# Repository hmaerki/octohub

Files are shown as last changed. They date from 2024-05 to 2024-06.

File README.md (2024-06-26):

# octohub

A simple usb 2.0 hub with focus on per port power switching.

Work in progress.

## Features - Hardware

* ~USD 4 when ordering 30 pieces. Fully assembled at JLCPCB.

* Kicad. Production files ready to upload to JLCPCB.

* Power control for each plug using (uhubctl)[https://github.com/mvp/uhubctl].

* **NO** manual power buttons. Many commercial hubs have buttons. If accidentely pressed, usb switching is disabled.

* Power LEDs which are visible from different angles. Many commercial switchs have LEDs, but not well visible.

* Plug numbering. Many commercial switches do not number the plugs and there is very little space left to add stickers.

## Features - Electronics

USB2 only. This makes `uhubctl` much faster.

Bus powered. Less cables is better.

USB descripter `self-powered`. This is against the USB spec. This is required as a RP2 requests 500mA. The USB 2.0 spec allows a bus-powered device to use max 100mA. The current measureed on the RP2 is only 25mA.

Over current protection. However, no over current feedback to USB.

If a device requires USB3, it is still possible to use a commercial hub.

## Current state of v0.2:

[Schematics](octohub_kicad_v0.2/production_v0.2/schematics.pdf)

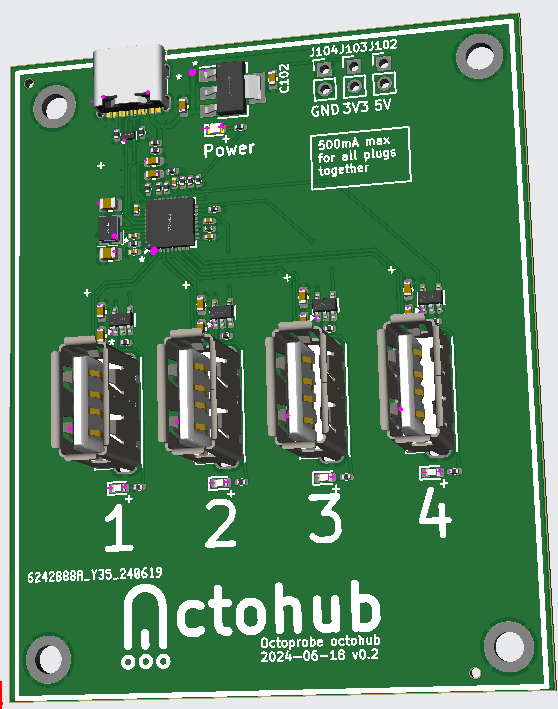
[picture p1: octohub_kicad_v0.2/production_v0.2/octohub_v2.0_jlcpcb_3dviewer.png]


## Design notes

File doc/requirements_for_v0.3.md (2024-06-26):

# Power consumtion

## RP2

| Mode | USB power descriptor | eff. power |
| - | - | - |
| Tentacle programming mode | 500 mA | 21 mA |
| SEEED run mode | 250 mA | ? |

Conclusion

One Tentacle with 1 RP2 programming and 1 RP2 run will draw 750A.

## Bus Power via selfpowered

### Bus Power

Limit 100mA, 500mA with tricks

### Self powered

Requires addition connection.

#### USB3 Powerered

* Standard cables
* USB Hub may be used as power supply

#### Custom Power cables

Variant a) Standard 6.5 mm

Power routing - USB 3

* Each tentacle has 2 USB 3 female connectors.
* The first tentacle need to be connected to a USB 3 supply.
* The followiing tentacles may be looped using USB 3 female-female cables.

Power routing - Octobus

* Some connections are reserved for 5 V power.

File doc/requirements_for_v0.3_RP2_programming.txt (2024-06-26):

Tentacle, programming mode

Bus 003 Device 060: ID 2e8a:0003 Raspberry Pi RP2 Boot
Device Descriptor:
  bLength                18
  bDescriptorType         1
  bcdUSB               1.10
  bDeviceClass            0 [unknown]
  bDeviceSubClass         0 [unknown]
  bDeviceProtocol         0 
  bMaxPacketSize0        64
  idVendor           0x2e8a Raspberry Pi
  idProduct          0x0003 RP2 Boot
  bcdDevice            1.00
  iManufacturer           1 Raspberry Pi
  iProduct                2 RP2 Boot
  iSerial                 3 E0C9125B0D9B
  bNumConfigurations      1
  Configuration Descriptor:
    bLength                 9
    bDescriptorType         2
    wTotalLength       0x0037
    bNumInterfaces          2
    bConfigurationValue     1
    iConfiguration          0 
    bmAttributes         0x80
      (Bus Powered)
    MaxPower              500mA
    Interface Descriptor:
      bLength                 9
      bDescriptorType         4
      bInterfaceNumber        0
      bAlternateSetting       0
      bNumEndpoints           2
      bInterfaceClass         8 Mass Storage
      bInterfaceSubClass      6 SCSI
      bInterfaceProtocol     80 Bulk-Only
      iInterface              0 
      Endpoint Descriptor:
        bLength                 7
        bDescriptorType         5
        bEndpointAddress     0x81  EP 1 IN
        bmAttributes            2
          Transfer Type            Bulk
          Synch Type               None
          Usage Type               Data
        wMaxPacketSize     0x0040  1x 64 bytes
        bInterval               0
      Endpoint Descriptor:
        bLength                 7
        bDescriptorType         5
        bEndpointAddress     0x02  EP 2 OUT
        bmAttributes            2
          Transfer Type            Bulk
          Synch Type               None
          Usage Type               Data
        wMaxPacketSize     0x0040  1x 64 bytes
        bInterval               0
    Interface Descriptor:
      bLength                 9
      bDescriptorType         4
      bInterfaceNumber        1
      bAlternateSetting       0
      bNumEndpoints           2
      bInterfaceClass       255 Vendor Specific Class
      bInterfaceSubClass      0 [unknown]
      bInterfaceProtocol      0 
      iInterface              0 
      Endpoint Descriptor:
        bLength                 7
        bDescriptorType         5
        bEndpointAddress     0x03  EP 3 OUT
        bmAttributes            2
          Transfer Type            Bulk
          Synch Type               None
          Usage Type               Data
        wMaxPacketSize     0x0040  1x 64 bytes
        bInterval               0
      Endpoint Descriptor:
        bLength                 7
        bDescriptorType         5
        bEndpointAddress     0x84  EP 4 IN
        bmAttributes            2
          Transfer Type            Bulk
          Synch Type               None
          Usage Type               Data
        wMaxPacketSize     0x0040  1x 64 bytes
        bInterval               0
Device Status:     0x0000
  (Bus Powered)

Bus 003 Device 065: ID 2e8a:0005 MicroPython Board in FS mode
Device Descriptor:
  bLength                18
  bDescriptorType         1
  bcdUSB               2.00
  bDeviceClass          239 Miscellaneous Device
  bDeviceSubClass         2 [unknown]
  bDeviceProtocol         1 Interface Association
  bMaxPacketSize0        64
  idVendor           0x2e8a MicroPython
  idProduct          0x0005 Board in FS mode
  bcdDevice            1.00
  iManufacturer           1 MicroPython
  iProduct                2 Board in FS mode
  iSerial                 3 4150325537323318
  bNumConfigurations      1
  Configuration Descriptor:
    bLength                 9
    bDescriptorType         2
    wTotalLength       0x004b
    bNumInterfaces          2
    bConfigurationValue     1
    iConfiguration          0 
    bmAttributes         0x80
      (Bus Powered)
    MaxPower              250mA
    Interface Association:
      bLength                 8
      bDescriptorType        11
      bFirstInterface         0
      bInterfaceCount         2
      bFunctionClass          2 Communications
      bFunctionSubClass       2 Abstract (modem)
      bFunctionProtocol       0 
      iFunction               0 
    Interface Descriptor:
      bLength                 9
      bDescriptorType         4
      bInterfaceNumber        0
      bAlternateSetting       0
      bNumEndpoints           1
      bInterfaceClass         2 Communications
      bInterfaceSubClass      2 Abstract (modem)
      bInterfaceProtocol      0 
      iInterface              4 Board CDC
      CDC Header:
        bcdCDC               1.20
      CDC Call Management:
        bmCapabilities       0x00
        bDataInterface          1
      CDC ACM:
        bmCapabilities       0x02
          line coding and serial state
      CDC Union:
        bMasterInterface        0
        bSlaveInterface         1 
      Endpoint Descriptor:
        bLength                 7
        bDescriptorType         5
        bEndpointAddress     0x81  EP 1 IN
        bmAttributes            3
          Transfer Type            Interrupt
          Synch Type               None
          Usage Type               Data
        wMaxPacketSize     0x0008  1x 8 bytes
        bInterval              16
    Interface Descriptor:
      bLength                 9
      bDescriptorType         4
      bInterfaceNumber        1
      bAlternateSetting       0
      bNumEndpoints           2
      bInterfaceClass        10 CDC Data
      bInterfaceSubClass      0 [unknown]
      bInterfaceProtocol      0 
      iInterface              0 
      Endpoint Descriptor:
        bLength                 7
        bDescriptorType         5
        bEndpointAddress     0x02  EP 2 OUT
        bmAttributes            2
          Transfer Type            Bulk
          Synch Type               None
          Usage Type               Data
        wMaxPacketSize     0x0040  1x 64 bytes
        bInterval               0
      Endpoint Descriptor:
        bLength                 7
        bDescriptorType         5
        bEndpointAddress     0x82  EP 2 IN
        bmAttributes            2
          Transfer Type            Bulk
          Synch Type               None
          Usage Type               Data
        wMaxPacketSize     0x0040  1x 64 bytes
        bInterval               0
Device Status:     0x0000
  (Bus Powered)

Bus 003 Device 066: ID f055:9800 MicroPython Pyboard Virtual Comm Port in FS Mode
Device Descriptor:
  bLength                18
  bDescriptorType         1
  bcdUSB               2.00
  bDeviceClass          239 Miscellaneous Device
  bDeviceSubClass         2 [unknown]
  bDeviceProtocol         1 Interface Association
  bMaxPacketSize0        64
  idVendor           0xf055 MicroPython
  idProduct          0x9800 Pyboard Virtual Comm Port in FS Mode
  bcdDevice            2.00
  iManufacturer           1 MicroPython
  iProduct                2 Pyboard Virtual Comm Port in FS Mode
  iSerial                 3 20853191464B
  bNumConfigurations      1
  Configuration Descriptor:
    bLength                 9
    bDescriptorType         2
    wTotalLength       0x0062
    bNumInterfaces          3
    bConfigurationValue     1
    iConfiguration          0 
    bmAttributes         0x80
      (Bus Powered)
    MaxPower              500mA
    Interface Descriptor:
      bLength                 9
      bDescriptorType         4
      bInterfaceNumber        0
      bAlternateSetting       0
      bNumEndpoints           2
      bInterfaceClass         8 Mass Storage
      bInterfaceSubClass      6 SCSI
      bInterfaceProtocol     80 Bulk-Only
      iInterface              0 
      Endpoint Descriptor:
        bLength                 7
        bDescriptorType         5
        bEndpointAddress     0x81  EP 1 IN
        bmAttributes            2
          Transfer Type            Bulk
          Synch Type               None
          Usage Type               Data
        wMaxPacketSize     0x0040  1x 64 bytes
        bInterval               0
      Endpoint Descriptor:
        bLength                 7
        bDescriptorType         5
        bEndpointAddress     0x01  EP 1 OUT
        bmAttributes            2
          Transfer Type            Bulk
          Synch Type               None
          Usage Type               Data
        wMaxPacketSize     0x0040  1x 64 bytes
        bInterval               0
    Interface Association:
      bLength                 8
      bDescriptorType        11
      bFirstInterface         1
      bInterfaceCount         2
      bFunctionClass          2 Communications
      bFunctionSubClass       2 Abstract (modem)
      bFunctionProtocol       1 AT-commands (v.25ter)
      iFunction               0 
    Interface Descriptor:
      bLength                 9
      bDescriptorType         4
      bInterfaceNumber        1
      bAlternateSetting       0
      bNumEndpoints           1
      bInterfaceClass         2 Communications
      bInterfaceSubClass      2 Abstract (modem)
      bInterfaceProtocol      1 AT-commands (v.25ter)
      iInterface              0 
      CDC Header:
        bcdCDC               1.10
      CDC Call Management:
        bmCapabilities       0x00
        bDataInterface          2
      CDC ACM:
        bmCapabilities       0x02
          line coding and serial state
      CDC Union:
        bMasterInterface        1
        bSlaveInterface         2 
      Endpoint Descriptor:
        bLength                 7
        bDescriptorType         5
        bEndpointAddress     0x82  EP 2 IN
        bmAttributes            3
          Transfer Type            Interrupt
          Synch Type               None
          Usage Type               Data
        wMaxPacketSize     0x0008  1x 8 bytes
        bInterval              32
    Interface Descriptor:
      bLength                 9
      bDescriptorType         4
      bInterfaceNumber        2
      bAlternateSetting       0
      bNumEndpoints           2
      bInterfaceClass        10 CDC Data
      bInterfaceSubClass      0 [unknown]
      bInterfaceProtocol      0 
      iInterface              0 
      Endpoint Descriptor:
        bLength                 7
        bDescriptorType         5
        bEndpointAddress     0x03  EP 3 OUT
        bmAttributes            2
          Transfer Type            Bulk
          Synch Type               None
          Usage Type               Data
        wMaxPacketSize     0x0040  1x 64 bytes
        bInterval               0
      Endpoint Descriptor:
        bLength                 7
        bDescriptorType         5
        bEndpointAddress     0x83  EP 3 IN
        bmAttributes            2
          Transfer Type            Bulk
          Synch Type               None
          Usage Type               Data
        wMaxPacketSize     0x0040  1x 64 bytes
        bInterval               0
Device Status:     0x0000
  (Bus Powered)

Bus 004 Device 001: ID 1d6b:0003 Linux Foundation 3.0 root hub
Device Descriptor:
  bLength                18
  bDescriptorType         1
  bcdUSB               3.10
  bDeviceClass            9 Hub
  bDeviceSubClass         0 [unknown]
  bDeviceProtocol         3 
  bMaxPacketSize0         9
  idVendor           0x1d6b Linux Foundation
  idProduct          0x0003 3.0 root hub
  bcdDevice            6.08
  iManufacturer           3 Linux 6.8.0-35-generic xhci-hcd
  iProduct                2 xHCI Host Controller
  iSerial                 1 0000:00:14.0
  bNumConfigurations      1
  Configuration Descriptor:
    bLength                 9
    bDescriptorType         2
    wTotalLength       0x001f
    bNumInterfaces          1
    bConfigurationValue     1
    iConfiguration          0 
    bmAttributes         0xe0
      Self Powered
      Remote Wakeup
    MaxPower                0mA
    Interface Descriptor:
      bLength                 9
      bDescriptorType         4
      bInterfaceNumber        0
      bAlternateSetting       0
      bNumEndpoints           1
      bInterfaceClass         9 Hub
      bInterfaceSubClass      0 [unknown]
      bInterfaceProtocol      0 Full speed (or root) hub
      iInterface              0 
      Endpoint Descriptor:
        bLength                 7
        bDescriptorType         5
        bEndpointAddress     0x81  EP 1 IN
        bmAttributes            3
          Transfer Type            Interrupt
          Synch Type               None
          Usage Type               Data
        wMaxPacketSize     0x0004  1x 4 bytes
        bInterval              12
        bMaxBurst               0
Binary Object Store Descriptor:
  bLength                 5
  bDescriptorType        15
  wTotalLength       0x005b
  bNumDeviceCaps          2
  SuperSpeed USB Device Capability:
    bLength                10
    bDescriptorType        16
    bDevCapabilityType      3
    bmAttributes         0x02
      Latency Tolerance Messages (LTM) Supported
    wSpeedsSupported   0x0008
      Device can operate at SuperSpeed (5Gbps)
    bFunctionalitySupport   1
      Lowest fully-functional device speed is Full Speed (12Mbps)
    bU1DevExitLat          10 micro seconds
    bU2DevExitLat         160 micro seconds
  SuperSpeedPlus USB Device Capability:
    bLength                76
    bDescriptorType        16
    bDevCapabilityType     10
    bmAttributes         0x000000ef
      Sublink Speed Attribute count 16
      Sublink Speed ID count 8
    wFunctionalitySupport   0x1106
      Min functional Speed Attribute ID: 6
      Min functional RX lanes: 1
      Min functional TX lanes: 1
    bmSublinkSpeedAttr[0]   0x00050034
      Speed Attribute ID: 4 5Gb/s Symmetric RX SuperSpeed
    bmSublinkSpeedAttr[1]   0x000500b4
      Speed Attribute ID: 4 5Gb/s Symmetric TX SuperSpeed
    bmSublinkSpeedAttr[2]   0x000a4035
      Speed Attribute ID: 5 10Gb/s Symmetric RX SuperSpeedPlus
    bmSublinkSpeedAttr[3]   0x000a40b5
      Speed Attribute ID: 5 10Gb/s Symmetric TX SuperSpeedPlus
    bmSublinkSpeedAttr[4]   0x00e00026
      Speed Attribute ID: 6 224Mb/s Symmetric RX SuperSpeed
    bmSublinkSpeedAttr[5]   0x00e000a6
      Speed Attribute ID: 6 224Mb/s Symmetric TX SuperSpeed
    bmSublinkSpeedAttr[6]   0x00c00027
      Speed Attribute ID: 7 192Mb/s Symmetric RX SuperSpeed
    bmSublinkSpeedAttr[7]   0x00c000a7
      Speed Attribute ID: 7 192Mb/s Symmetric TX SuperSpeed
    bmSublinkSpeedAttr[8]   0x00800028
      Speed Attribute ID: 8 128Mb/s Symmetric RX SuperSpeed
    bmSublinkSpeedAttr[9]   0x008000a8
      Speed Attribute ID: 8 128Mb/s Symmetric TX SuperSpeed
    bmSublinkSpeedAttr[10]   0x00b10029
      Speed Attribute ID: 9 177Mb/s Symmetric RX SuperSpeed
    bmSublinkSpeedAttr[11]   0x00b100a9
      Speed Attribute ID: 9 177Mb/s Symmetric TX SuperSpeed
    bmSublinkSpeedAttr[12]   0x0063002a
      Speed Attribute ID: 10 99Mb/s Symmetric RX SuperSpeed
    bmSublinkSpeedAttr[13]   0x006300aa
      Speed Attribute ID: 10 99Mb/s Symmetric TX SuperSpeed
    bmSublinkSpeedAttr[14]   0x00c6002b
      Speed Attribute ID: 11 198Mb/s Symmetric RX SuperSpeed
    bmSublinkSpeedAttr[15]   0x00c600ab
      Speed Attribute ID: 11 198Mb/s Symmetric TX SuperSpeed
Hub Descriptor:
  bLength              12
  bDescriptorType      42
  nNbrPorts             4
  wHubCharacteristic 0x000a
    No power switching (usb 1.0)
    Per-port overcurrent protection
  bPwrOn2PwrGood       50 * 2 milli seconds
  bHubContrCurrent      0 milli Ampere
  bHubDecLat          0.0 micro seconds
  wHubDelay             0 nano seconds
  DeviceRemovable    0x00
 Hub Port Status:
   Port 1: 0000.0263 5Gbps power suspend enable connect
     Ext Status: 0000.0044
       RX Speed Attribute ID: 4 Lanes: 1
       TX Speed Attribute ID: 4 Lanes: 1
   Port 2: 0000.02a0 5Gbps power Rx.Detect
   Port 3: 0000.02a0 5Gbps power Rx.Detect
   Port 4: 0000.02a0 5Gbps power Rx.Detect
Device Status:     0x0001
  Self Powered

Bus 004 Device 002: ID 0bda:0411 Realtek Semiconductor Corp. Hub
Device Descriptor:
  bLength                18
  bDescriptorType         1
  bcdUSB               3.20
  bDeviceClass            9 Hub
  bDeviceSubClass         0 [unknown]
  bDeviceProtocol         3 
  bMaxPacketSize0         9
  idVendor           0x0bda Realtek Semiconductor Corp.
  idProduct          0x0411 Hub
  bcdDevice            0.04
  iManufacturer           1 Generic
  iProduct                2 USB3.2 Hub
  iSerial                 0 
  bNumConfigurations      1
  Configuration Descriptor:
    bLength                 9
    bDescriptorType         2
    wTotalLength       0x001f
    bNumInterfaces          1
    bConfigurationValue     1
    iConfiguration          0 
    bmAttributes         0xe0
      Self Powered
      Remote Wakeup
    MaxPower                0mA
    Interface Descriptor:
      bLength                 9
      bDescriptorType         4
      bInterfaceNumber        0
      bAlternateSetting       0
      bNumEndpoints           1
      bInterfaceClass         9 Hub
      bInterfaceSubClass      0 [unknown]
      bInterfaceProtocol      0 Full speed (or root) hub
      iInterface              0 
      Endpoint Descriptor:
        bLength                 7
        bDescriptorType         5
        bEndpointAddress     0x81  EP 1 IN
        bmAttributes           19
          Transfer Type            Interrupt
          Synch Type               None
          Usage Type               Feedback
        wMaxPacketSize     0x0002  1x 2 bytes
        bInterval               8
        bMaxBurst               0
Binary Object Store Descriptor:
  bLength                 5
  bDescriptorType        15
  wTotalLength       0x002a
  bNumDeviceCaps          3
  USB 2.0 Extension Device Capability:
    bLength                 7
    bDescriptorType        16
    bDevCapabilityType      2
    bmAttributes   0x0000f41e
      BESL Link Power Management (LPM) Supported
    BESL value     1024 us 
    Deep BESL value    61440 us 
  SuperSpeed USB Device Capability:
    bLength                10
    bDescriptorType        16
    bDevCapabilityType      3
    bmAttributes         0x00
    wSpeedsSupported   0x000e
      Device can operate at Full Speed (12Mbps)
      Device can operate at High Speed (480Mbps)
      Device can operate at SuperSpeed (5Gbps)
    bFunctionalitySupport   1
      Lowest fully-functional device speed is Full Speed (12Mbps)
    bU1DevExitLat          10 micro seconds
    bU2DevExitLat        1023 micro seconds
  Container ID Device Capability:
    bLength                20
    bDescriptorType        16
    bDevCapabilityType      4
    bReserved               0
    ContainerID             {20b9cde5-7039-e011-a935-0002a5d5c51b}
Hub Descriptor:
  bLength              12
  bDescriptorType      42
  nNbrPorts             4
  wHubCharacteristic 0x0009
    Per-port power switching
    Per-port overcurrent protection
  bPwrOn2PwrGood        0 * 2 milli seconds
  bHubContrCurrent      8 milli Ampere
  bHubDecLat          0.2 micro seconds
  wHubDelay          3202 nano seconds
  DeviceRemovable    0x00
 Hub Port Status:
   Port 1: 0000.02a0 5Gbps power Rx.Detect
   Port 2: 0000.02a0 5Gbps power Rx.Detect
   Port 3: 0000.0263 5Gbps power suspend enable connect
   Port 4: 0000.0263 5Gbps power suspend enable connect
Device Status:     0x000d
  Self Powered
  U1 Enabled
  U2 Enabled

Bus 004 Device 003: ID 0bda:0411 Realtek Semiconductor Corp. Hub
Device Descriptor:
  bLength                18
  bDescriptorType         1
  bcdUSB               3.20
  bDeviceClass            9 Hub
  bDeviceSubClass         0 [unknown]
  bDeviceProtocol         3 
  bMaxPacketSize0         9
  idVendor           0x0bda Realtek Semiconductor Corp.
  idProduct          0x0411 Hub
  bcdDevice            0.04
  iManufacturer           1 Generic
  iProduct                2 USB3.2 Hub
  iSerial                 0 
  bNumConfigurations      1
  Configuration Descriptor:
    bLength                 9
    bDescriptorType         2
    wTotalLength       0x001f
    bNumInterfaces          1
    bConfigurationValue     1
    iConfiguration          0 
    bmAttributes         0xe0
      Self Powered
      Remote Wakeup
    MaxPower                0mA
    Interface Descriptor:
      bLength                 9
      bDescriptorType         4
      bInterfaceNumber        0
      bAlternateSetting       0
      bNumEndpoints           1
      bInterfaceClass         9 Hub
      bInterfaceSubClass      0 [unknown]
      bInterfaceProtocol      0 Full speed (or root) hub
      iInterface              0 
      Endpoint Descriptor:
        bLength                 7
        bDescriptorType         5
        bEndpointAddress     0x81  EP 1 IN
        bmAttributes           19
          Transfer Type            Interrupt
          Synch Type               None
          Usage Type               Feedback
        wMaxPacketSize     0x0002  1x 2 bytes
        bInterval               8
        bMaxBurst               0
Binary Object Store Descriptor:
  bLength                 5
  bDescriptorType        15
  wTotalLength       0x002a
  bNumDeviceCaps          3
  USB 2.0 Extension Device Capability:
    bLength                 7
    bDescriptorType        16
    bDevCapabilityType      2
    bmAttributes   0x0000f41e
      BESL Link Power Management (LPM) Supported
    BESL value     1024 us 
    Deep BESL value    61440 us 
  SuperSpeed USB Device Capability:
    bLength                10
    bDescriptorType        16
    bDevCapabilityType      3
    bmAttributes         0x00
    wSpeedsSupported   0x000e
      Device can operate at Full Speed (12Mbps)
      Device can operate at High Speed (480Mbps)
      Device can operate at SuperSpeed (5Gbps)
    bFunctionalitySupport   1
      Lowest fully-functional device speed is Full Speed (12Mbps)
    bU1DevExitLat          10 micro seconds
    bU2DevExitLat        1023 micro seconds
  Container ID Device Capability:
    bLength                20
    bDescriptorType        16
    bDevCapabilityType      4
    bReserved               0
    ContainerID             {20b9cde5-7039-e011-a935-0002a5d5c51b}
Hub Descriptor:
  bLength              12
  bDescriptorType      42
  nNbrPorts             4
  wHubCharacteristic 0x0009
    Per-port power switching
    Per-port overcurrent protection
  bPwrOn2PwrGood        0 * 2 milli seconds
  bHubContrCurrent      8 milli Ampere
  bHubDecLat          0.2 micro seconds
  wHubDelay          3202 nano seconds
  DeviceRemovable    0x00
 Hub Port Status:
   Port 1: 0000.02a0 5Gbps power Rx.Detect
   Port 2: 0000.02a0 5Gbps power Rx.Detect
   Port 3: 0000.02a0 5Gbps power Rx.Detect
   Port 4: 0000.02a0 5Gbps power Rx.Detect
Device Status:     0x000d
  Self Powered
  U1 Enabled
  U2 Enabled

Bus 004 Device 004: ID 0bda:0411 Realtek Semiconductor Corp. Hub
Device Descriptor:
  bLength                18
  bDescriptorType         1
  bcdUSB               3.20
  bDeviceClass            9 Hub
  bDeviceSubClass         0 [unknown]
  bDeviceProtocol         3 
  bMaxPacketSize0         9
  idVendor           0x0bda Realtek Semiconductor Corp.
  idProduct          0x0411 Hub
  bcdDevice            0.04
  iManufacturer           1 Generic
  iProduct                2 USB3.2 Hub
  iSerial                 0 
  bNumConfigurations      1
  Configuration Descriptor:
    bLength                 9
    bDescriptorType         2
    wTotalLength       0x001f
    bNumInterfaces          1
    bConfigurationValue     1
    iConfiguration          0 
    bmAttributes         0xe0
      Self Powered
      Remote Wakeup
    MaxPower                0mA
    Interface Descriptor:
      bLength                 9
      bDescriptorType         4
      bInterfaceNumber        0
      bAlternateSetting       0
      bNumEndpoints           1
      bInterfaceClass         9 Hub
      bInterfaceSubClass      0 [unknown]
      bInterfaceProtocol      0 Full speed (or root) hub
      iInterface              0 
      Endpoint Descriptor:
        bLength                 7
        bDescriptorType         5
        bEndpointAddress     0x81  EP 1 IN
        bmAttributes           19
          Transfer Type            Interrupt
          Synch Type               None
          Usage Type               Feedback
        wMaxPacketSize     0x0002  1x 2 bytes
        bInterval               8
        bMaxBurst               0
Binary Object Store Descriptor:
  bLength                 5
  bDescriptorType        15
  wTotalLength       0x002a
  bNumDeviceCaps          3
  USB 2.0 Extension Device Capability:
    bLength                 7
    bDescriptorType        16
    bDevCapabilityType      2
    bmAttributes   0x0000f41e
      BESL Link Power Management (LPM) Supported
    BESL value     1024 us 
    Deep BESL value    61440 us 
  SuperSpeed USB Device Capability:
    bLength                10
    bDescriptorType        16
    bDevCapabilityType      3
    bmAttributes         0x00
    wSpeedsSupported   0x000e
      Device can operate at Full Speed (12Mbps)
      Device can operate at High Speed (480Mbps)
      Device can operate at SuperSpeed (5Gbps)
    bFunctionalitySupport   1
      Lowest fully-functional device speed is Full Speed (12Mbps)
    bU1DevExitLat          10 micro seconds
    bU2DevExitLat        1023 micro seconds
  Container ID Device Capability:
    bLength                20
    bDescriptorType        16
    bDevCapabilityType      4
    bReserved               0
    ContainerID             {20b9cde5-7039-e011-a935-0002a5d5c51b}
Hub Descriptor:
  bLength              12
  bDescriptorType      42
  nNbrPorts             4
  wHubCharacteristic 0x0009
    Per-port power switching
    Per-port overcurrent protection
  bPwrOn2PwrGood        0 * 2 milli seconds
  bHubContrCurrent      8 milli Ampere
  bHubDecLat          0.2 micro seconds
  wHubDelay          3202 nano seconds
  DeviceRemovable    0x00
 Hub Port Status:
   Port 1: 0000.02a0 5Gbps power Rx.Detect
   Port 2: 0000.02a0 5Gbps power Rx.Detect
   Port 3: 0000.02a0 5Gbps power Rx.Detect
   Port 4: 0000.02a0 5Gbps power Rx.Detect
Device Status:     0x000d
  Self Powered
  U1 Enabled
  U2 Enabled

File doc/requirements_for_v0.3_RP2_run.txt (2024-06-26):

RP2 SEEED

[   97.388628] usb 3-1: new full-speed USB device number 5 using xhci_hcd
[   97.517740] usb 3-1: New USB device found, idVendor=2e8a, idProduct=0005, bcdDevice= 1.00
[   97.517780] usb 3-1: New USB device strings: Mfr=1, Product=2, SerialNumber=3
[   97.517784] usb 3-1: Product: Board in FS mode
[   97.517787] usb 3-1: Manufacturer: MicroPython
[   97.517790] usb 3-1: SerialNumber: 4150325537323318
[   97.551115] cdc_acm 3-1:1.0: ttyACM0: USB ACM device
[   97.551186] usbcore: registered new interface driver cdc_acm
[   97.551192] cdc_acm: USB Abstract Control Model driver for USB modems and ISDN adapters

root@maerki-ideapad-320:/tmp# lsusb -tv
/:  Bus 001.Port 001: Dev 001, Class=root_hub, Driver=xhci_hcd/1p, 480M
    ID 1d6b:0002 Linux Foundation 2.0 root hub
/:  Bus 002.Port 001: Dev 001, Class=root_hub, Driver=xhci_hcd/4p, 10000M
    ID 1d6b:0003 Linux Foundation 3.0 root hub
/:  Bus 003.Port 001: Dev 001, Class=root_hub, Driver=xhci_hcd/12p, 480M
    ID 1d6b:0002 Linux Foundation 2.0 root hub
    |__ Port 001: Dev 005, If 0, Class=Communications, Driver=cdc_acm, 12M    <===============
        ID 2e8a:0005  
    |__ Port 001: Dev 005, If 1, Class=CDC Data, Driver=cdc_acm, 12M
        ID 2e8a:0005  
    |__ Port 003: Dev 002, If 0, Class=Vendor Specific Class, Driver=[none], 12M
        ID 06cb:00f9 Synaptics, Inc. 
    |__ Port 004: Dev 003, If 0, Class=Video, Driver=uvcvideo, 480M
        ID 13d3:5405 IMC Networks 
    |__ Port 004: Dev 003, If 1, Class=Video, Driver=uvcvideo, 480M
        ID 13d3:5405 IMC Networks 
    |__ Port 004: Dev 003, If 2, Class=Video, Driver=uvcvideo, 480M
        ID 13d3:5405 IMC Networks 
    |__ Port 004: Dev 003, If 3, Class=Video, Driver=uvcvideo, 480M
        ID 13d3:5405 IMC Networks 
    |__ Port 004: Dev 003, If 4, Class=Application Specific Interface, Driver=[none], 480M
        ID 13d3:5405 IMC Networks 
/:  Bus 004.Port 001: Dev 001, Class=root_hub, Driver=xhci_hcd/4p, 10000M
    ID 1d6b:0003 Linux Foundation 3.0 root hub

Bus 003 Device 005: ID 2e8a:0005 MicroPython Board in FS mode
Device Descriptor:
  bLength                18
  bDescriptorType         1
  bcdUSB               2.00
  bDeviceClass          239 Miscellaneous Device
  bDeviceSubClass         2 [unknown]
  bDeviceProtocol         1 Interface Association
  bMaxPacketSize0        64
  idVendor           0x2e8a MicroPython
  idProduct          0x0005 Board in FS mode
  bcdDevice            1.00
  iManufacturer           1 MicroPython
  iProduct                2 Board in FS mode
  iSerial                 3 4150325537323318
  bNumConfigurations      1
  Configuration Descriptor:
    bLength                 9
    bDescriptorType         2
    wTotalLength       0x004b
    bNumInterfaces          2
    bConfigurationValue     1
    iConfiguration          0 
    bmAttributes         0x80
      (Bus Powered)
    MaxPower              250mA
    Interface Association:
      bLength                 8
      bDescriptorType        11
      bFirstInterface         0
      bInterfaceCount         2
      bFunctionClass          2 Communications
      bFunctionSubClass       2 Abstract (modem)
      bFunctionProtocol       0 
      iFunction               0 
    Interface Descriptor:
      bLength                 9
      bDescriptorType         4
      bInterfaceNumber        0
      bAlternateSetting       0
      bNumEndpoints           1
      bInterfaceClass         2 Communications
      bInterfaceSubClass      2 Abstract (modem)
      bInterfaceProtocol      0 
      iInterface              4 Board CDC
      CDC Header:
        bcdCDC               1.20
      CDC Call Management:
        bmCapabilities       0x00
        bDataInterface          1
      CDC ACM:
        bmCapabilities       0x02
          line coding and serial state
      CDC Union:
        bMasterInterface        0
        bSlaveInterface         1 
      Endpoint Descriptor:
        bLength                 7
        bDescriptorType         5
        bEndpointAddress     0x81  EP 1 IN
        bmAttributes            3
          Transfer Type            Interrupt
          Synch Type               None
          Usage Type               Data
        wMaxPacketSize     0x0008  1x 8 bytes
        bInterval              16
    Interface Descriptor:
      bLength                 9
      bDescriptorType         4
      bInterfaceNumber        1
      bAlternateSetting       0
      bNumEndpoints           2
      bInterfaceClass        10 CDC Data
      bInterfaceSubClass      0 [unknown]
      bInterfaceProtocol      0 
      iInterface              0 
      Endpoint Descriptor:
        bLength                 7
        bDescriptorType         5
        bEndpointAddress     0x02  EP 2 OUT
        bmAttributes            2
          Transfer Type            Bulk
          Synch Type               None
          Usage Type               Data
        wMaxPacketSize     0x0040  1x 64 bytes
        bInterval               0
      Endpoint Descriptor:
        bLength                 7
        bDescriptorType         5
        bEndpointAddress     0x82  EP 2 IN
        bmAttributes            2
          Transfer Type            Bulk
          Synch Type               None
          Usage Type               Data
        wMaxPacketSize     0x0040  1x 64 bytes
        bInterval               0
Device Status:     0x0000
  (Bus Powered)

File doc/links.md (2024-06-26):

## Sparkfun

https://github.com/sparkfunX/Qwiic_USB_Hub-USB2514B
https://www.sparkfun.com/products/18014
Known Issues: The power control MOSFETs on this version (x02) are not functional. While each port is on by default, they cannot be turned off in software.

[Schematics](https://github.com/sparkfunX/Qwiic_USB_Hub-USB2514B/blob/main/Hardware/Qwiic-USB_Hub.pdf)

## Carrier board for the Raspberry Pi Compute Module

https://hackaday.io/project/165108-carrier-board-for-the-raspberry-pi-compute-module

BOM: https://cdn.hackaday.io/files/1651087063980672/BOM.xlsx

## Microchip

* https://www.microchip.com/en-us/product/usb2514b
* https://ww1.microchip.com/downloads/aemDocuments/documents/OTH/ProductDocuments/DataSheets/00001692C.pdf

* (Layout Guilde)[https://ww1.microchip.com/downloads/aemDocuments/documents/OTH/ApplicationNotes/ApplicationNotes/en562810.pdf]

### Eval board EVB-USB2514B-FS FULL SPEED (12Mbits/s)
* (EVB-USB2514B-FS)[https://www.microchip.com/en-us/development-tool/evb-usb2514b-fs]
* (Schematics)[https://ww1.microchip.com/downloads/aemDocuments/documents/OTH/ProductDocuments/BoardDesignFiles/EVB-USB2514B-FS_A1EvaluationBoardSchematicPDF.pdf]
* (BOM)[https://ww1.microchip.com/downloads/aemDocuments/documents/OTH/ProductDocuments/BoardDesignFiles/EVB-USB2514B-FS_A1EvaluationBoardBillofMaterials.xls]

### Eval board EVB-USB2514BC HIGH SPEED (480Mbits/s)
* (EVB-USB2514BC)[https://www.microchip.com/en-us/development-tool/EVB-USB2514BC] 
* (Schematics)[https://ww1.microchip.com/downloads/aemDocuments/documents/OTH/ProductDocuments/BoardDesignFiles/EVB-USB2514BC_A3-sch.pdf]
* (BOM)[https://ww1.microchip.com/downloads/aemDocuments/documents/OTH/ProductDocuments/BoardDesignFiles/EVB-USB2514BC_A3-Bom.xls]

### Seeed - reTerminal

* (Intro)[https://wiki.seeedstudio.com/reTerminal_Intro]
* (Schematics)[https://files.seeedstudio.com/wiki/ReTerminal/reTerminal-v1.3_SCH.pdf]

### PcbWay

https://www.pcbway.com/project/shareproject/USB2514_HUB.html

## USB

https://www.cuidevices.com/blog/an-introduction-to-power-only-usb-type-c-connectors

https://en.wikipedia.org/wiki/USB-C

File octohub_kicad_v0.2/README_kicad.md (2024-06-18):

# Plugins used

* https://github.com/bennymeg/JLC-Plugin-for-KiCad

  JLC PCB Plug-in for KiCad

  Fill Symbol Field `JLC Part`

* https://github.com/MitjaNemec/ReplicateLayout

## Protype Baord

### Precondition

...

## Hierarchical sheet

* https://forum.kicad.info/t/variables-in-hierarchical-sheet-labels/41978

In pcb, place all relais footprints (silkscreen) correctly.

Select first pcb, `Tools -> External Plugins -> Replicate Layout`

## Replicate Layout

* Reference Layout `pcb_octohub_cip.kicad_sch`: `chip_upstream`
  * Reference footprint: USB Chip
  * UR201 `+` spawns the top left corner

* Reference Layout `pcb_octohub_plug.kicad_sch`: `hub4-1/plug_A`
  * Reference footprint: Plug
  * UR1201 is the plug label
  * UR1202 `+` spawns the top left corner

* Reference Layout `pcb_octohub_hub4.kicad_sch`: `hub4-1`
  * Reference footprint: UR1001 `+`
  * UR1001 `+` spawns the top left corner

## Production

### In schematics

Menu `Inspect -> Electrical Rule Chacker`, button `Run ERC`, No violatons

### Increment version number

Update in all sheets

### In pcb - final check and final commit

Menu `Tools -> Update PCB from Schematic`, only one error `Error: Multiple footprings found for 'PB101'`

Menu `Tools -> Cleanup Tracks & Vias`, select all,  `Build Changes`, No violatons

Menu `Inspect -> Design Rules Chacker`, check `Refill all zones`, button `Run DRC . No errors, no warnings.

Delete all files in directory `production`.

Icon `Fabricaton Toolkit`, Options empty, check `Apply automatic translatons`, UNcheck `Exluce DNP components`.

Rename production folder and add version number

### Print schematics

Schematics, Menu `File -> Print`, check 'Print drawing sheet - Color`, `Print`, `All Pages`, `Pirnt to File`.

Move `~/Documents/output.pdf` to `hardware/octoprobe_kicad_v1/production_v2.0/schematics.pdf`

### Upload to JLCPCB

See: octohub_kicad_v0.2/production_v0.2/README_production_v0.2.md

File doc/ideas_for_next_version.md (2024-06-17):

# Ideas

## 4 port hub versus 16 port hub

| 4 port | 16 port | Comment |
| :-: | :-: | - |
| | no usb configuration | uhubctl |
| simple| | Kicad project / jlcpcb order |
| more power | | upstream hub may support power |
| | simple, one pcb | Mechanics |
| flexible | | octoprobe arrangement |
| | plugs numbered from 1..16 | octoprobe arrangement |
| multipe power switches | | Power |

## Multiple power switches

* separate MT9700
* PRTPWR connects to MT9700
* MT9700 VIN: Experiment Plugs
* MT9700 VOUT: Experiment Plugs

According to datasheet
* VIN must be provided: 3V3 or 5V
* Max current: 2A

==> Goal: Switch

## Evaluate Relais

* Octoprobe
  * GAQY221S
  * https://wmsc.lcsc.com/wmsc/upload/file/pdf/v2/lcsc/2308151358_SUPSiC-GAQY221S_C7435105.pdf
  * USD 055

JLC search: `solid state relay MOS supsic`

| JLC |  USD | U Load R | Type | Datasheet |
| :-: | :-: | :-: | - | - |
| C393898 | 1.9 | 60V 1A 250m | TOSHIBA TLP3122(TP,F) | https://wmsc.lcsc.com/wmsc/upload/file/pdf/v2/lcsc/1912111437_TOSHIBA-TLP3122-TP-F_C393898.pdf |
| C19271987 | 0.6 | 60V 1.8A 70m | SUPSiC GAQY212GHA | https://wmsc.lcsc.com/wmsc/upload/file/pdf/v2/lcsc/2403241735_SUPSiC-GAQY212GHA_C19271987.pdf |
| C192C743510471987 | 0.74 | 40V 2.5A 60m | SUPSiC GAQY211G2S | https://wmsc.lcsc.com/wmsc/upload/file/pdf/v2/lcsc/2308151358_SUPSiC-GAQY211G2S_C7435104.pdf |

## Other open source hub. USB2, tested with uhubctl.

https://oshwlab.com/iamseer/ch335-hub

CH335F, jlc C5137013, USD 1.2

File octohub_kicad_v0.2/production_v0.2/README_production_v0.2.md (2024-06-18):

JLCPCB: Error while uploading : The below parts won't be assembled due to data missing.
H102,H101,H104,H103 designators don't exist in the CPL file.

JLCPCB: Postprocess
 * Rotate U101, U1101

Price

| Qty | Total USD | Unit USD |
| :-: | :-: | :-: |
| 5 | 48 | 9.6 |
| 10 | 63 | 6.3 |
| 20 | 100 | 10 |
| 30 | 130 | 4.3 |

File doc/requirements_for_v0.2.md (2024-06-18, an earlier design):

# Requirements for v0.2

## Design

* Selfpowered via USBC connector. See (schematics)[https://ww1.microchip.com/downloads/aemDocuments/documents/OTH/ProductDocuments/BoardDesignFiles/EVB-USB2514B-FS_A1EvaluationBoardSchematicPDF.pdf]
* 1 Hub per PCB
* PCB may be connected to Multihub

## Measuring

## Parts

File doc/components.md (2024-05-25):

## XTAL

### https://ww1.microchip.com/downloads/aemDocuments/documents/OTH/ProductDocuments/BoardDesignFiles/EVB-USB2514BC_A3-Bom.xls

`Y1	Crystal, 24.000MHz, 50ppm, 18pF, HC-49SMT	Citizen America	HCM49-24.000MABJ-UT`

==> JLC not available

### https://ww1.microchip.com/downloads/aemDocuments/documents/OTH/ProductDocuments/BoardDesignFiles/EVB-USB2514BC_A3-Bom.xls

`Y1	Crystal, 24.000MHz, 50ppm, 18pF, HC-49SMT	Citizen America	HCM49-24.000MABJ-UT`

==> JLC not available

### https://ww1.microchip.com/downloads/aemDocuments/documents/OTH/ProductDocuments/DataSheets/00001692C.pdf

```
7.1 Oscillator/Crystal
Crystal: Parallel resonant, fundamental mode, 24 MHz 350 ppm
```

https://jlcpcb.com/partdetail/Yxc-X322524MOB4SI/C70590

`24MHz Surface mount crystal oscillator 12pF ±10ppm ±20ppm SMD3225-4P Crystals ROHS`

## USB Connector

* C456015: Only 2 supporting pads. No kicad footprint
  * 20k Stock, USD 0.03

* https://jlcpcb.com/partdetail/Molex-1050570001/C586225
  * 18 Stock, USD 0.6

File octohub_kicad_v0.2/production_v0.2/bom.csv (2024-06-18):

Designator | Footprint | Quantity | Value | LCSC Part #
C101, C102, C1201, C1202, C1301, C1302, C1401, C1402, C1501, C1502 | 0603 | 10 | 10u
C103, C1102 | 0603 | 2 | 100n
C1101, C1103, C1104, C1105 | 0402 | 4 | 100n
C1106, C1107 | 0805 | 2 | 18p | C1797
C1108, C1109 | 0402 | 2 | 0.1u
D101 | Texas_USON-6_1x1.45mm_P0.5mm_SMD | 1 | PRTR5V0U2X | C2937001
D102 | 0603 | 1 | LED GREEN | C2297
D1201, D1301, D1401, D1501 | 0603 | 4 | LED WHITE | C2290
H101, H102, H103, H104 | MountingHole_3.2mm_M3_DIN965_Pad | 4 | octoprobe_MountingHole
J101 | USB_C_Receptacle_Palconn_UTC16-G | 1 | USB_C_Receptacle_USB2.0 | C165948
J1201, J1301, J1401, J1501 | USB_A_SHOUHAN_Vertical | 4 | USB_A | C456015
R101, R102 | 0402 | 2 | 5.1K
R103, R104, R1101, R1102, R1103, R1105 | 0402 | 6 | 100k
R105 | 0402 | 1 | 470R
R1104 | 0402 | 1 | 12k
R1106, R1107, R1108, R1109, R1110, R1201, R1301, R1401, R1501 | 0402 | 9 | 10k
R1202, R1302, R1402, R1502 | 0402 | 4 | 1k
U101 | SOT-223-3_TabPin2 | 1 | AMS1117-3.3 | C6186
U1101 | Texas_RHH0036C_VQFN-36-1EP_6x6mm_P0.5mm_EP4.4x4.4mm_ThermalVias | 1 | USB2514B_Bi | C16251
U1201, U1301, U1401, U1501 | SOT-23-5 | 4 | MT9700 | C89855
Y1101 | Crystal_SMD_3225-4Pin_3.2x2.5mm | 1 | 24MHz | C70590

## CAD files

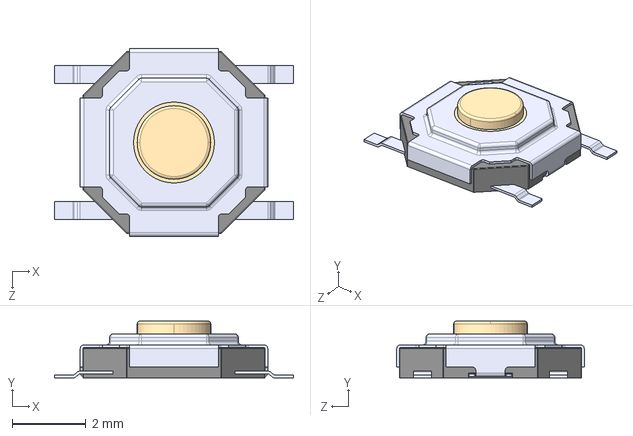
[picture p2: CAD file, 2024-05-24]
octohub_kicad_v0.2/00_project_parts/bizcard/footprints/TS-1187A-B-A-B.step
6.50 x 1.55 x 5.10 mm

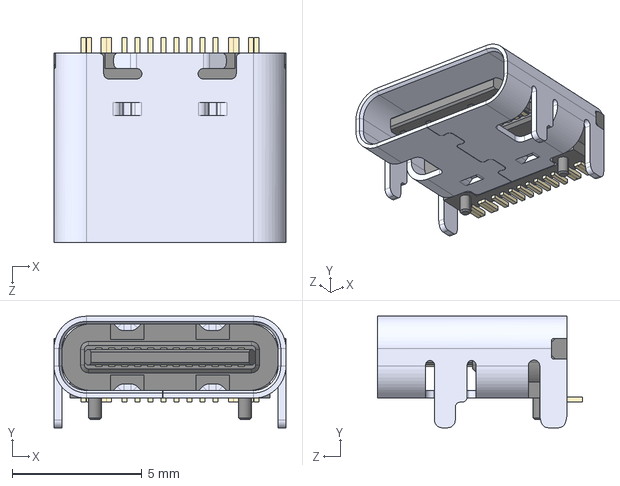
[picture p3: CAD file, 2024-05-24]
octohub_kicad_v0.2/00_project_parts/bizcard/footprints/TYPE-C-31-M-12--3DModel-STEP-56544.STEP
8.94 x 4.30 x 7.90 mm

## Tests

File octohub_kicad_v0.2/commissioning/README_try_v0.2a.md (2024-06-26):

# Commisioning

Serial 1: Remove R1106 (CFG_SEL[1])

Now the hub is self-powered!

## CFG_SEL[1], pin 25

Currently: `0 self powererd`
New: `1 bus powered`

## Observations

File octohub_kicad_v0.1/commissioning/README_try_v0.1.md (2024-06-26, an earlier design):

# Commisioning

Serial 1. Remove R212 (failed to add R208)

`sudo dmesg --follow`

```
[  962.101187] usb 3-1: new high-speed USB device number 28 using xhci_hcd
[  962.228270] usb 3-1: New USB device found, idVendor=0424, idProduct=2514, bcdDevice= b.b3
[  962.228276] usb 3-1: New USB device strings: Mfr=0, Product=0, SerialNumber=0
[  962.229811] hub 3-1:1.0: USB hub found
[  962.229854] hub 3-1:1.0: 4 ports detected
```

`sudo uhubctl`

```
Current status for hub 3-5.3 [0424:2514, USB 2.00, 4 ports, ppps]
  Port 1: 0103 power enable connect [2e8a:0003 Raspberry Pi RP2 Boot E0C9125B0D9B]
  Port 2: 0103 power enable connect [2e8a:0005 MicroPython Board in FS mode 4150325537323318]
  Port 3: 0100 power
  Port 4: 0100 power
```

```bash
uhubctl -l 3-5.3 --action=on
Current status for hub 3-5.3 [0424:2514, USB 2.00, 4 ports, ppps]
  Port 1: 0000 off
  Port 2: 0000 off
  Port 3: 0000 off
  Port 4: 0000 off
Sent power on request
New status for hub 3-5.3 [0424:2514, USB 2.00, 4 ports, ppps]
  Port 1: 0100 power
  Port 2: 0100 power
  Port 3: 0100 power
  Port 4: 0100 power
```

`lsusb -v`

```
Bus 003 Device 025: ID 0424:2514 Microchip Technology, Inc. (formerly SMSC) USB 2.0 Hub
Device Descriptor:
  bLength                18
  bDescriptorType         1
  bcdUSB               2.00
  bDeviceClass            9 Hub
  bDeviceSubClass         0 [unknown]
  bDeviceProtocol         2 TT per port
  bMaxPacketSize0        64
  idVendor           0x0424 Microchip Technology, Inc. (formerly SMSC)
  idProduct          0x2514 USB 2.0 Hub
  bcdDevice            b.b3
  iManufacturer           0 
  iProduct                0 
  iSerial                 0 
  bNumConfigurations      1
  Configuration Descriptor:
    bLength                 9
    bDescriptorType         2
    wTotalLength       0x0029
    bNumInterfaces          1
    bConfigurationValue     1
    iConfiguration          0 
    bmAttributes         0xe0
      Self Powered         <=========================
      Remote Wakeup
    MaxPower                2mA
    Interface Descriptor:
      bLength                 9
      bDescriptorType         4
      bInterfaceNumber        0
      bAlternateSetting       0
      bNumEndpoints           1
      bInterfaceClass         9 Hub
      bInterfaceSubClass      0 [unknown]
      bInterfaceProtocol      1 Single TT
      iInterface              0 
      Endpoint Descriptor:
        bLength                 7
        bDescriptorType         5
        bEndpointAddress     0x81  EP 1 IN
        bmAttributes            3
          Transfer Type            Interrupt
          Synch Type               None
          Usage Type               Data
        wMaxPacketSize     0x0001  1x 1 bytes
        bInterval              12
    Interface Descriptor:
      bLength                 9
      bDescriptorType         4
      bInterfaceNumber        0
      bAlternateSetting       1
      bNumEndpoints           1
      bInterfaceClass         9 Hub
      bInterfaceSubClass      0 [unknown]
      bInterfaceProtocol      2 TT per port
      iInterface              0 
      Endpoint Descriptor:
        bLength                 7
        bDescriptorType         5
        bEndpointAddress     0x81  EP 1 IN
        bmAttributes            3
          Transfer Type            Interrupt
          Synch Type               None
          Usage Type               Data
        wMaxPacketSize     0x0001  1x 1 bytes
        bInterval              12
Hub Descriptor:
  bLength               9
  bDescriptorType      41
  nNbrPorts             4
  wHubCharacteristic 0x000d
    Per-port power switching
    Compound device
    Per-port overcurrent protection
    TT think time 8 FS bits
  bPwrOn2PwrGood       50 * 2 milli seconds
  bHubContrCurrent      1 milli Ampere
  DeviceRemovable    0x02
  PortPwrCtrlMask    0xff
 Hub Port Status:
   Port 1: 0000.0100 power
   Port 2: 0000.0100 power
   Port 3: 0000.0100 power
   Port 4: 0000.0100 power
Device Qualifier (for other device speed):
  bLength                10
  bDescriptorType         6
  bcdUSB               2.00
  bDeviceClass            9 Hub
  bDeviceSubClass         0 [unknown]
  bDeviceProtocol         0 Full speed (or root) hub
  bMaxPacketSize0        64
  bNumConfigurations      1
Device Status:     0x0001
  Self Powered         <=========================
```

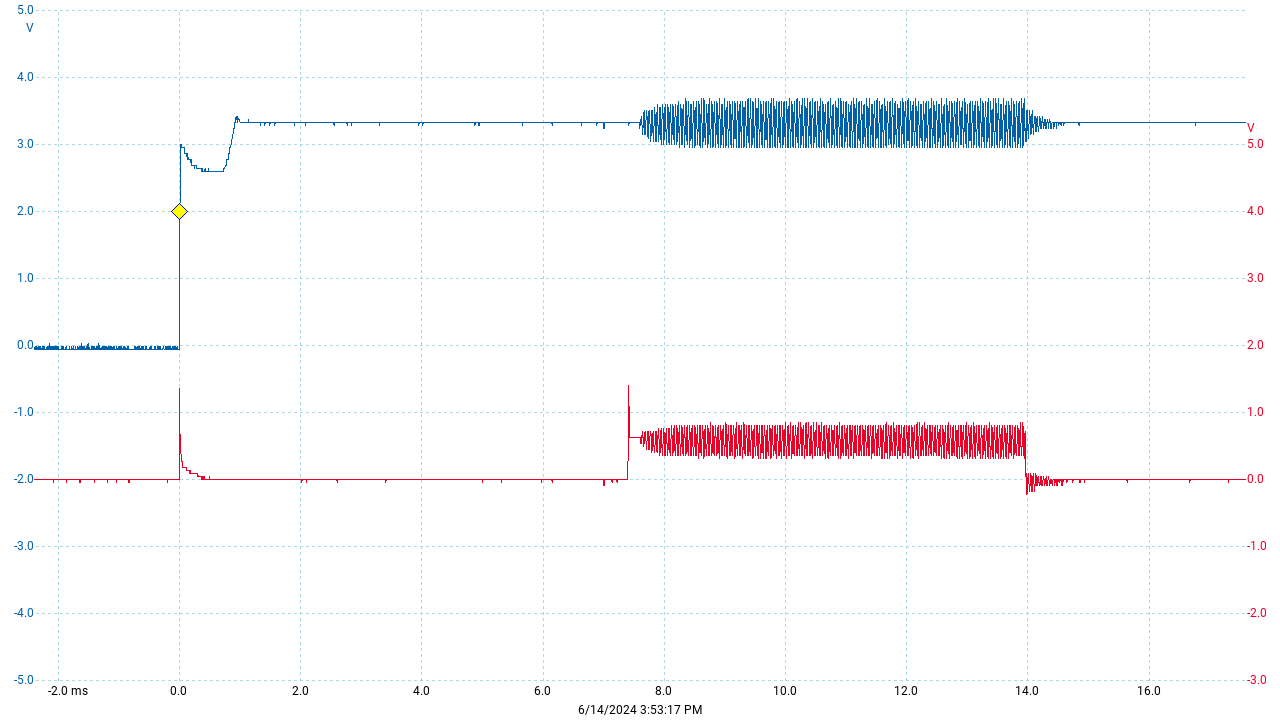
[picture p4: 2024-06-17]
octohub_kicad_v0.2/commissioning/README_try_v0.1b/R216_XTALOUT_c.png

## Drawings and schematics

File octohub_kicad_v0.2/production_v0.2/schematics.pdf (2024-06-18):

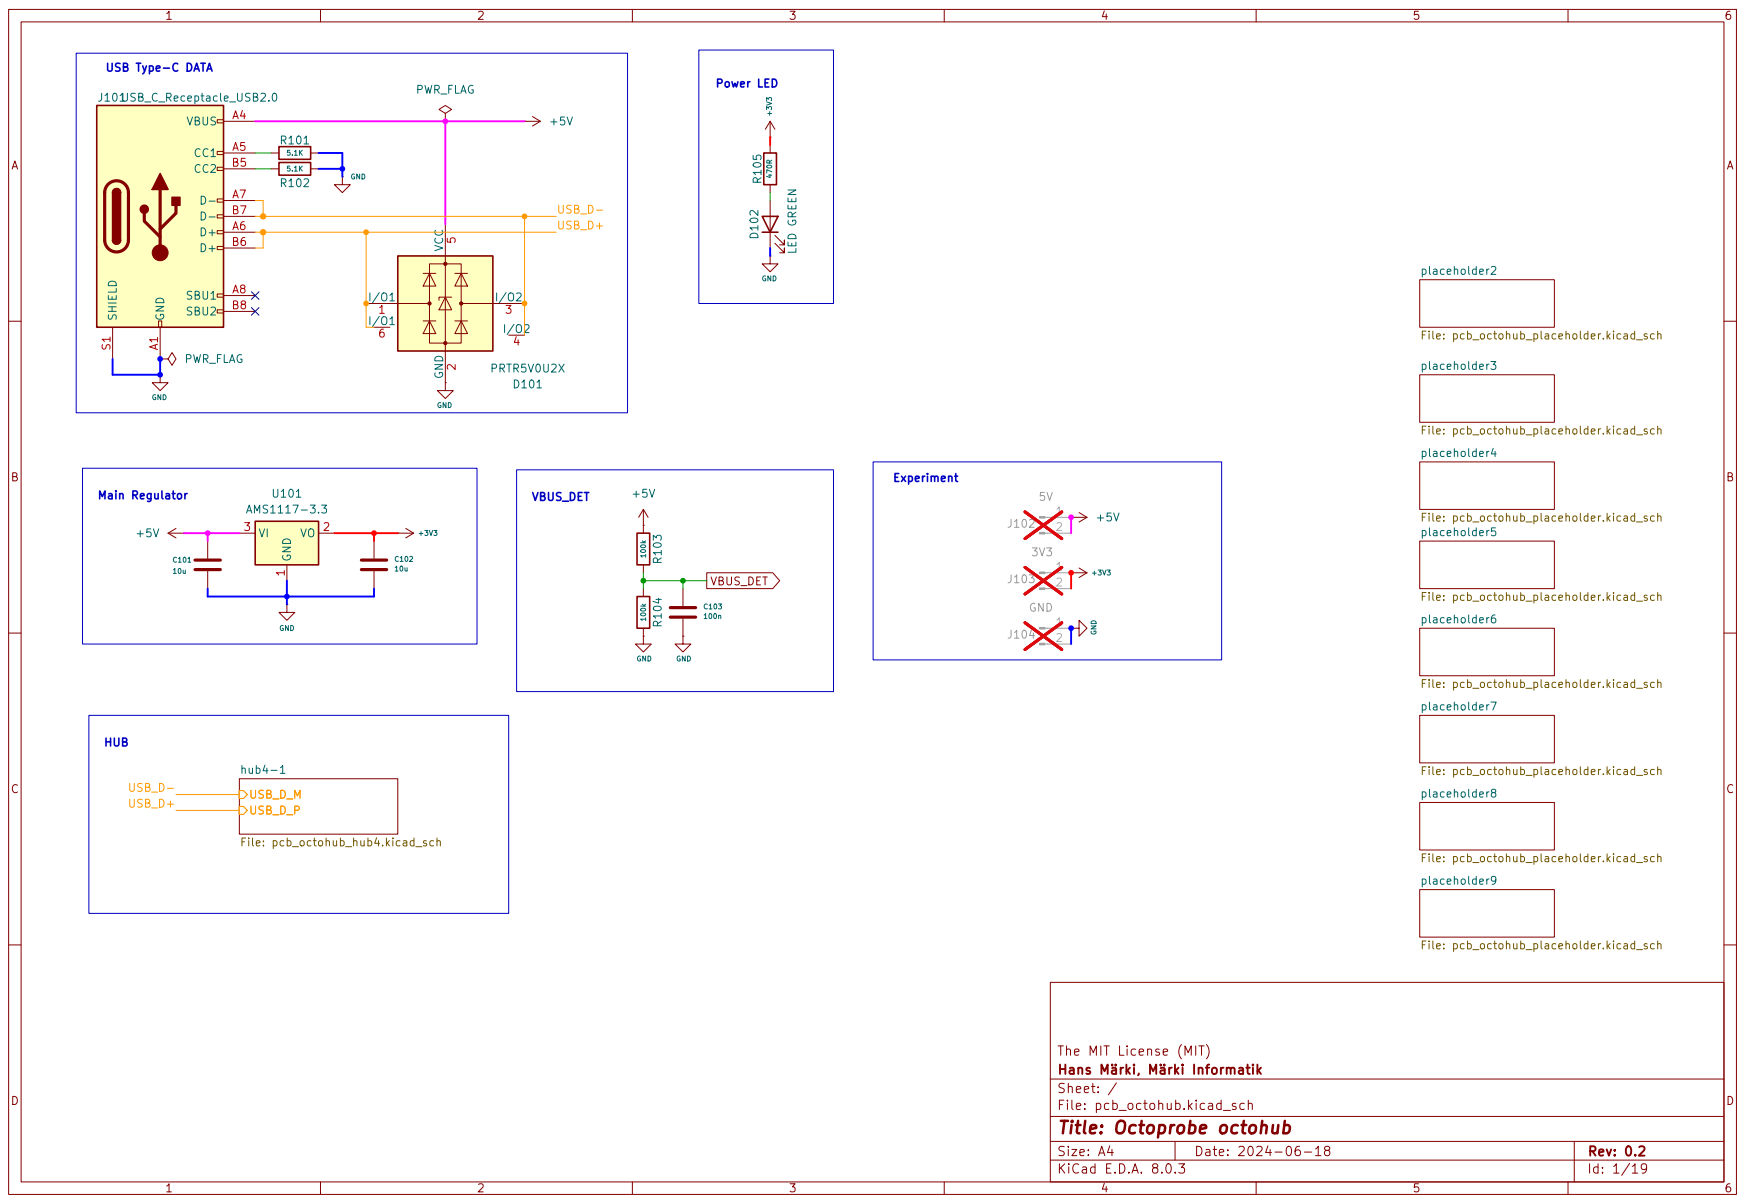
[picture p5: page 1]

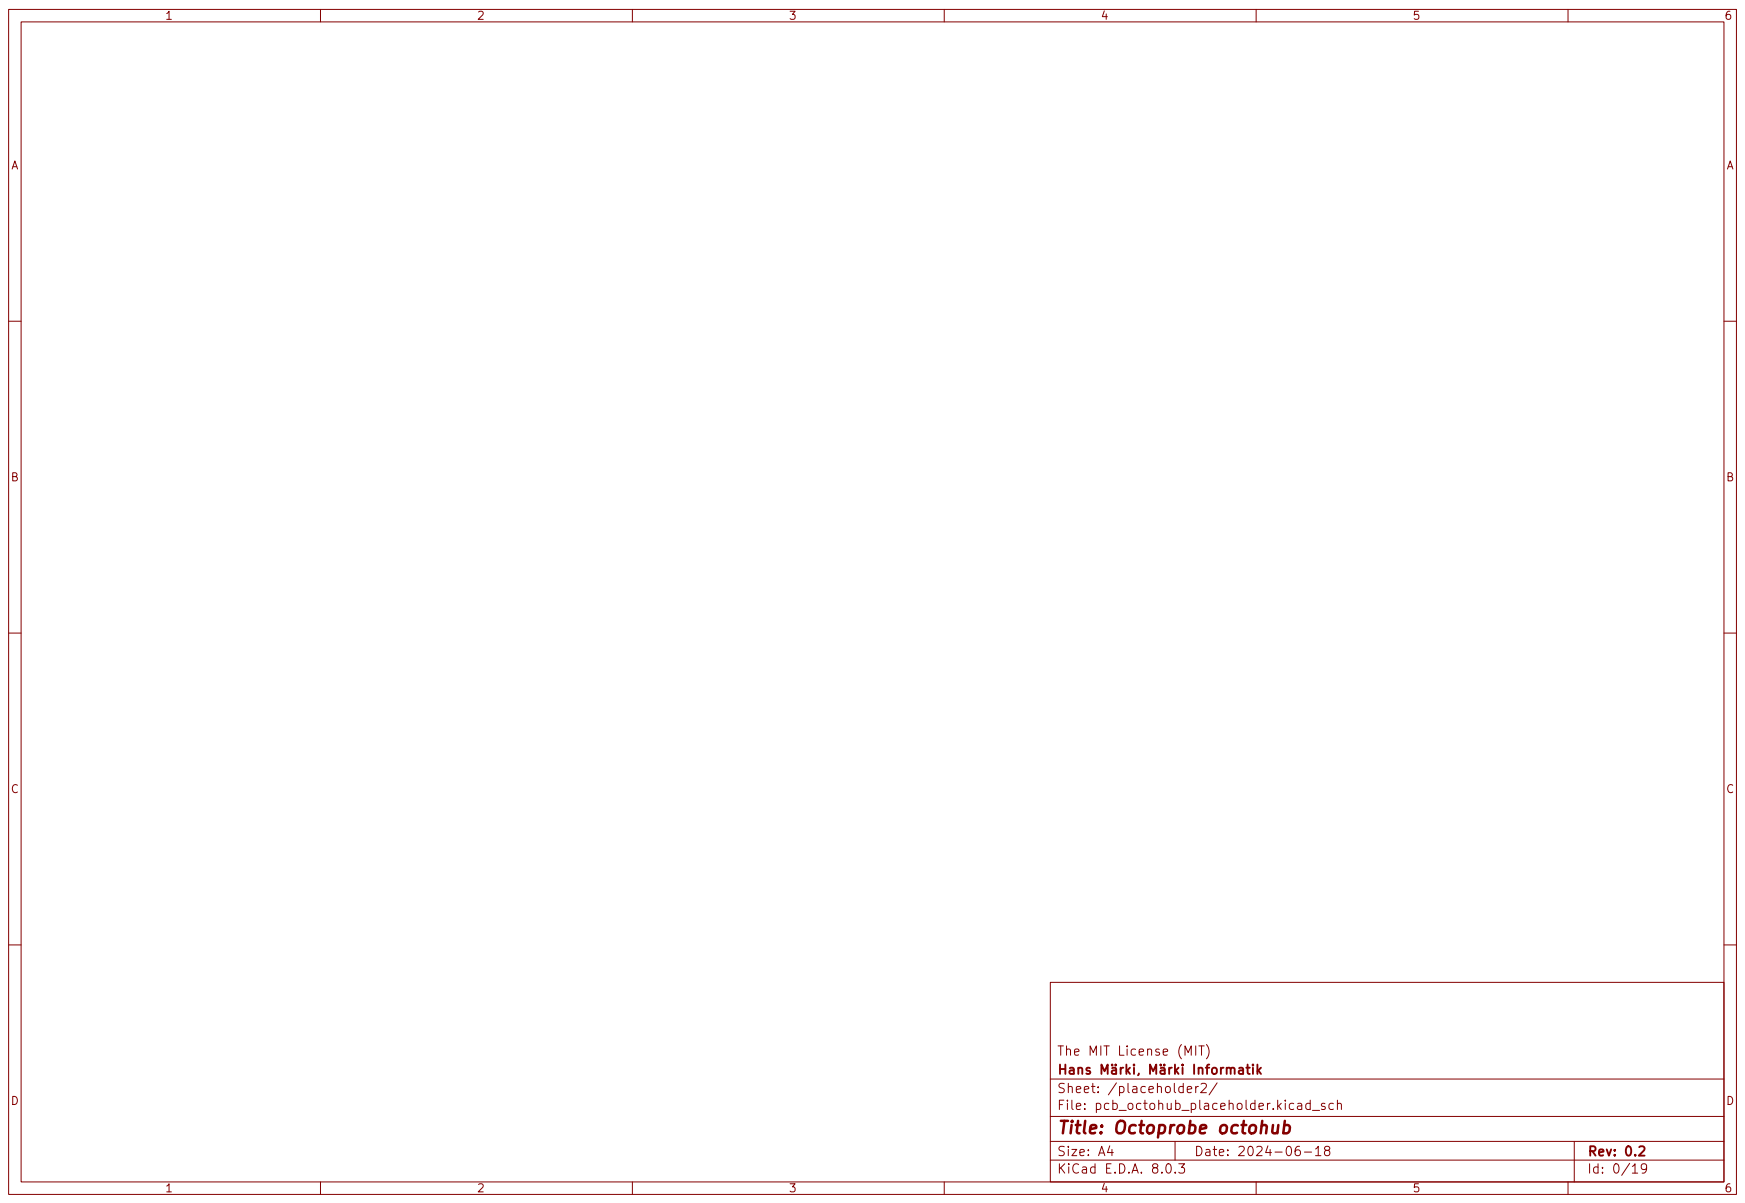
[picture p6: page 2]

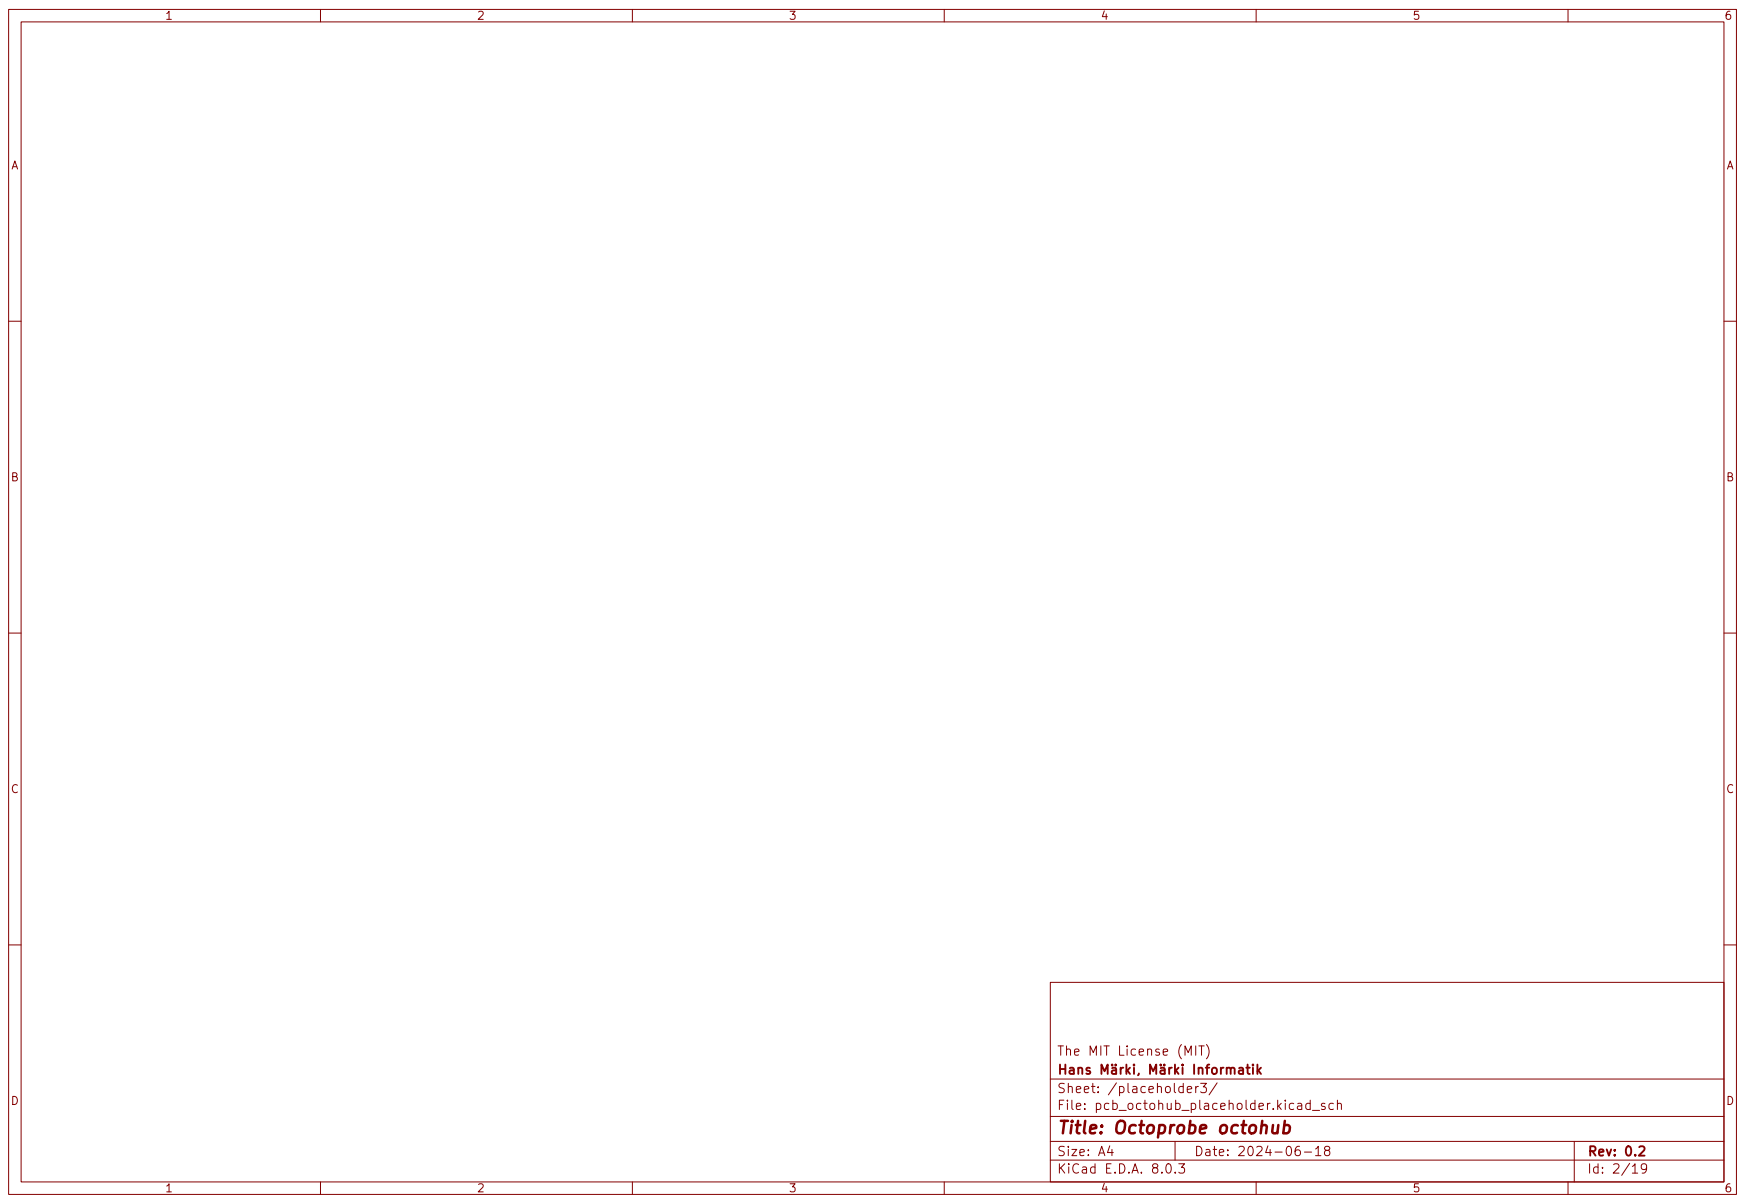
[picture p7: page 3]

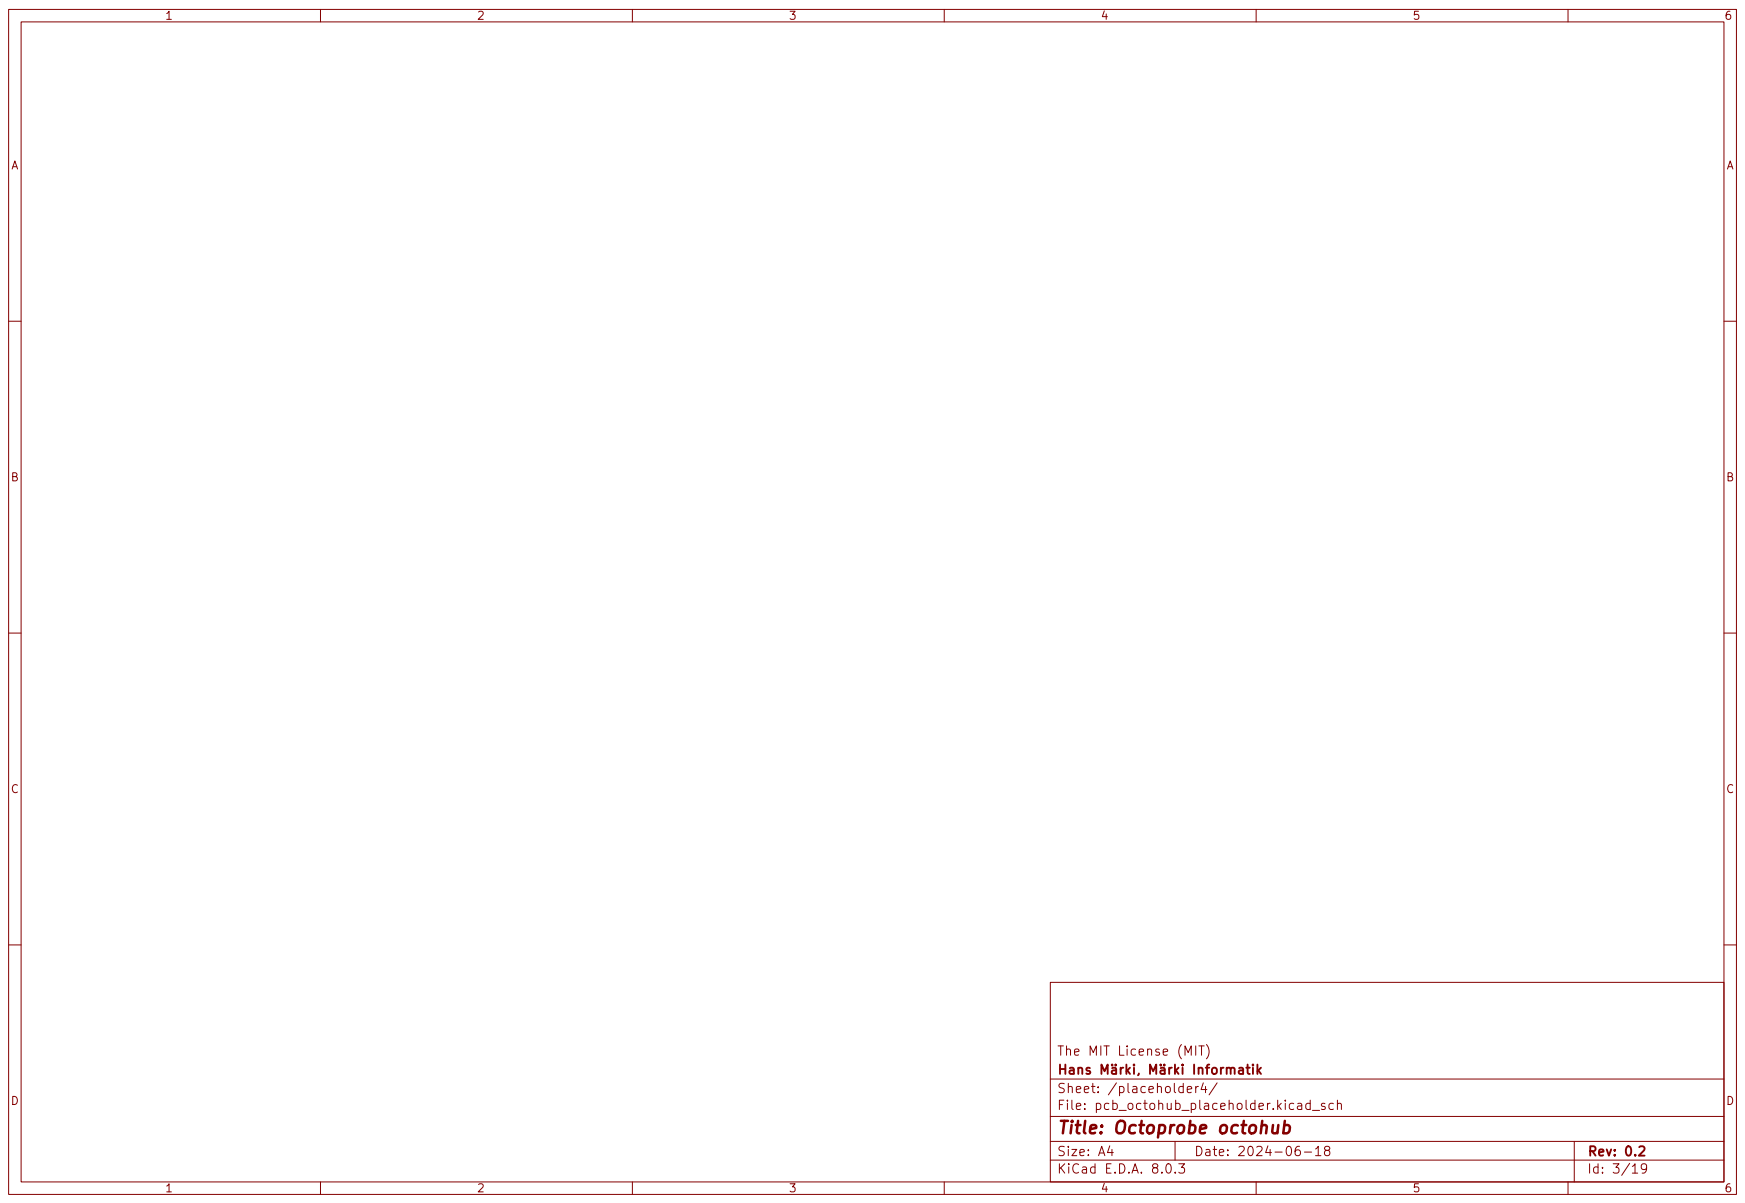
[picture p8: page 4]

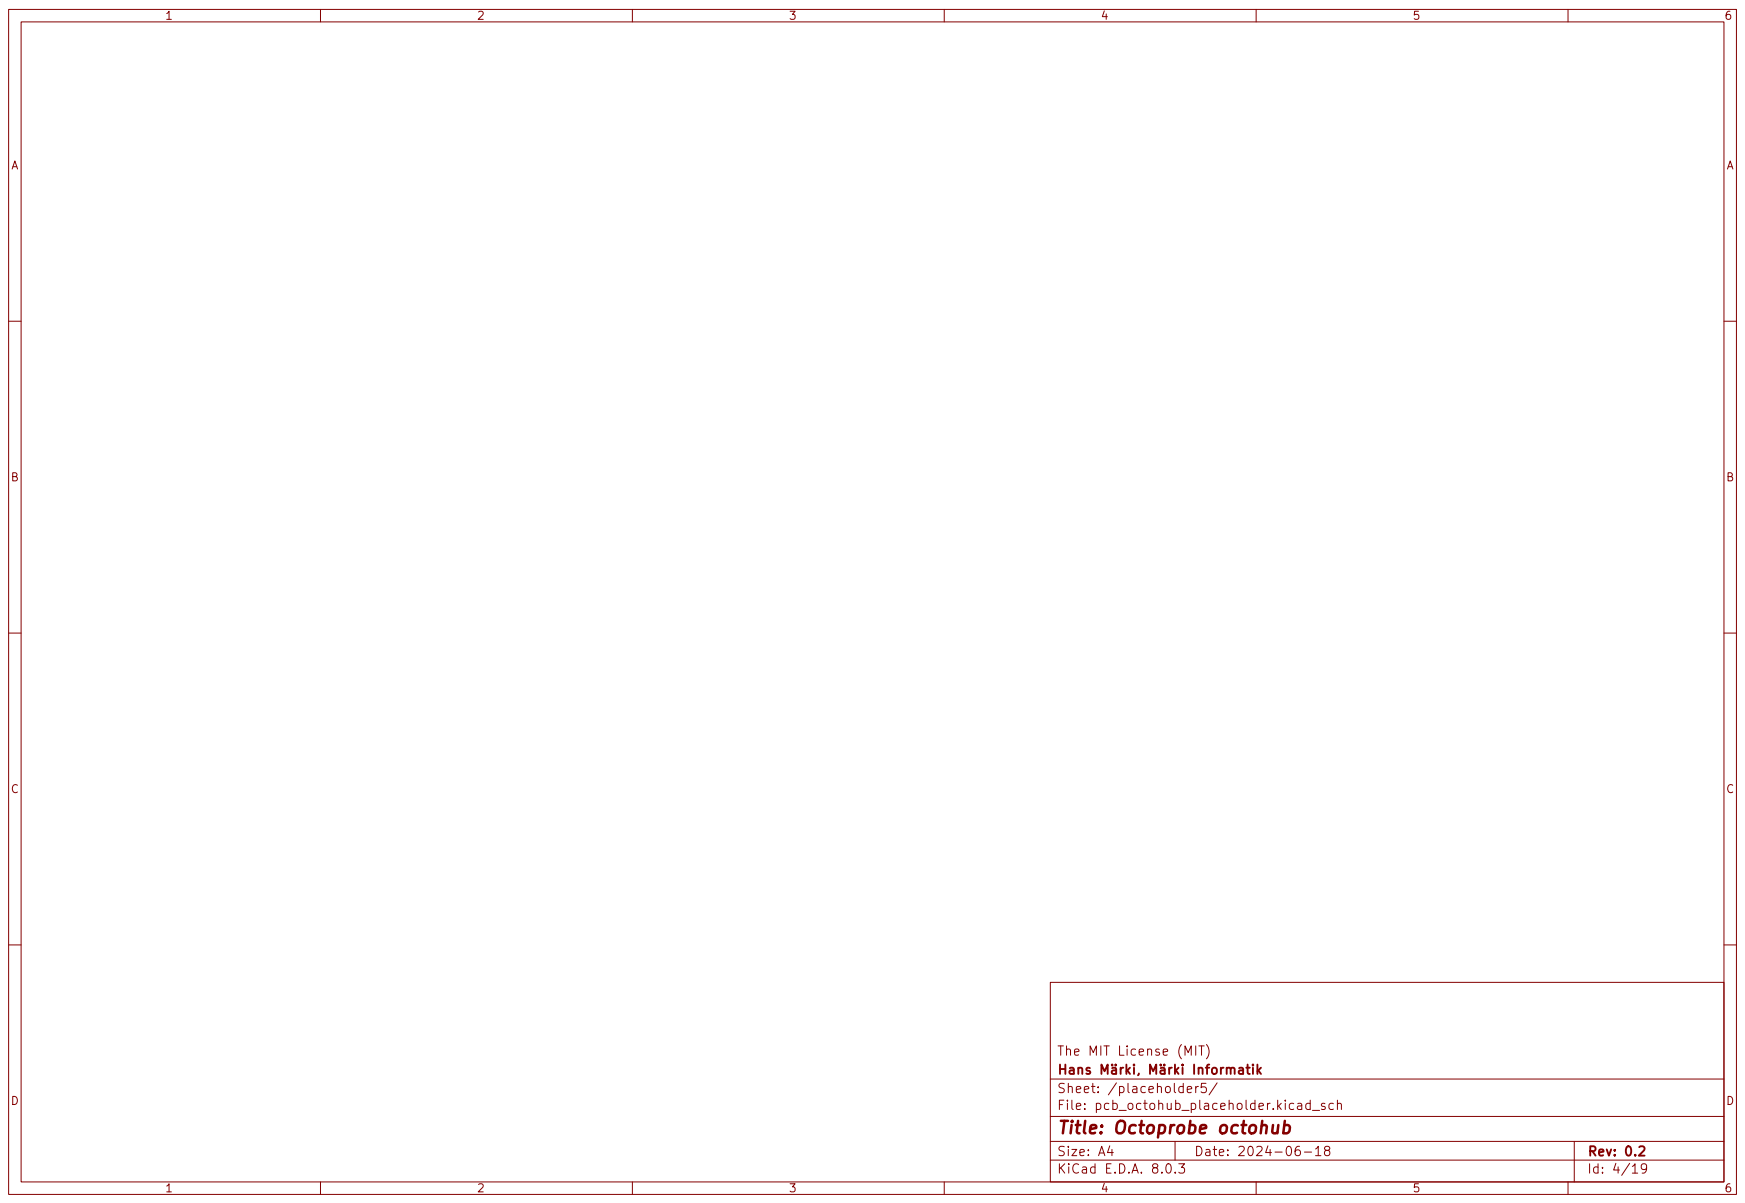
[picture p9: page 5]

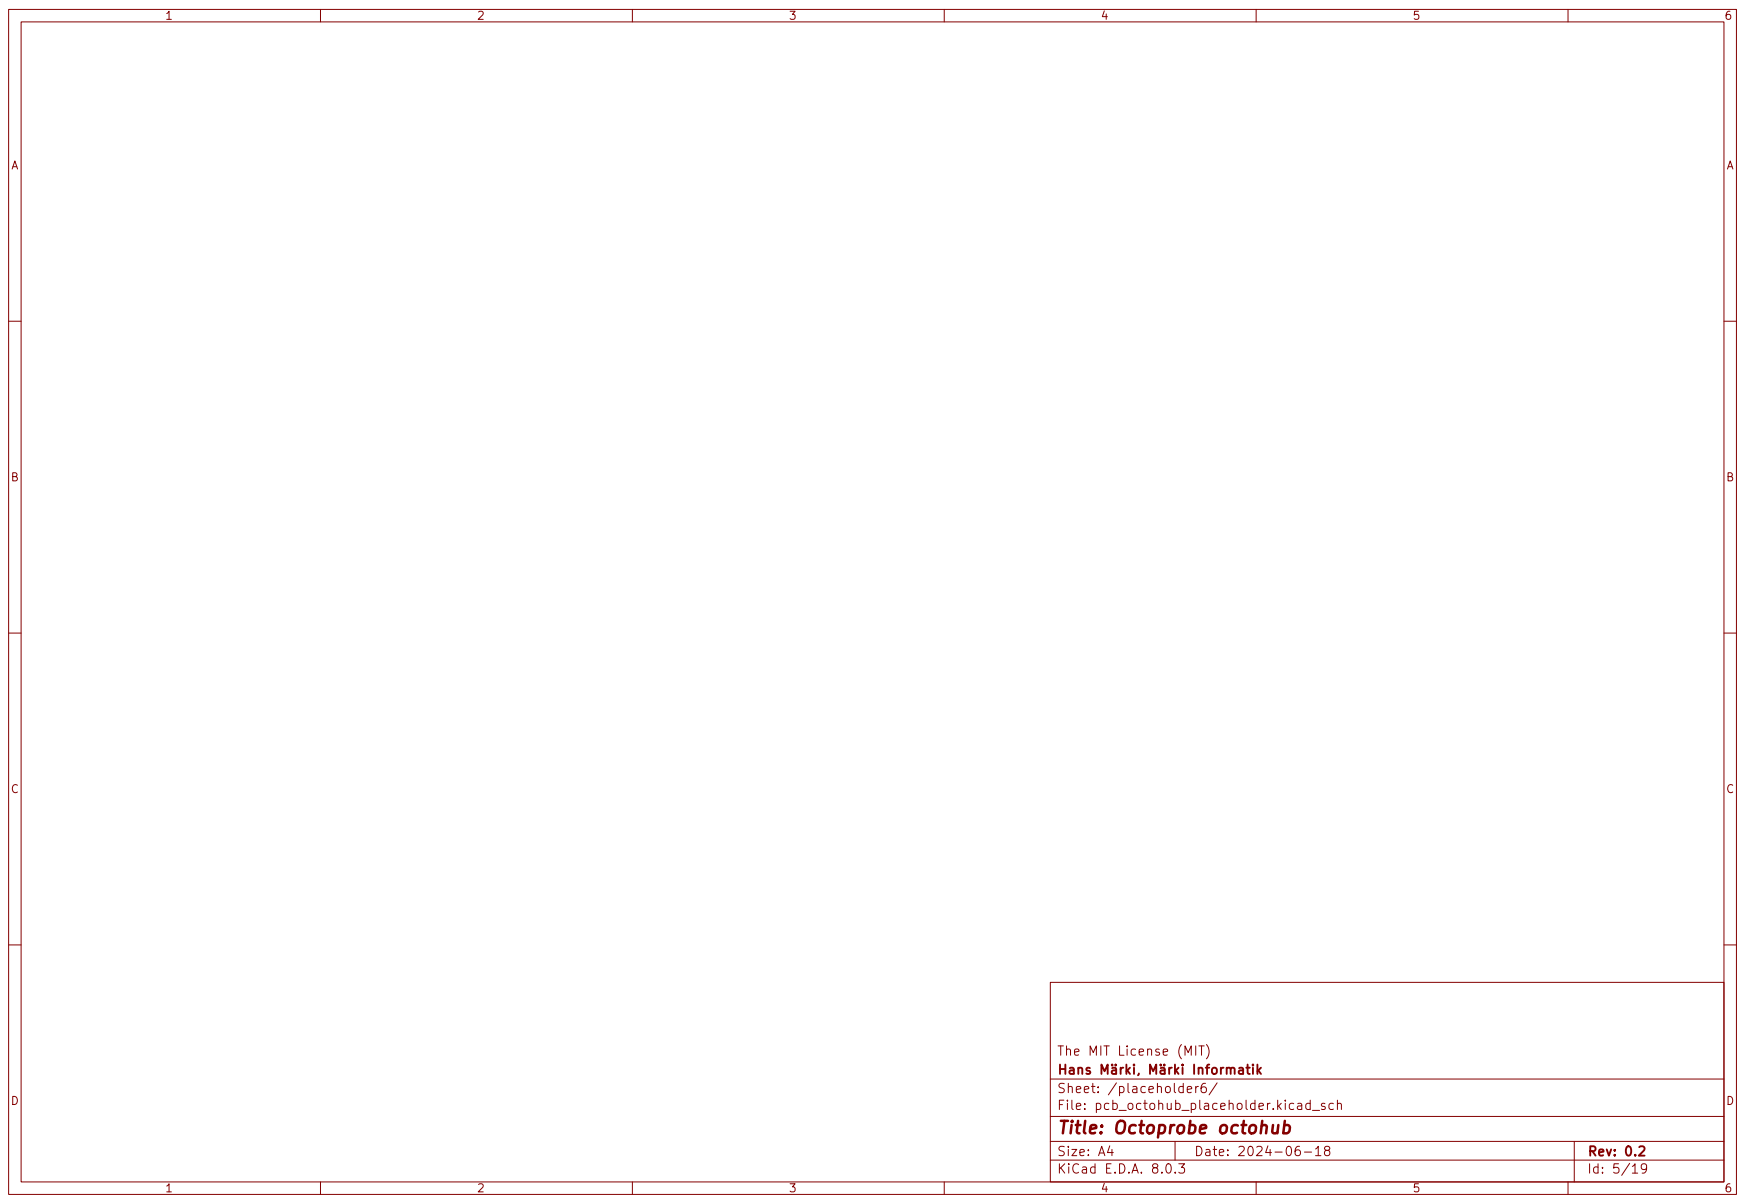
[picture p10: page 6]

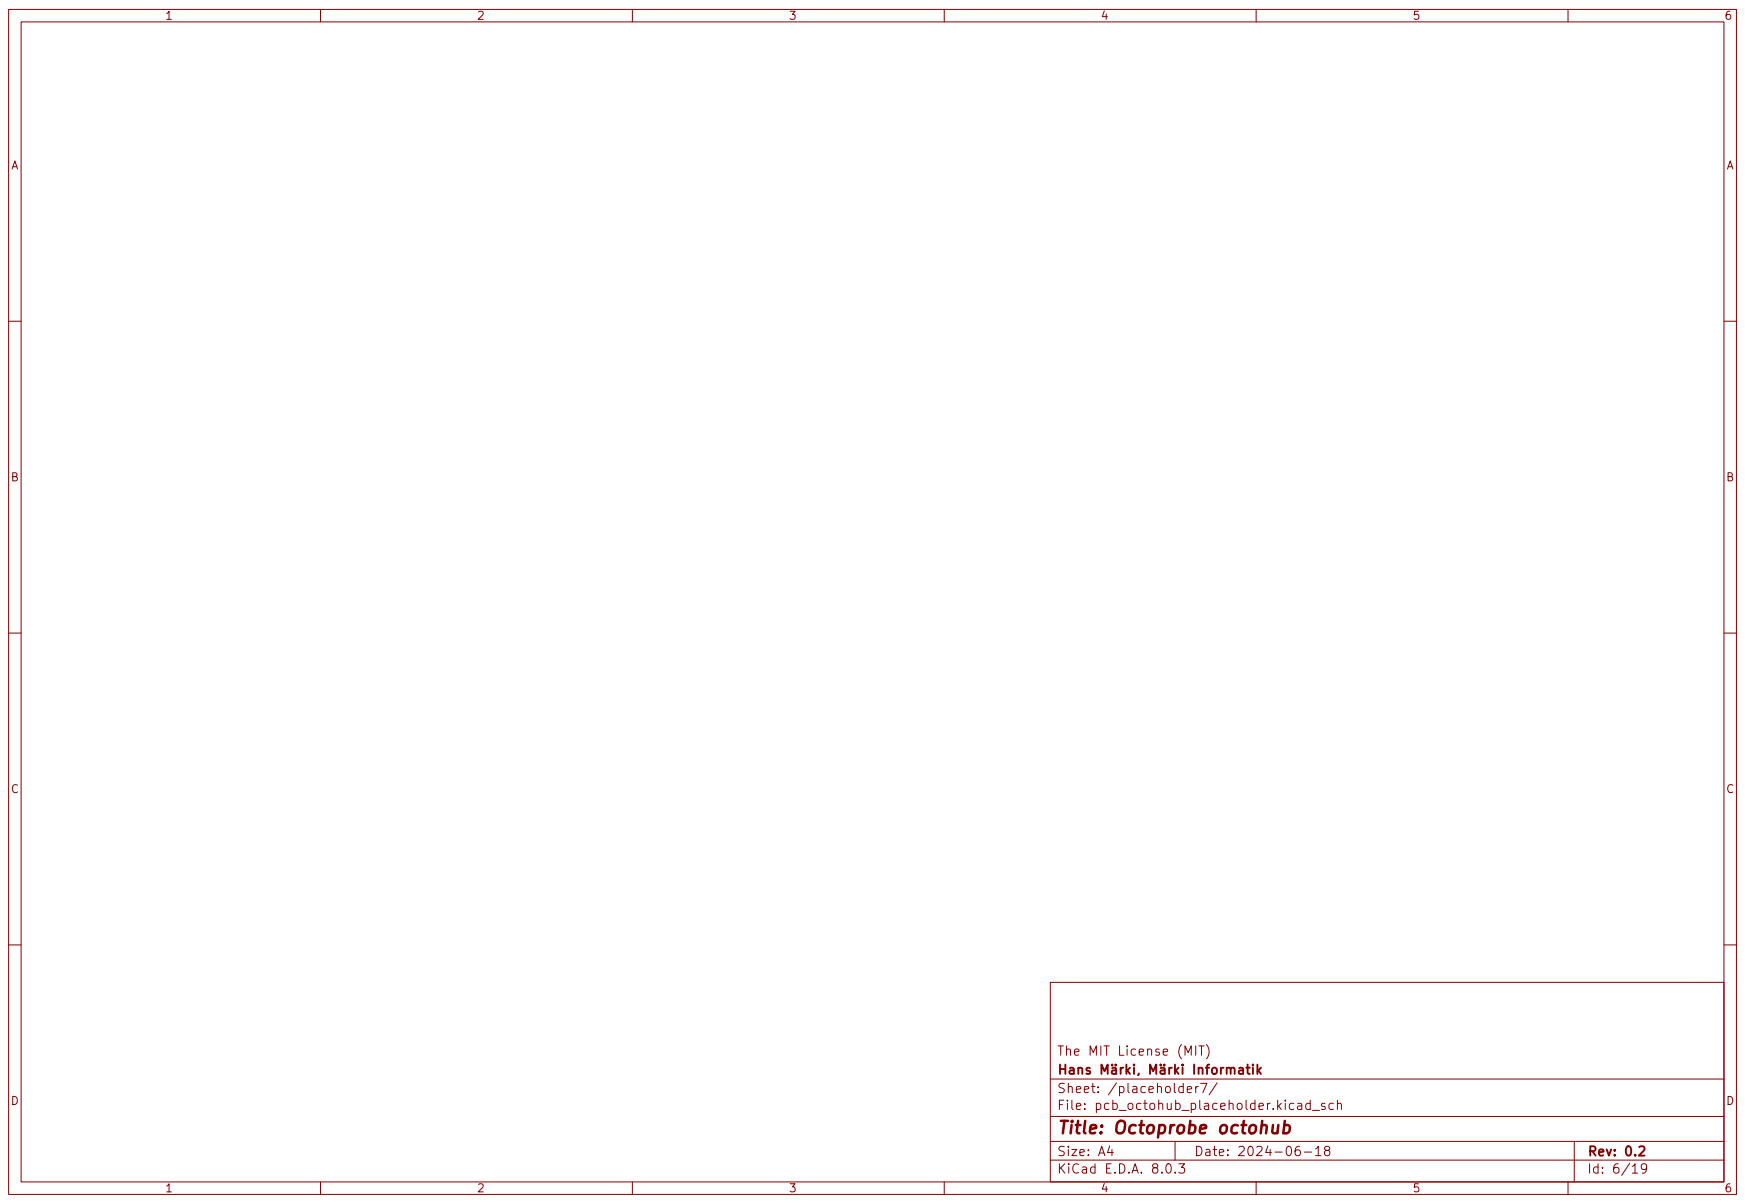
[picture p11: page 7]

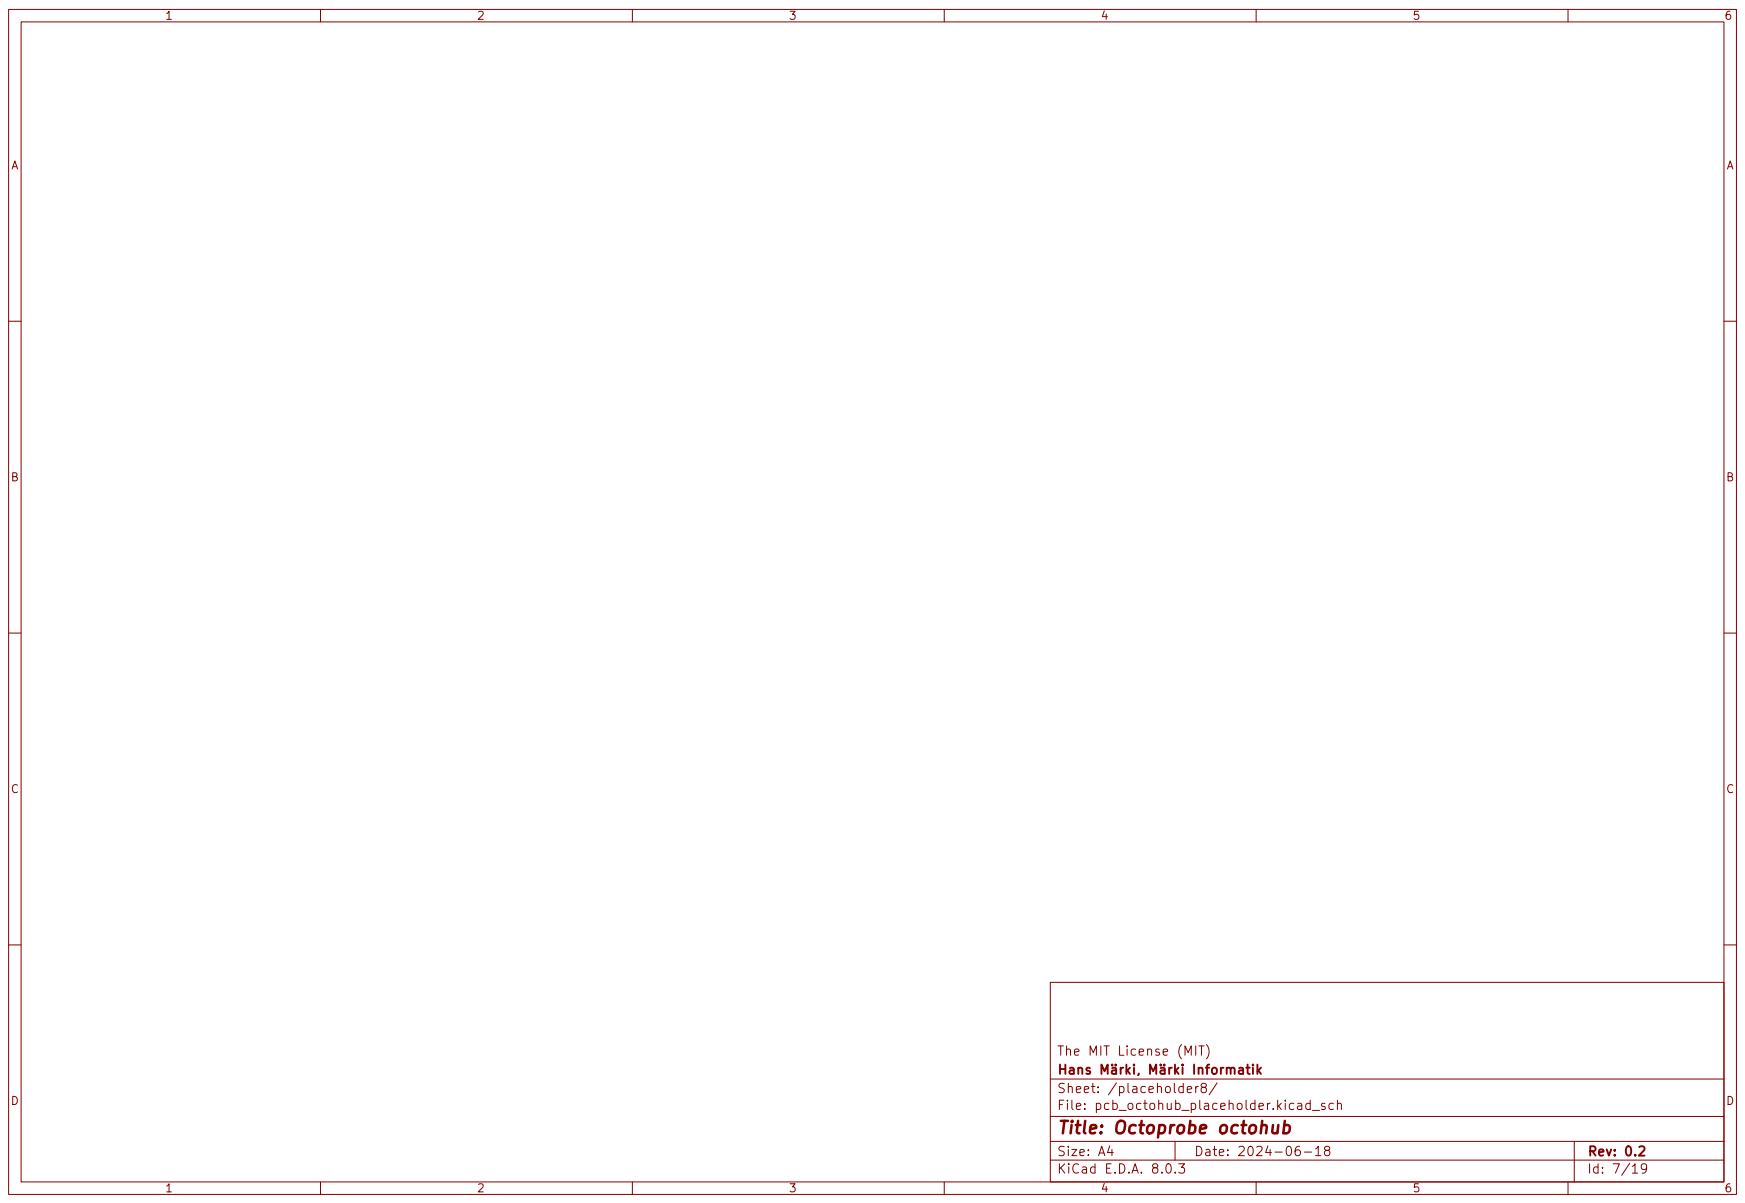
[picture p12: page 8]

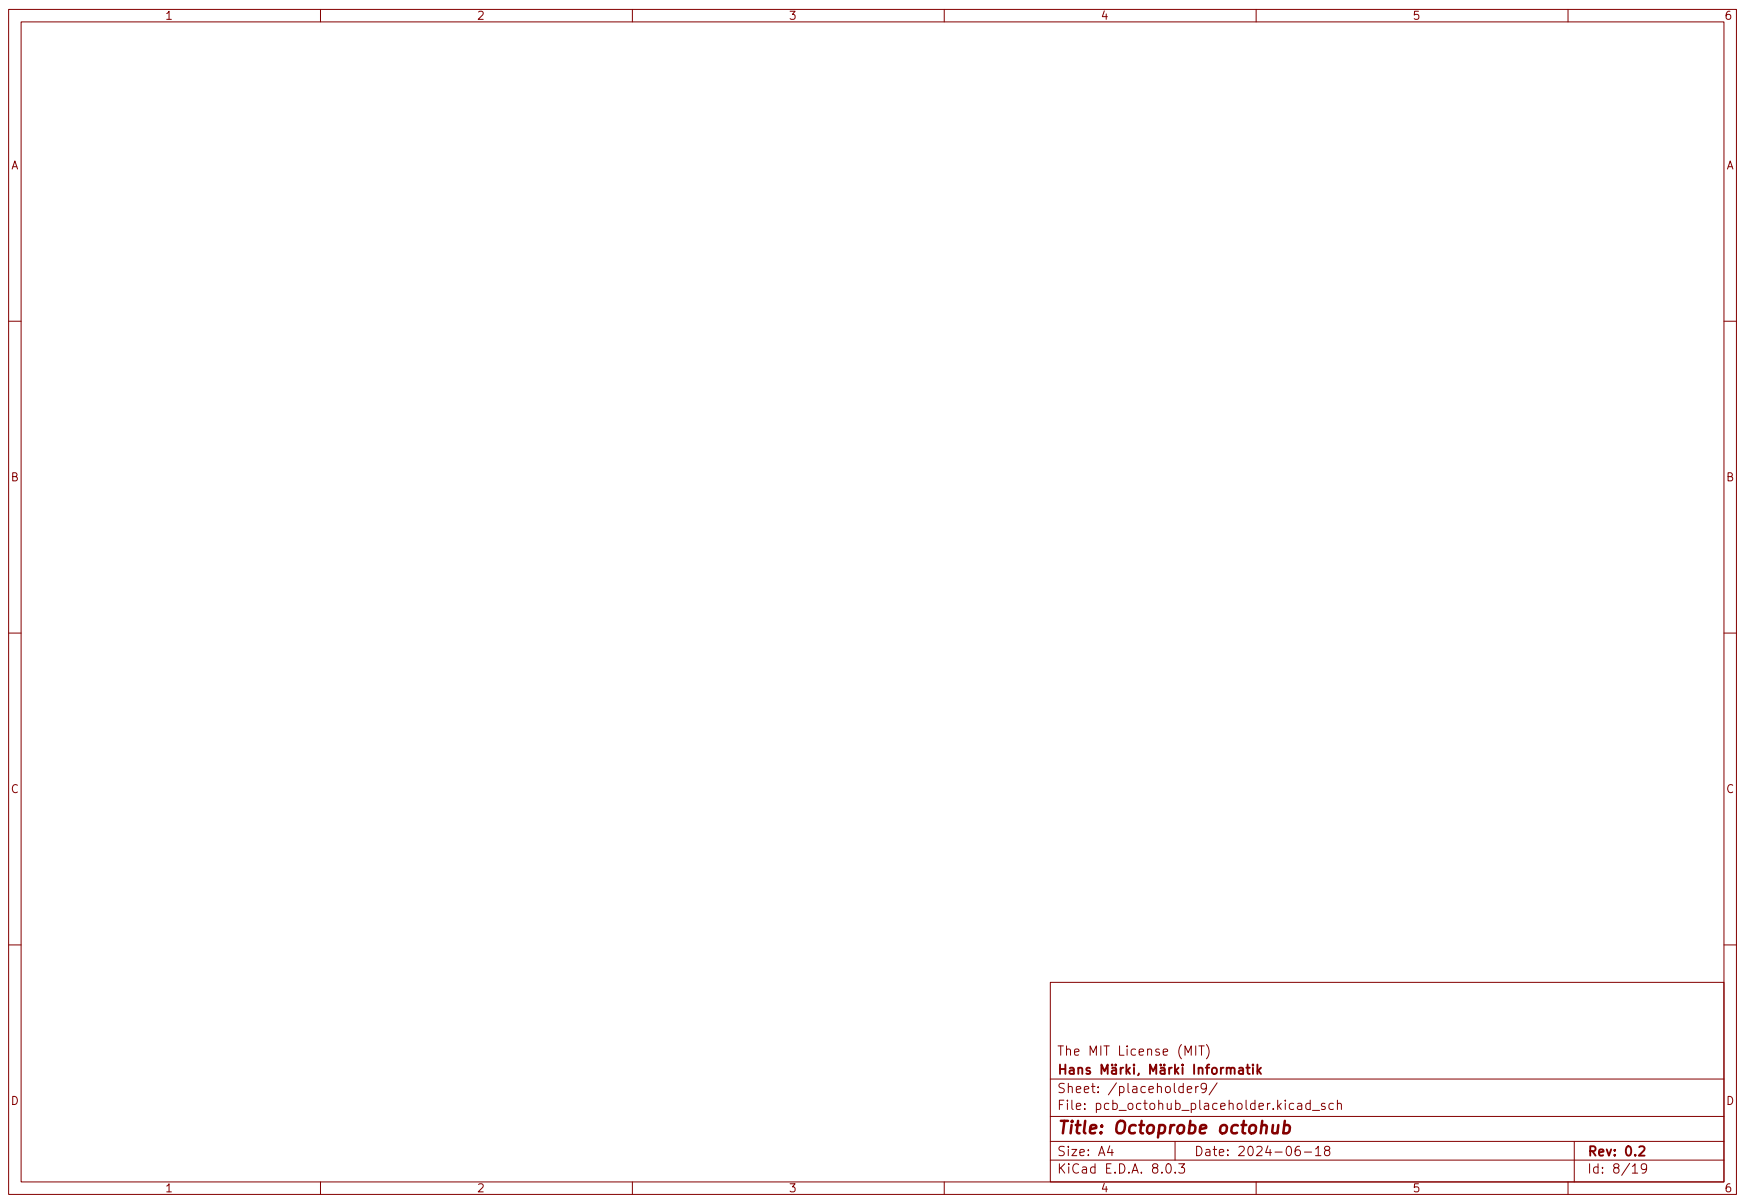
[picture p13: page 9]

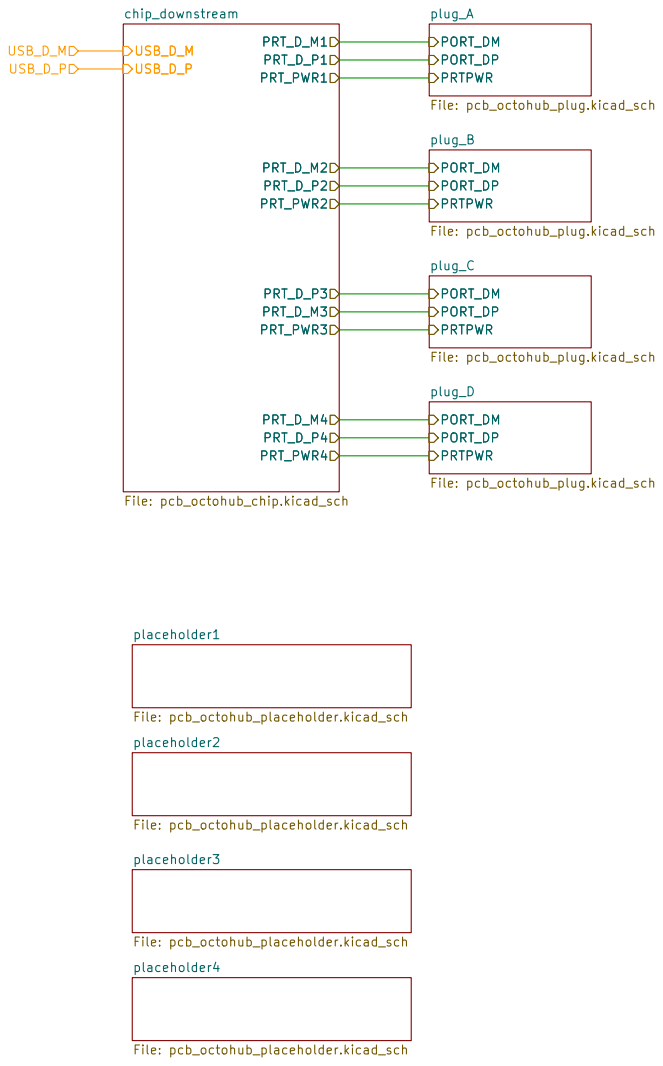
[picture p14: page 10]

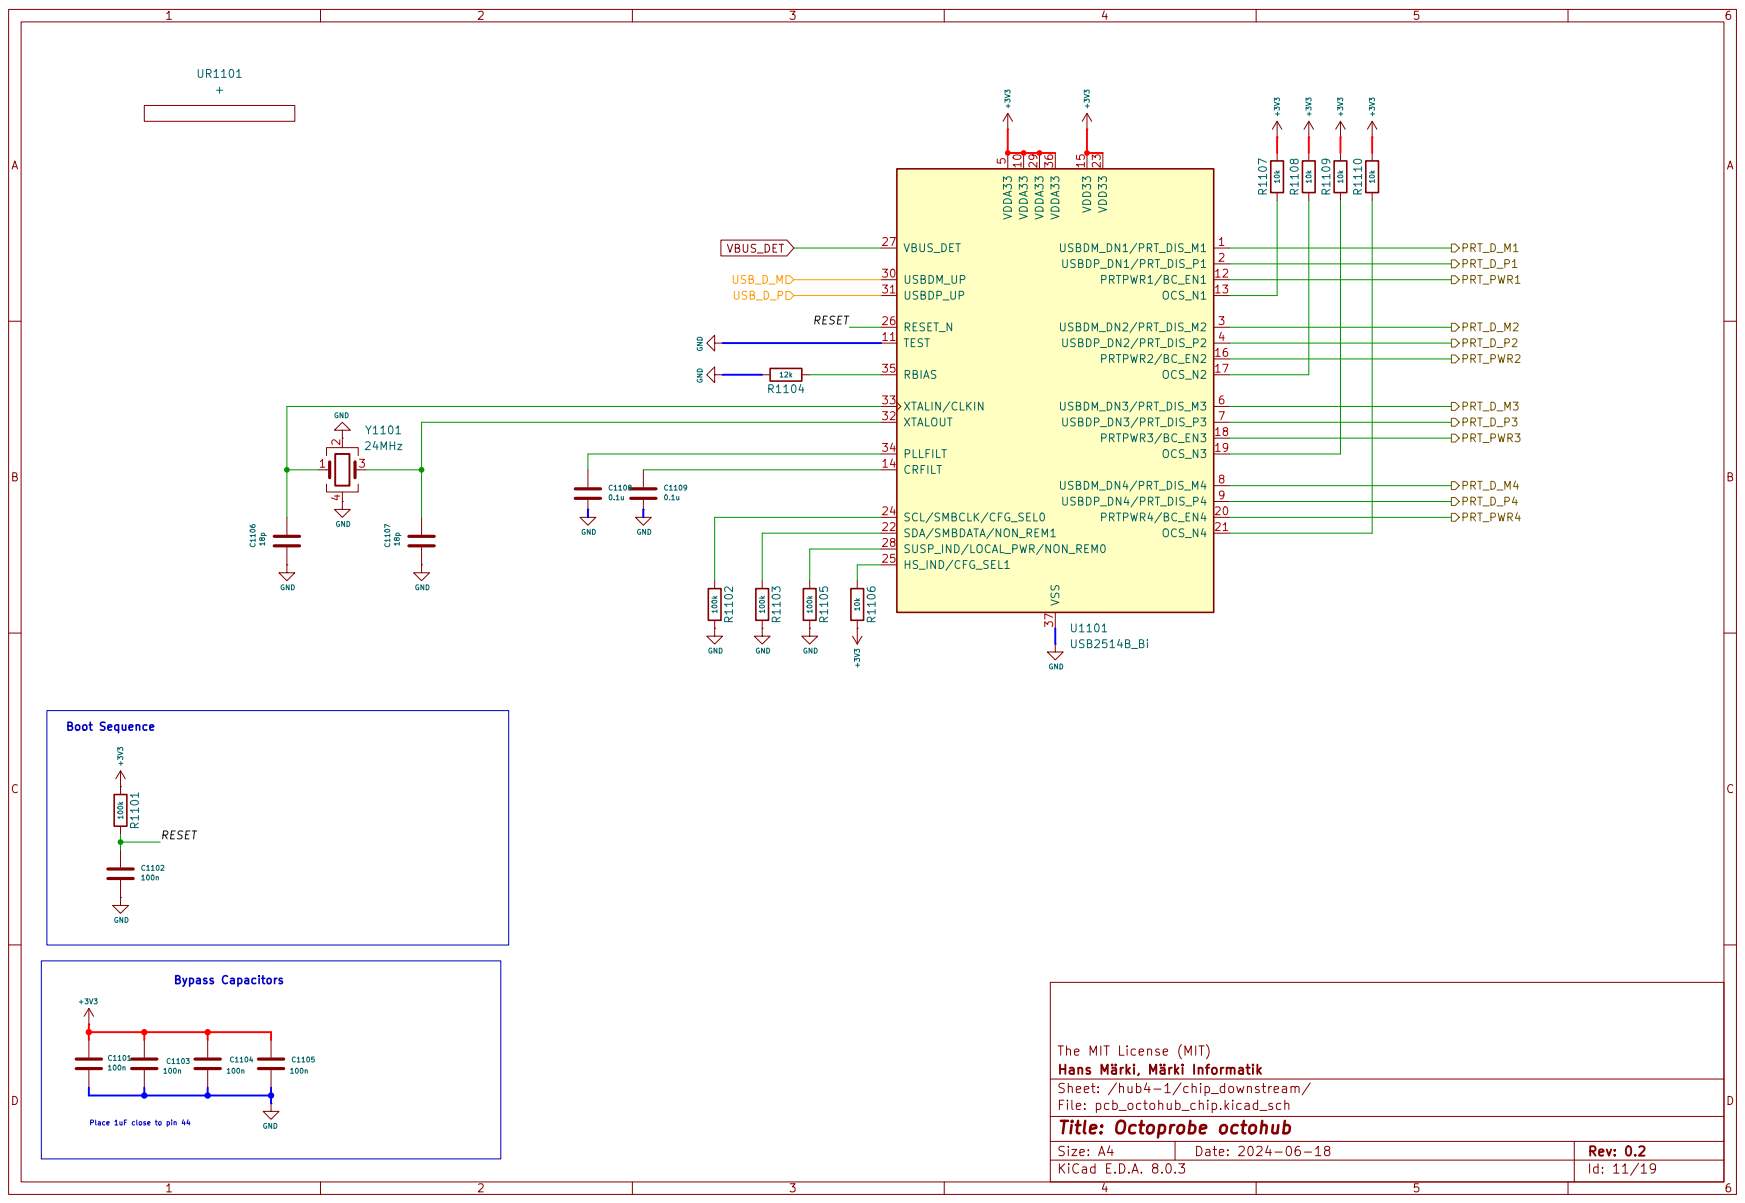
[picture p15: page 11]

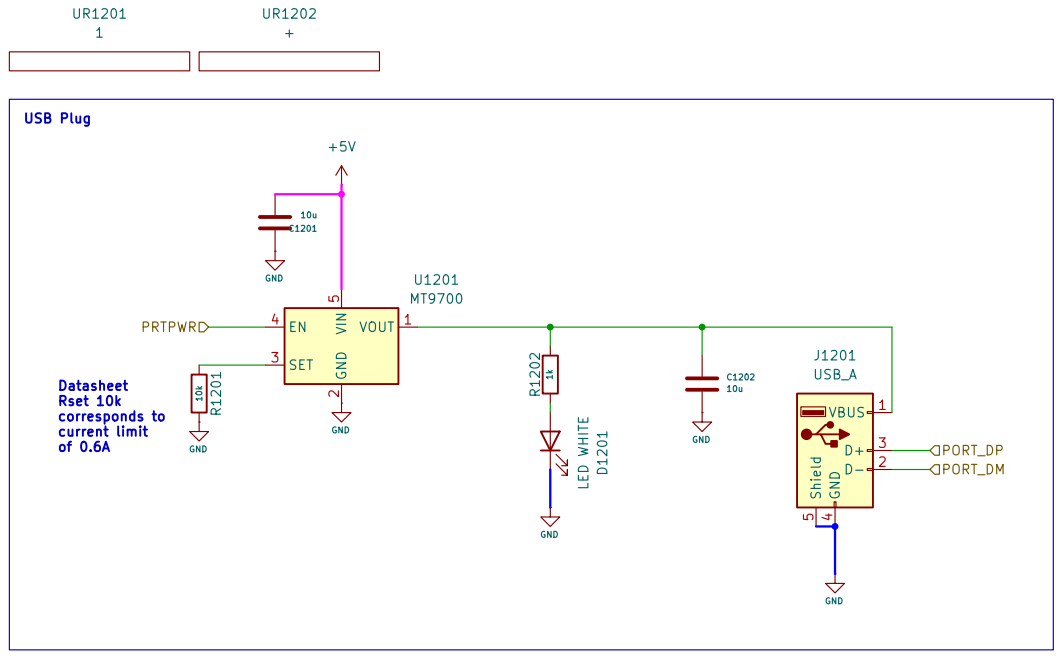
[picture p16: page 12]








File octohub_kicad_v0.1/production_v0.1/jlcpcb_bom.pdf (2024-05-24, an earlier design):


Automatically saved, last upd

10V 10uF X5R ±10% 0603 Multilayer Ceramic …
SON-6(1x1.5) Electrostatic and Surge Protectio…

5A 1 16P Female Type-C SMD USB Connector…
1.5A USB 2.0 1 Straight 4P Female -25℃~+85…

62.5mW Thick Film Resistors 50V ±100ppm/℃ …
72dB@(120Hz) 1A Fixed 3.3V Positive electrod…
集线器 VQFN-36-EP(6x6) USB Converters RO…

Please carefully check th

EasyEDA - PCB Design Tool (https://easyeda.com/)

Quality Management (https://jlcpcb.com/aboutUs/qualityControl)

Security (https://jlcpcb.com/aboutUs/security)

Certifications (https://jlcpcb.com/help/article/26-Certifications)

How To Order (https://jlcpcb.com/help/catalog/11-How-To-Order)

How To Track (https://jlcpcb.com/help/article/51-How-to-Track-My-Order)

Contact Us (https://jlcpcb.com/help/contact)

Support Team (https://jlcpcb.com/ourTeam)

JLCMC - Mechatronic Parts (https://jlcmc.com/?href=jlc-footer&source=jlc)

OSHWLAB - Open Source Hardware (https://oshwlab.com/?source=jlcpcb-footer)

© 2024 JLCPCB.COM All Rights Reserved. Privacy Policy (https://jlcpcb.com/help/article/31-Privacy-Policy) Terms (https://jlcpcb.com/help/article/30-Terms-&-Conditions) &














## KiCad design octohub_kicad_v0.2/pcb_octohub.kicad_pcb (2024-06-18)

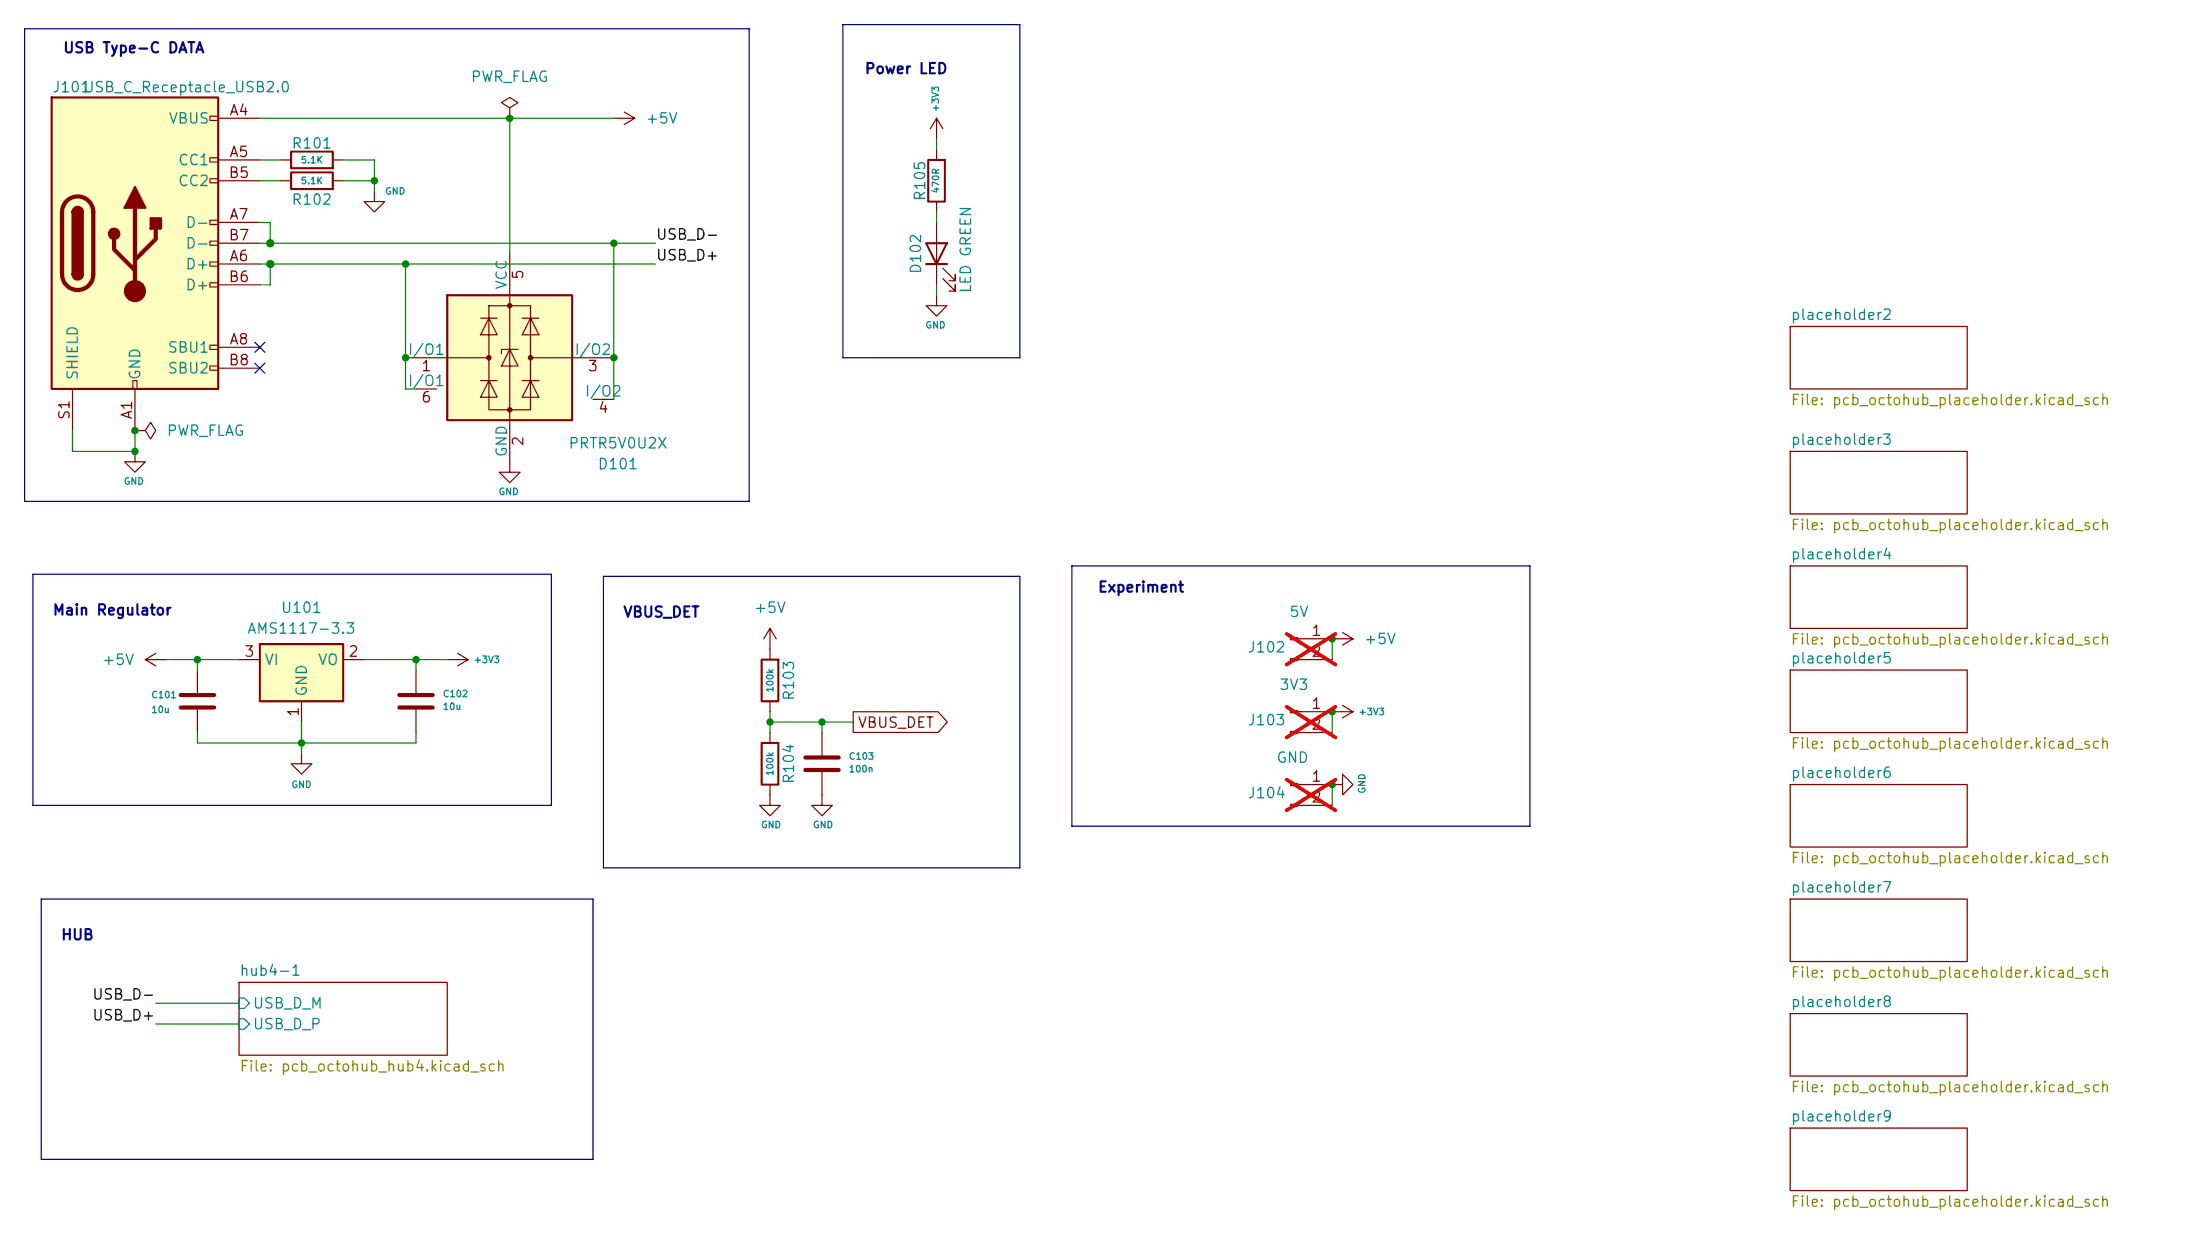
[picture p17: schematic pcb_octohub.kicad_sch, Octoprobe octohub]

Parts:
C101, C102: 10u; C_0603_1608Metric
C103: 100n; C_0603_1608Metric
D101: PRTR5V0U2X; Texas_USON-6_1x1.45mm_P0.5mm_SMD; JLC C2937001
D102: LED GREEN; LED_0603_1608Metric; JLC C2297
J101: USB_C_Receptacle_USB2.0; USB_C_Receptacle_Palconn_UTC16-G; JLC C165948
J102: 5V; PinHeader_1x02_P2.54mm_Vertical; not fitted
J103: 3V3; PinHeader_1x02_P2.54mm_Vertical; not fitted
J104: GND; PinHeader_1x02_P2.54mm_Vertical; not fitted
R101, R102: 5.1K; R_0402_1005Metric
R103, R104: 100k; R_0402_1005Metric
R105: 470R; R_0402_1005Metric
U101: AMS1117-3.3; SOT-223-3_TabPin2; JLC C6186

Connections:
+3V3: C102.1, J103.1, J103.2, R105.2, U101.2 (VO); also elsewhere on the board
+5V: C101.1, D101.5 (VCC), J101.A4 (VBUS), J101.A9 (VBUS), J101.B4 (VBUS), J101.B9 (VBUS), J102.1, J102.2, R103.2, U101.3 (VI); also elsewhere on the board
/USB_D+: D101.1 (I/O1), D101.6 (I/O1), J101.A6 (D+), J101.B6 (D+); also elsewhere on the board
/USB_D-: D101.3 (I/O2), D101.4 (I/O2), J101.A7 (D-), J101.B7 (D-); also elsewhere on the board
GND: C101.2, C102.2, C103.2, D101.2 (GND), D102.1 (K), J101.A1 (GND), J101.A12 (GND), J101.B1 (GND), J101.B12 (GND), J101.S1 (SHIELD), J104.1, J104.2, R101.2, R102.2, R104.1, U101.1 (GND); also elsewhere on the board
unnamed: D102.2 (A), R105.1
unnamed: J101.A5 (CC1), R101.1
unnamed: J101.B5 (CC2), R102.1
VBUS_DET: C103.1, R103.1, R104.2; also elsewhere on the board

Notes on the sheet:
USB Type-C DATA
VBUS_DET
Power LED
Main Regulator
HUB
Experiment

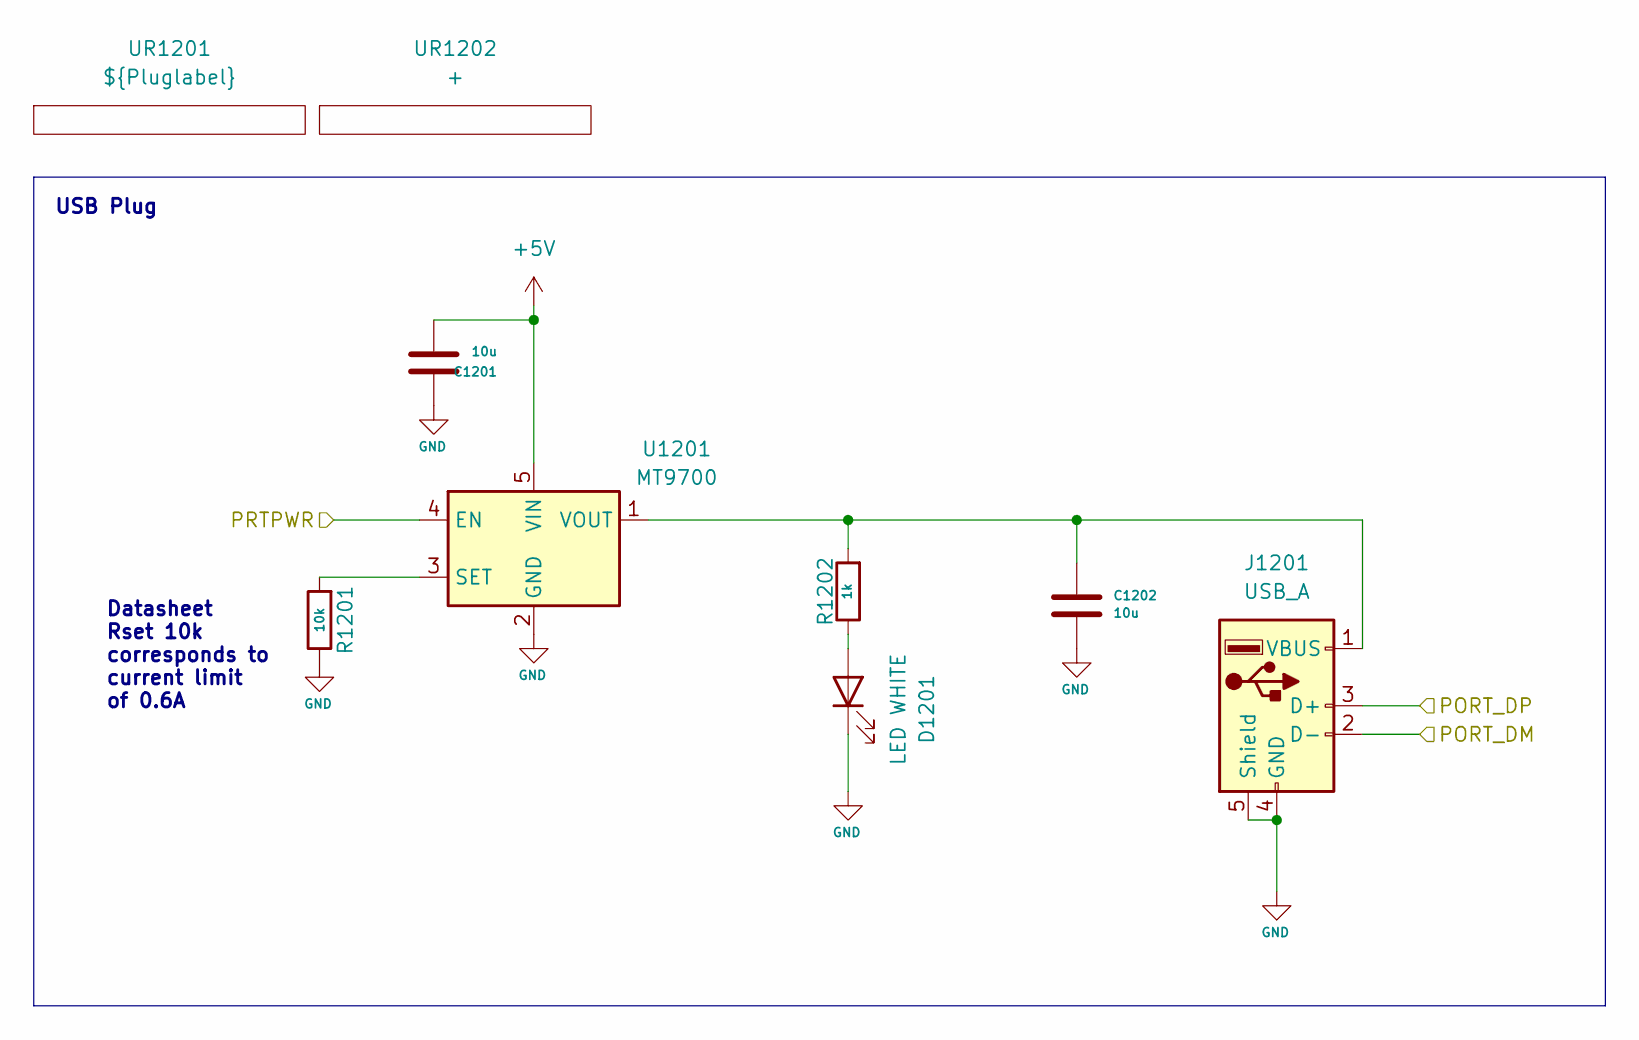
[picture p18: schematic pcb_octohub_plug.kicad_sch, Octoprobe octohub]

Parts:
C1201, C1202: 10u; C_0603_1608Metric
D1201: LED WHITE; LED_0603_1608Metric; JLC C2290
J1201: USB_A; USB_A_SHOUHAN_Vertical; JLC C456015
R1201: 10k; R_0402_1005Metric
R1202: 1k; R_0402_1005Metric
U1201: MT9700; SOT-23-5; JLC C89855
UR1201: ${Pluglabel}; octohub_plug_label
UR1202: +; octohub_plug_top_left

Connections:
+5V: C1201.2, U1201.5 (VIN); also elsewhere on the board
/hub4-1/chip_downstream/PRT_D_M1: J1201.2 (D-); also elsewhere on the board
/hub4-1/chip_downstream/PRT_D_P1: J1201.3 (D+); also elsewhere on the board
/hub4-1/chip_downstream/PRT_PWR1: U1201.4 (EN); also elsewhere on the board
GND: C1201.1, C1202.2, D1201.1 (K), J1201.4 (GND), J1201.5 (Shield), R1201.1, U1201.2 (GND); also elsewhere on the board
unnamed: D1201.2 (A), R1202.1
unnamed: C1202.1, J1201.1 (VBUS), R1202.2, U1201.1 (VOUT)
unnamed: R1201.2, U1201.3 (SET)

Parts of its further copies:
C1301, C1302, C1401, C1402, C1501, C1502: 10u; C_0603_1608Metric
D1301, D1401, D1501: LED WHITE; LED_0603_1608Metric; JLC C2290
J1301, J1401, J1501: USB_A; USB_A_SHOUHAN_Vertical; JLC C456015
R1301, R1401, R1501: 10k; R_0402_1005Metric
R1302, R1402, R1502: 1k; R_0402_1005Metric
U1301, U1401, U1501: MT9700; SOT-23-5; JLC C89855
UR1302, UR1402, UR1502: +; octohub_plug_top_left

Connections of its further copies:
+5V: C1301.2, C1401.2, C1501.2, U1301.5 (VIN), U1401.5 (VIN), U1501.5 (VIN); also elsewhere on the board
/hub4-1/chip_downstream/PRT_D_M2: J1301.2 (D-); also elsewhere on the board
/hub4-1/chip_downstream/PRT_D_M3: J1401.3 (D+); also elsewhere on the board
/hub4-1/chip_downstream/PRT_D_M4: J1501.2 (D-); also elsewhere on the board
/hub4-1/chip_downstream/PRT_D_P2: J1301.3 (D+); also elsewhere on the board
/hub4-1/chip_downstream/PRT_D_P3: J1401.2 (D-); also elsewhere on the board
/hub4-1/chip_downstream/PRT_D_P4: J1501.3 (D+); also elsewhere on the board
/hub4-1/chip_downstream/PRT_PWR2: U1301.4 (EN); also elsewhere on the board
/hub4-1/chip_downstream/PRT_PWR3: U1401.4 (EN); also elsewhere on the board
/hub4-1/chip_downstream/PRT_PWR4: U1501.4 (EN); also elsewhere on the board
GND: C1301.1, C1302.2, C1401.1, C1402.2, C1501.1, C1502.2, D1301.1 (K), D1401.1 (K), D1501.1 (K), J1301.4 (GND), J1301.5 (Shield), J1401.4 (GND), J1401.5 (Shield), J1501.4 (GND), J1501.5 (Shield), R1301.1, R1401.1, R1501.1, U1301.2 (GND), U1401.2 (GND), U1501.2 (GND); also elsewhere on the board
unnamed: D1301.2 (A), R1302.1
unnamed: D1401.2 (A), R1402.1
unnamed: D1501.2 (A), R1502.1
unnamed: C1302.1, J1301.1 (VBUS), R1302.2, U1301.1 (VOUT)
unnamed: C1402.1, J1401.1 (VBUS), R1402.2, U1401.1 (VOUT)
unnamed: C1502.1, J1501.1 (VBUS), R1502.2, U1501.1 (VOUT)
unnamed: R1301.2, U1301.3 (SET)
unnamed: R1401.2, U1401.3 (SET)
unnamed: R1501.2, U1501.3 (SET)

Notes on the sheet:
USB Plug
Datasheet Rset 10k corresponds to current limit of 0.6A

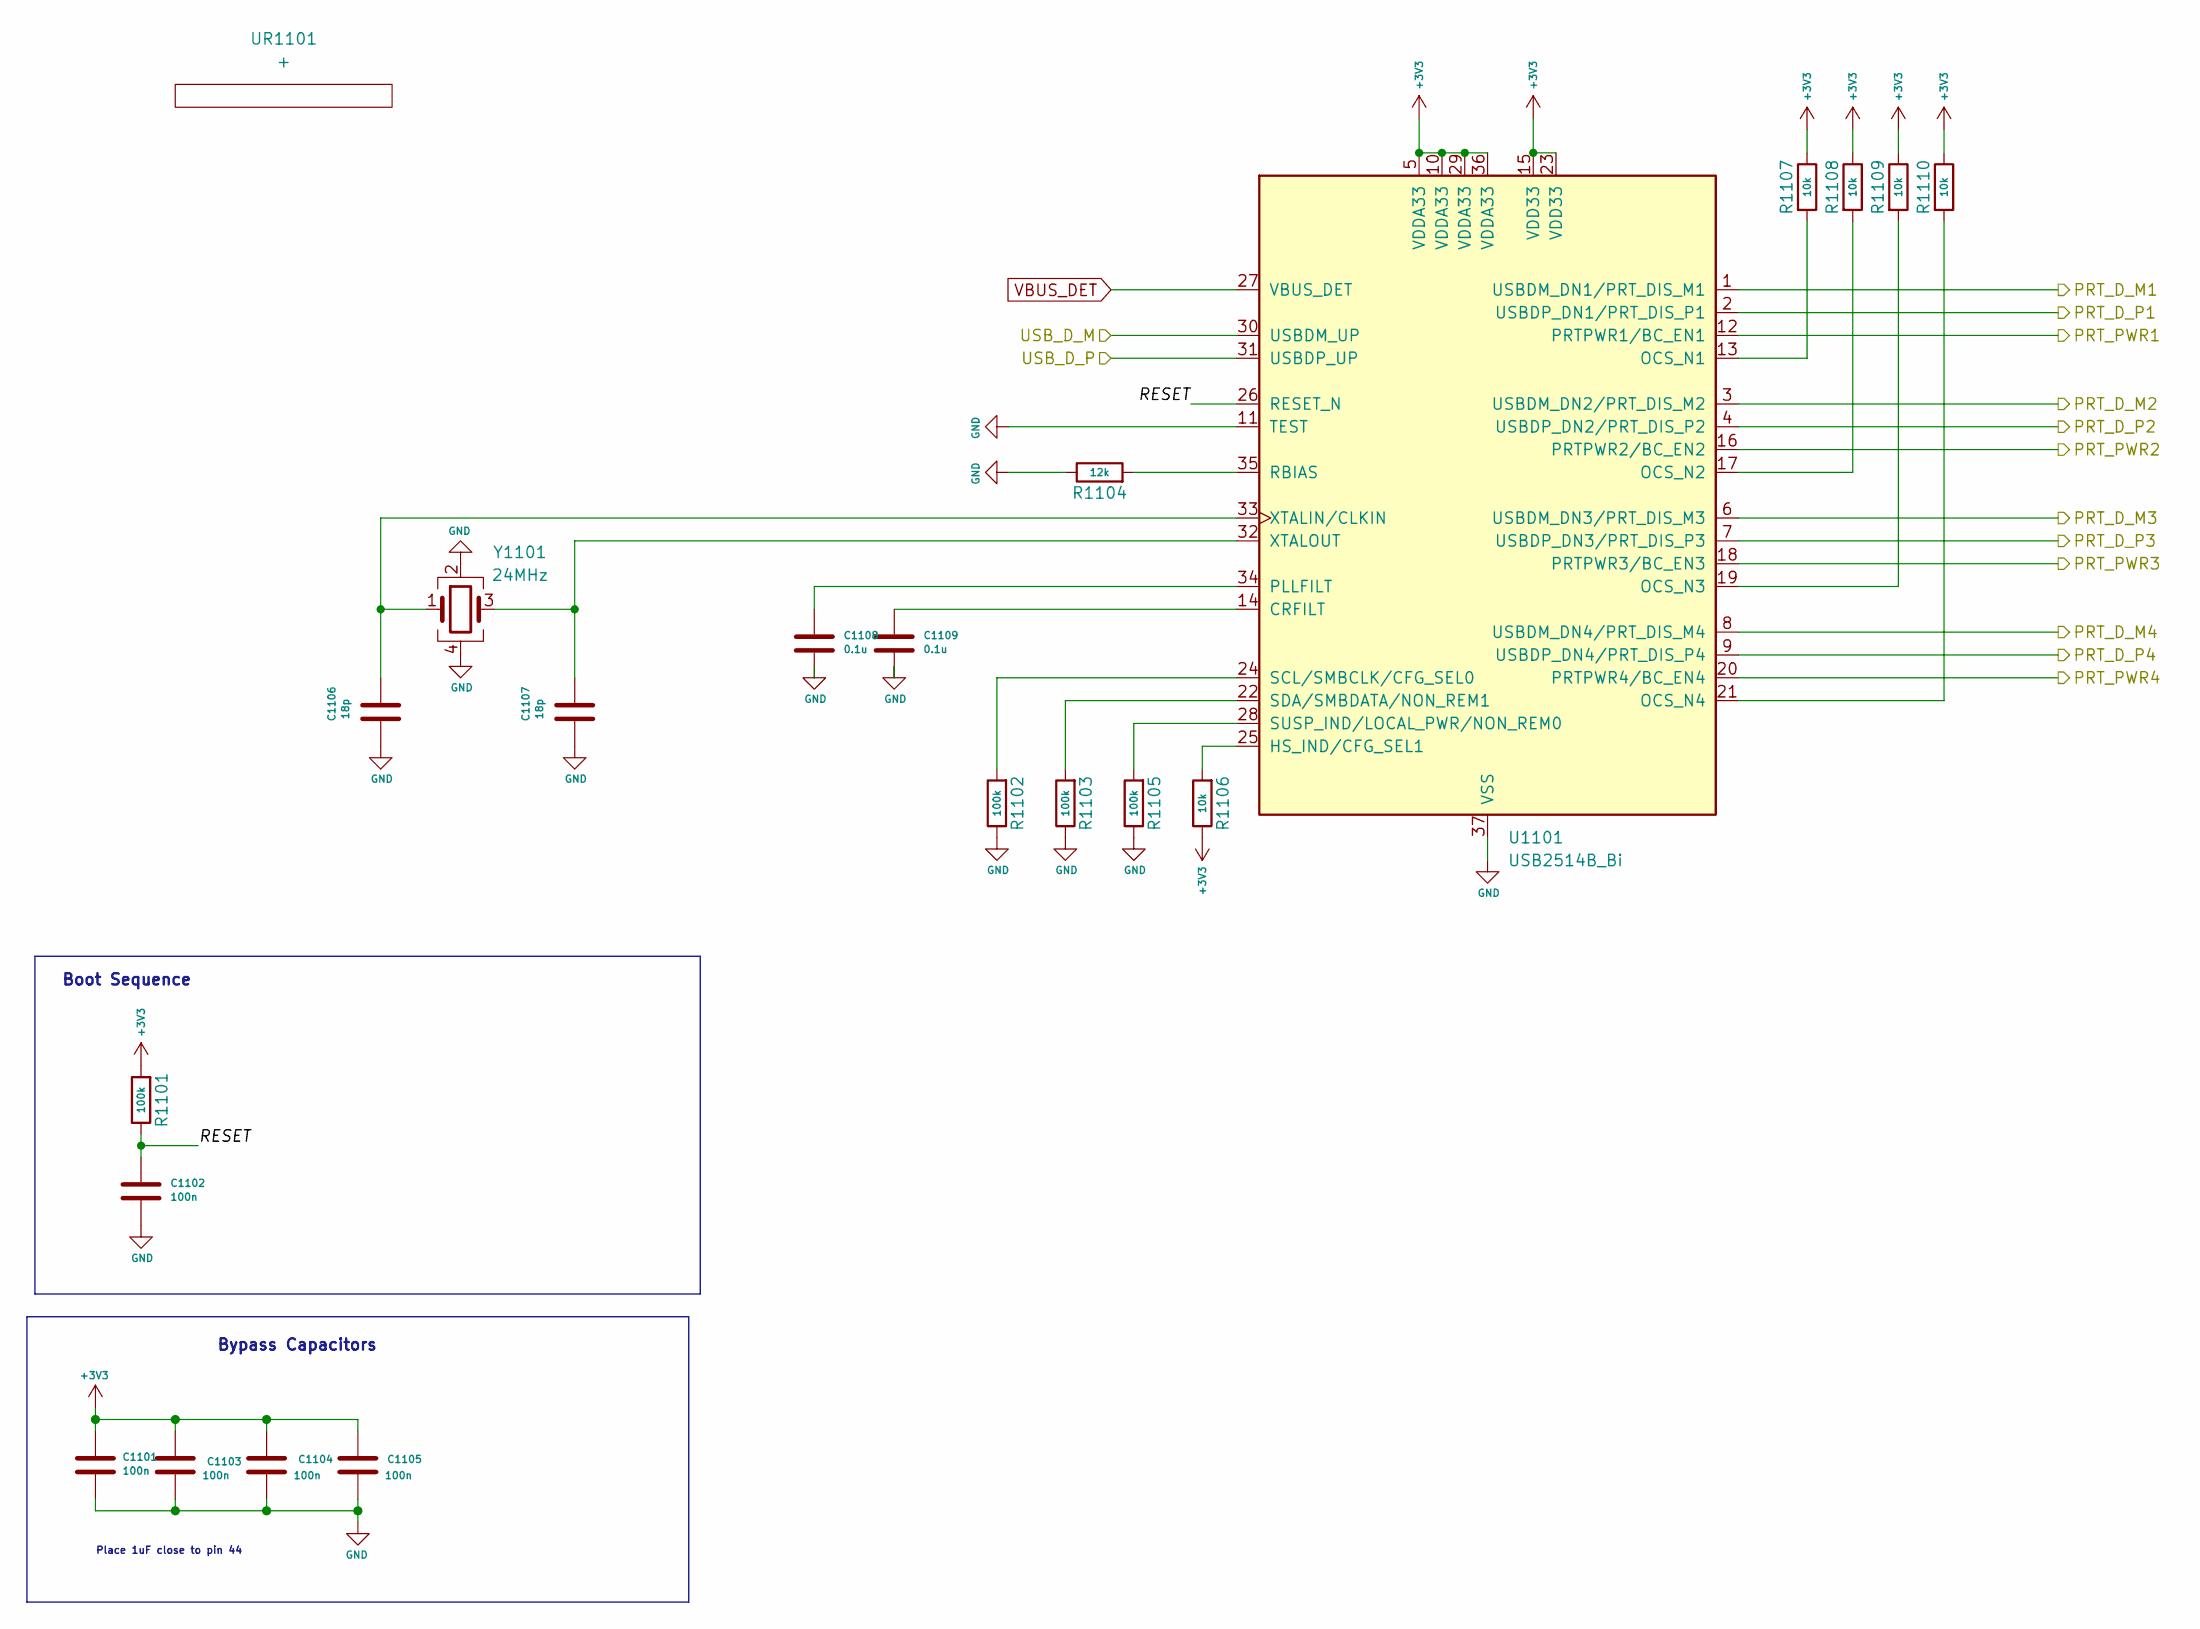
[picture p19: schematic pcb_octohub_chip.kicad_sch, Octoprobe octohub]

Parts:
C1101, C1103, C1104, C1105: 100n; C_0402_1005Metric
C1102: 100n; C_0603_1608Metric
C1106, C1107: 18p; C_0805_2012Metric; JLC C1797
C1108, C1109: 0.1u; C_0402_1005Metric
R1101, R1102, R1103, R1105: 100k; R_0402_1005Metric
R1104: 12k; R_0402_1005Metric
R1106, R1107, R1108, R1109, R1110: 10k; R_0402_1005Metric
U1101: USB2514B_Bi; Texas_RHH0036C_VQFN-36-1EP_6x6mm_P0.5mm_EP4.4x4.4mm_Thermal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; JLC C16251
UR1101: +; octohub_plug_top_left
Y1101: 24MHz; Crystal_SMD_3225-4Pin_3.2x2.5mm; JLC C70590

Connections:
+3V3: C1101.1, C1103.1, C1104.1, C1105.1, R1101.2, R1106.1, R1107.1, R1108.1, R1109.1, R1110.1, U1101.5 (VDDA33), U1101.10 (VDDA33), U1101.15 (VDD33), U1101.23 (VDD33), U1101.29 (VDDA33), U1101.36 (VDDA33); also elsewhere on the board
/USB_D+: U1101.31 (USBDP_UP); also elsewhere on the board
/USB_D-: U1101.30 (USBDM_UP); also elsewhere on the board
/hub4-1/chip_downstream/PRT_D_M1: U1101.1 (USBDM_DN1/PRT_DIS_M1); also elsewhere on the board
/hub4-1/chip_downstream/PRT_D_M2: U1101.3 (USBDM_DN2/PRT_DIS_M2); also elsewhere on the board
/hub4-1/chip_downstream/PRT_D_M3: U1101.6 (USBDM_DN3/PRT_DIS_M3); also elsewhere on the board
/hub4-1/chip_downstream/PRT_D_M4: U1101.8 (USBDM_DN4/PRT_DIS_M4); also elsewhere on the board
/hub4-1/chip_downstream/PRT_D_P1: U1101.2 (USBDP_DN1/PRT_DIS_P1); also elsewhere on the board
/hub4-1/chip_downstream/PRT_D_P2: U1101.4 (USBDP_DN2/PRT_DIS_P2); also elsewhere on the board
/hub4-1/chip_downstream/PRT_D_P3: U1101.7 (USBDP_DN3/PRT_DIS_P3); also elsewhere on the board
/hub4-1/chip_downstream/PRT_D_P4: U1101.9 (USBDP_DN4/PRT_DIS_P4); also elsewhere on the board
/hub4-1/chip_downstream/PRT_PWR1: U1101.12 (PRTPWR1/BC_EN1); also elsewhere on the board
/hub4-1/chip_downstream/PRT_PWR2: U1101.16 (PRTPWR2/BC_EN2); also elsewhere on the board
/hub4-1/chip_downstream/PRT_PWR3: U1101.18 (PRTPWR3/BC_EN3); also elsewhere on the board
/hub4-1/chip_downstream/PRT_PWR4: U1101.20 (PRTPWR4/BC_EN4); also elsewhere on the board
/hub4-1/chip_downstream/RESET: C1102.1, R1101.1, U1101.26 (RESET_N)
GND: C1101.2, C1102.2, C1103.2, C1104.2, C1105.2, C1106.2, C1107.2, C1108.2, C1109.2, R1102.1, R1103.1, R1104.1, R1105.1, U1101.11 (TEST), U1101.37 (VSS), Y1101.2, Y1101.4; also elsewhere on the board
unnamed: C1109.1, U1101.14 (CRFILT)
unnamed: R1106.2, U1101.25 (HS_IND/CFG_SEL1)
unnamed: R1107.2, U1101.13 (OCS_N1)
unnamed: R1108.2, U1101.17 (OCS_N2)
unnamed: R1109.2, U1101.19 (OCS_N3)
unnamed: R1110.2, U1101.21 (OCS_N4)
unnamed: C1108.1, U1101.34 (PLLFILT)
unnamed: R1104.2, U1101.35 (RBIAS)
unnamed: R1102.2, U1101.24 (SCL/SMBCLK/CFG_SEL0)
unnamed: R1103.2, U1101.22 (SDA/SMBDATA/NON_REM1)
unnamed: R1105.2, U1101.28 (SUSP_IND/LOCAL_PWR/NON_REM0)
unnamed: C1106.1, U1101.33 (XTALIN/CLKIN), Y1101.1
unnamed: C1107.1, U1101.32 (XTALOUT), Y1101.3
VBUS_DET: U1101.27 (VBUS_DET); also elsewhere on the board

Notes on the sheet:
Place 1uF close to pin 44
Bypass Capacitors
Boot Sequence

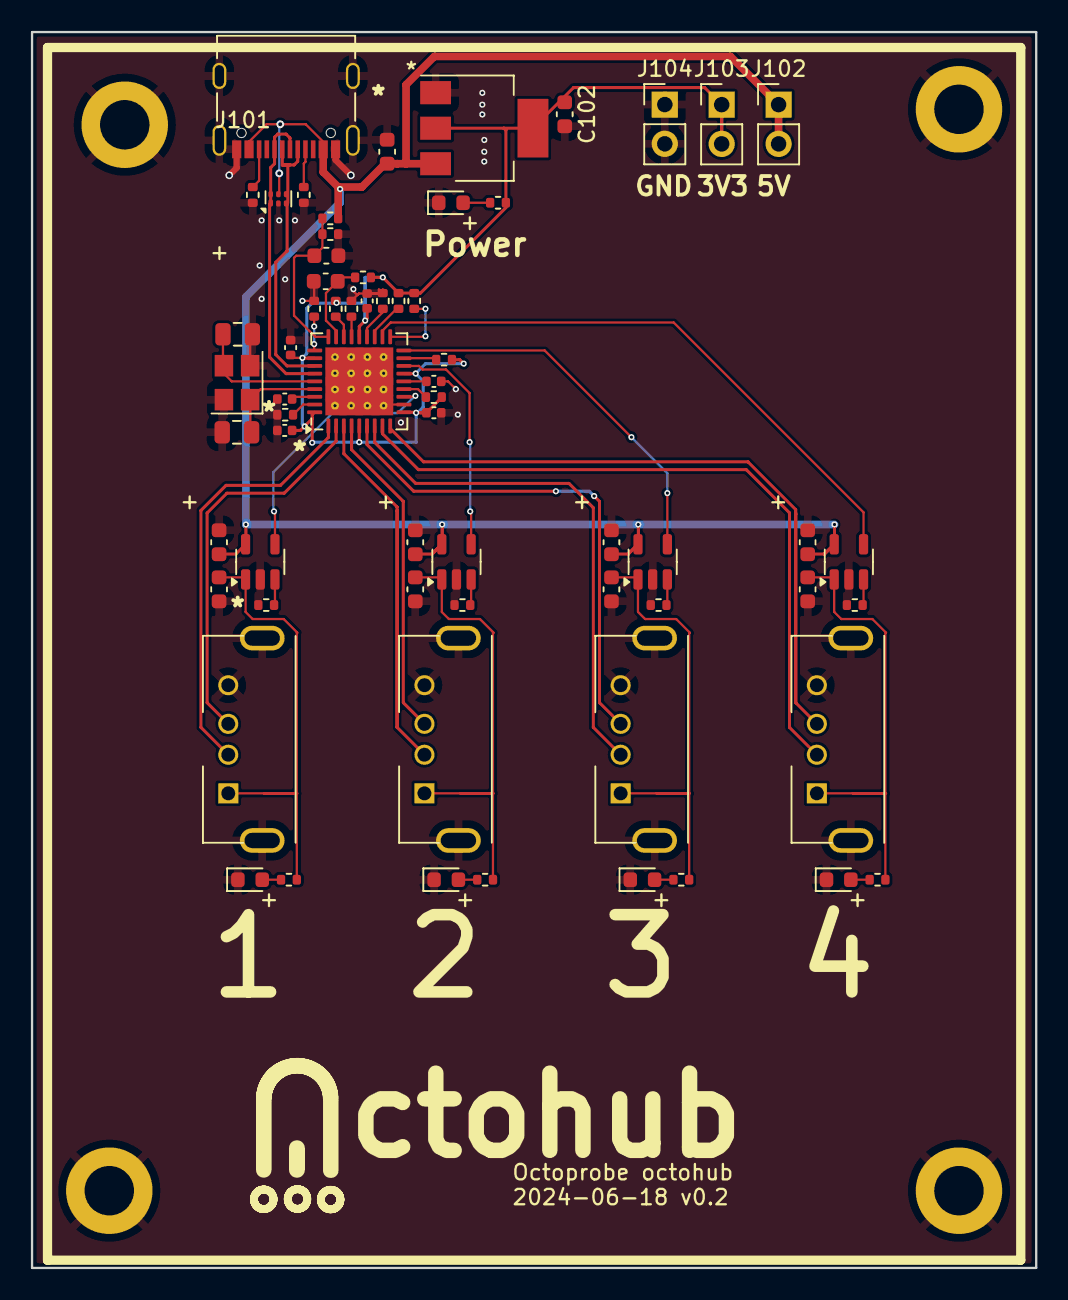
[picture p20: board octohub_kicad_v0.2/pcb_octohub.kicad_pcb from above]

Board: 2 copper layers, 65.0 x 80.0 mm, 77 parts (0 on the bottom side), 47 nets.

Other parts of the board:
H101, H102, H103, H104: octoprobe_MountingHole; MountingHole_3.2mm_M3_DIN965_Pad
UR1301: 2; octohub_plug_label
UR1401: 3; octohub_plug_label
UR1501: 4; octohub_plug_label

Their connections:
GND: H101.1, H102.1, H103.1, H104.1; also elsewhere on the board

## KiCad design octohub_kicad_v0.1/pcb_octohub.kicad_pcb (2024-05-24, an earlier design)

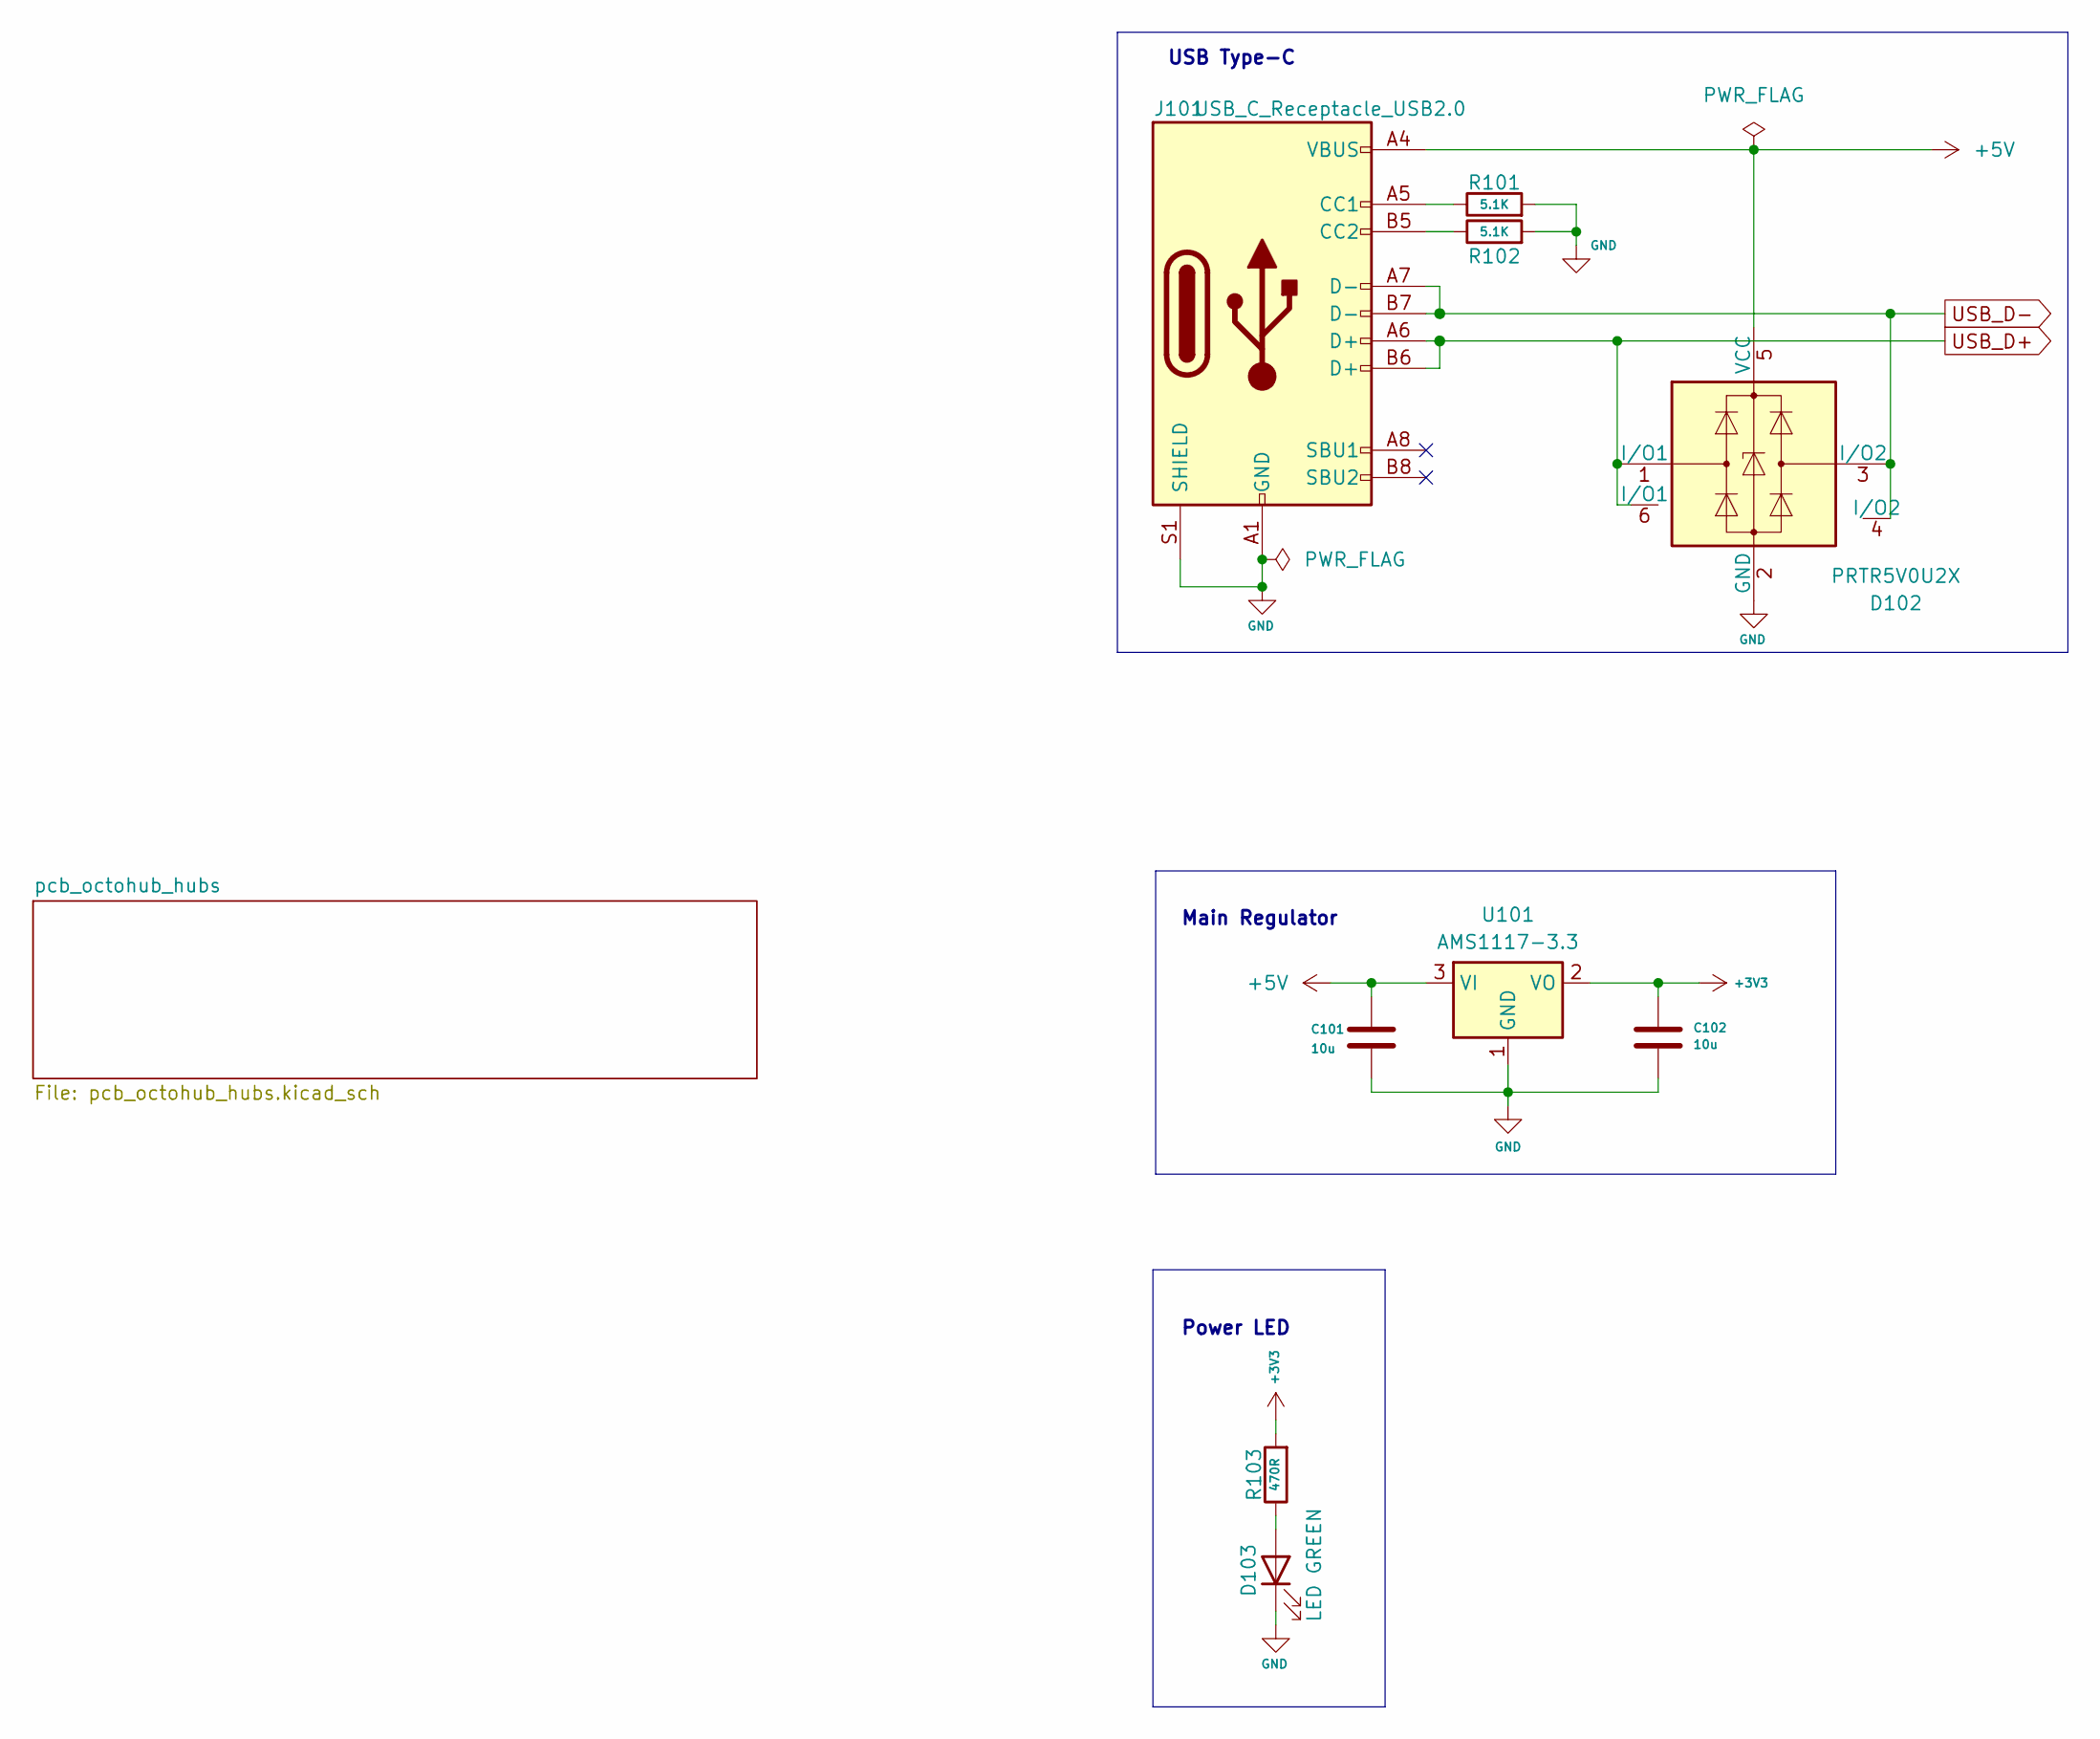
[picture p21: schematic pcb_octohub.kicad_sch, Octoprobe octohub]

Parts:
C101, C102: 10u; C_0603_1608Metric
D102: PRTR5V0U2X; Texas_USON-6_1x1.45mm_P0.5mm_SMD; JLC C2937001
D103: LED GREEN; LED_0603_1608Metric; JLC C2297
J101: USB_C_Receptacle_USB2.0; USB_C_Receptacle_Palconn_UTC16-G; JLC C165948
R101, R102: 5.1K; R_0402_1005Metric_Pad0.72x0.64mm_HandSolder
R103: 470R; R_0402_1005Metric_Pad0.72x0.64mm_HandSolder
U101: AMS1117-3.3; SOT-223-3_TabPin2; JLC C6186

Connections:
+3V3: C102.1, R103.2, U101.2 (VO); also elsewhere on the board
+5V: C101.1, D102.5 (VCC), J101.A4 (VBUS), J101.A9 (VBUS), J101.B4 (VBUS), J101.B9 (VBUS), U101.3 (VI); also elsewhere on the board
GND: C101.2, C102.2, D102.2 (GND), D103.1 (K), J101.A1 (GND), J101.A12 (GND), J101.B1 (GND), J101.B12 (GND), J101.S1 (SHIELD), R101.2, R102.2, U101.1 (GND); also elsewhere on the board
unnamed: D103.2 (A), R103.1
unnamed: J101.A5 (CC1), R101.1
unnamed: J101.B5 (CC2), R102.1
USB_D+: D102.1 (I/O1), D102.6 (I/O1), J101.A6 (D+), J101.B6 (D+); also elsewhere on the board
USB_D-: D102.3 (I/O2), D102.4 (I/O2), J101.A7 (D-), J101.B7 (D-); also elsewhere on the board

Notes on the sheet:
USB Type-C
Power LED
Main Regulator

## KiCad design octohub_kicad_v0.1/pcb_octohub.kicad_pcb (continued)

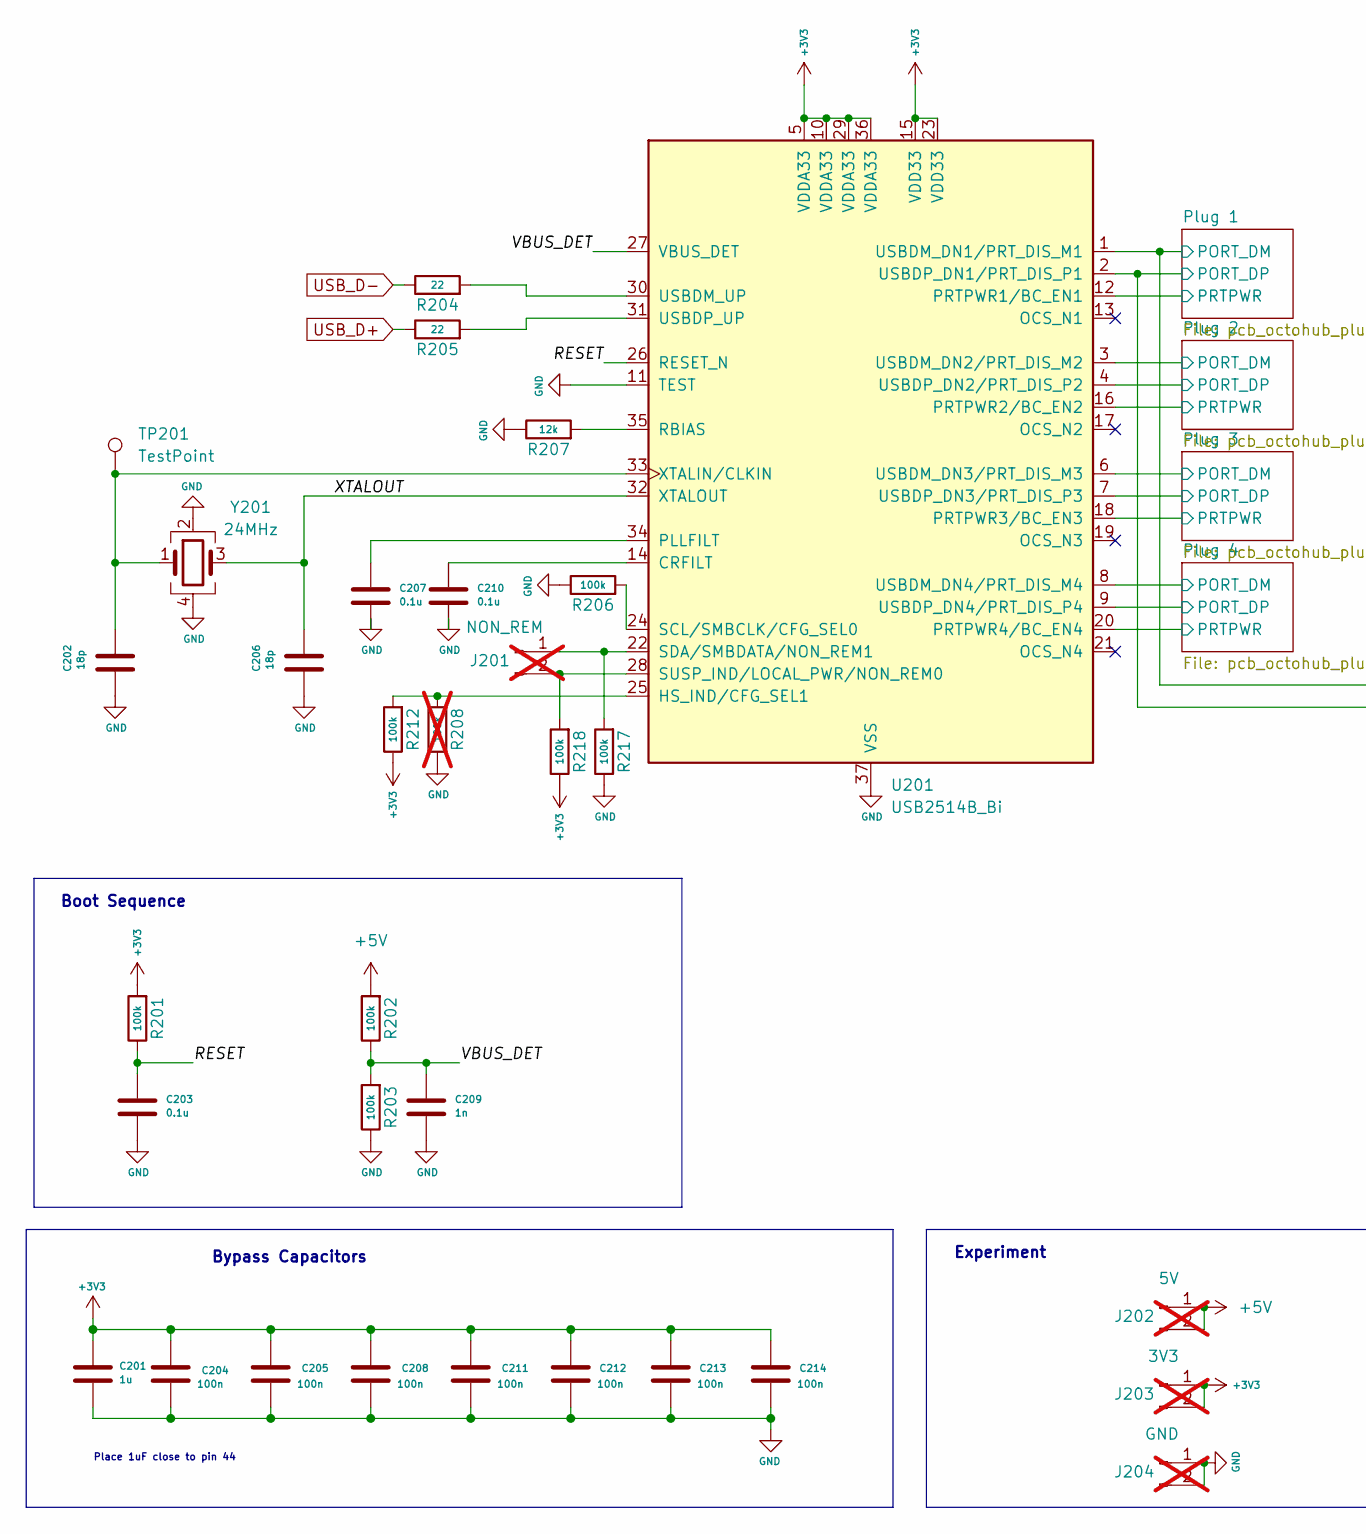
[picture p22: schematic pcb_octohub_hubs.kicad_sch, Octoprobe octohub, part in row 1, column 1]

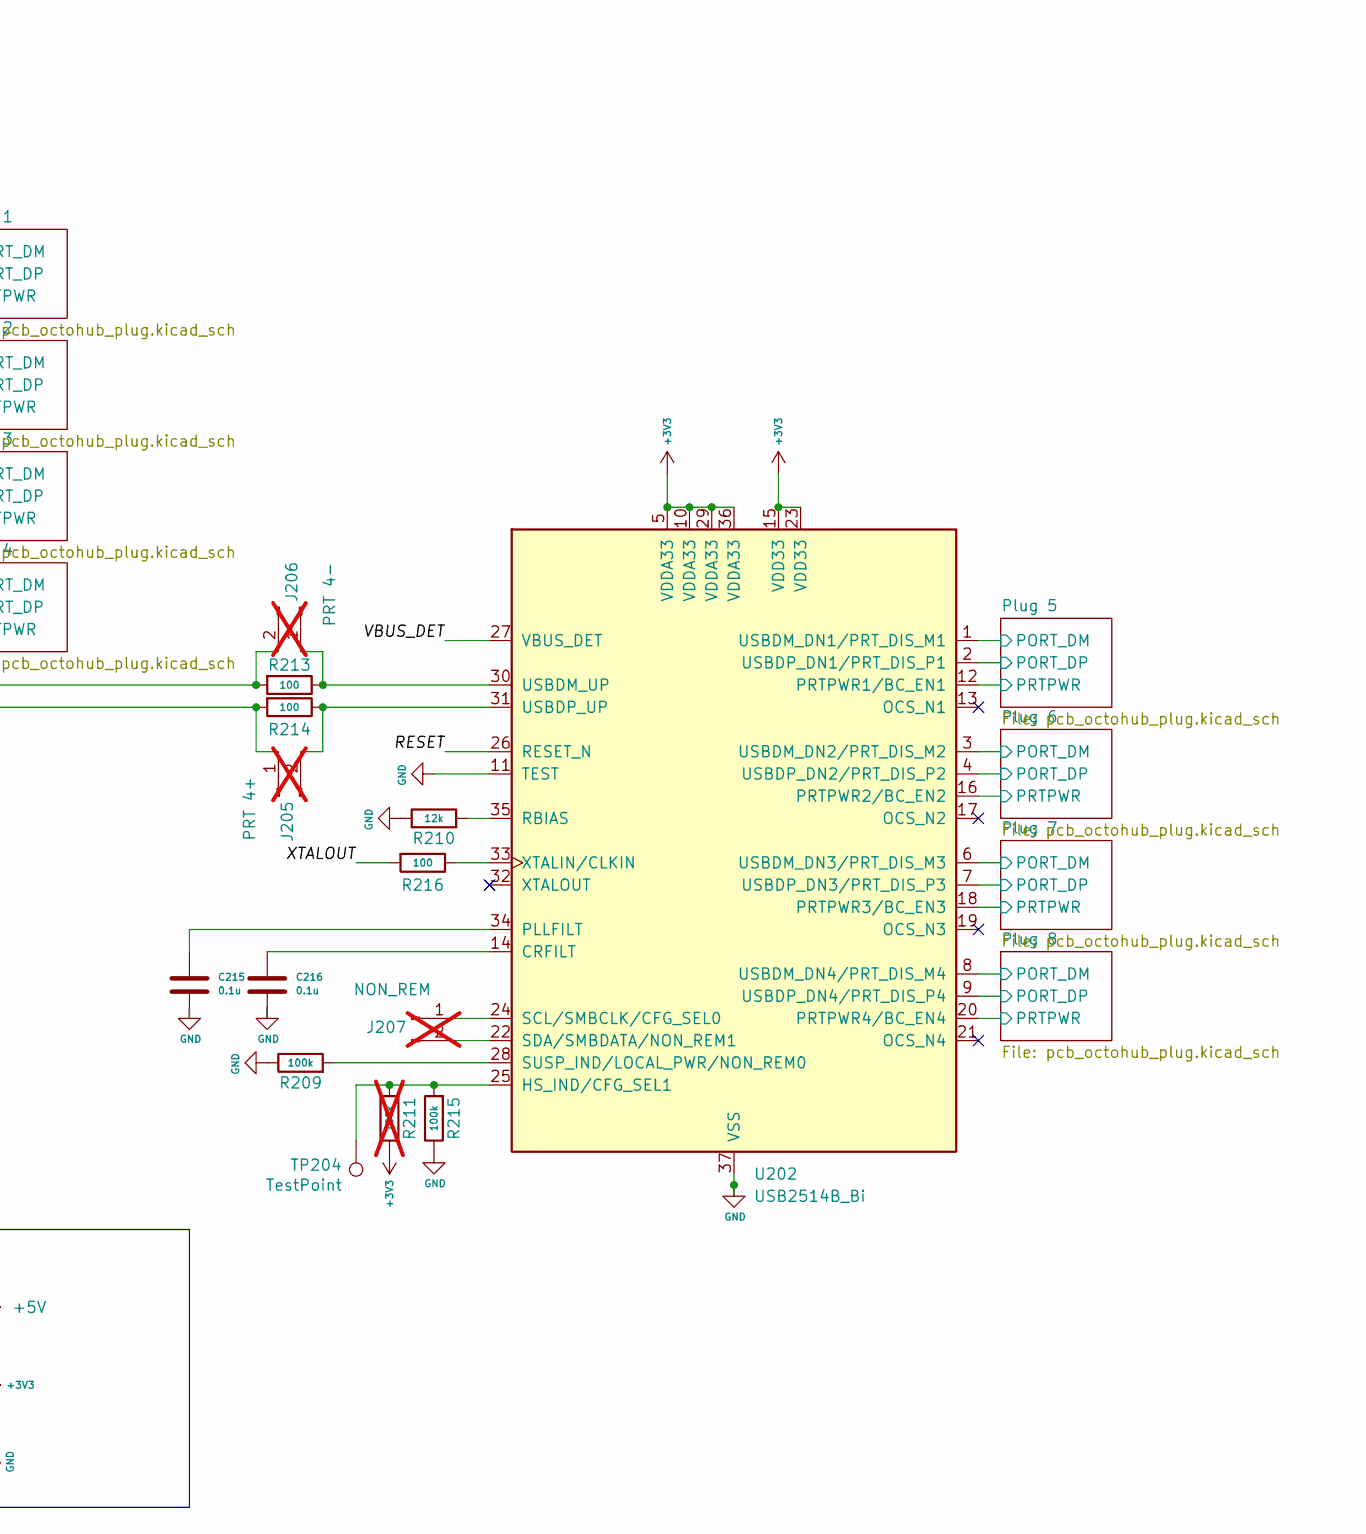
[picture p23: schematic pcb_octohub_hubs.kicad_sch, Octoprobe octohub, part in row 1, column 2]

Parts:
C201: 1u; C_0402_1005Metric_Pad0.74x0.62mm_HandSolder
C202, C206: 18p; C_0805_2012Metric; JLC C1797
C203, C207, C210, C215, C216: 0.1u; C_0603_1608Metric
C204, C205, C208, C211, C212, C213, C214: 100n; C_0402_1005Metric_Pad0.74x0.62mm_HandSolder
C209: 1n; C_0603_1608Metric
J201, J207: NON_REM; PinHeader_1x02_P2.54mm_Vertical; not fitted
J202: 5V; PinHeader_1x02_P2.54mm_Vertical; not fitted
J203: 3V3; PinHeader_1x02_P2.54mm_Vertical; not fitted
J204: GND; PinHeader_1x02_P2.54mm_Vertical; not fitted
J205: PRT 4+; PinHeader_1x02_P2.54mm_Vertical; not fitted
J206: PRT 4-; PinHeader_1x02_P2.54mm_Vertical; not fitted
R201, R202, R203, R206, R209, R212, R215, R217, R218: 100k; R_0402_1005Metric_Pad0.72x0.64mm_HandSolder
R204, R205: 22; R_0402_1005Metric_Pad0.72x0.64mm_HandSolder
R207, R210: 12k; R_0402_1005Metric_Pad0.72x0.64mm_HandSolder
R208, R211: 100k; R_0402_1005Metric_Pad0.72x0.64mm_HandSolder; not fitted
R213, R214, R216: 100; R_0402_1005Metric_Pad0.72x0.64mm_HandSolder
TP201, TP204: TestPoint; TestPoint_Pad_1.0x1.0mm
U201, U202: USB2514B_Bi; Texas_RHH0036C_VQFN-36-1EP_6x6mm_P0.5mm_EP4.4x4.4mm_Thermal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; JLC C16251
Y201: 24MHz; Crystal_SMD_3225-4Pin_3.2x2.5mm; JLC C70590

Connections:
+3V3: C201.1, C204.1, C205.1, C208.1, C211.1, C212.1, C213.1, C214.1, J203.1, J203.2, R201.2, R211.1, R212.1, R218.1, U201.5 (VDDA33), U201.10 (VDDA33), U201.15 (VDD33), U201.23 (VDD33), U201.29 (VDDA33), U201.36 (VDDA33), U202.5 (VDDA33), U202.10 (VDDA33), U202.15 (VDD33), U202.23 (VDD33), U202.29 (VDDA33), U202.36 (VDDA33); also elsewhere on the board
+5V: J202.1, J202.2, R202.2; also elsewhere on the board
/pcb_octohub_hubs/Plug 1/PORT_DM: J206.2, R213.2, U201.1 (USBDM_DN1/PRT_DIS_M1); also elsewhere on the board
/pcb_octohub_hubs/Plug 1/PORT_DP: J205.1, R214.2, U201.2 (USBDP_DN1/PRT_DIS_P1); also elsewhere on the board
/pcb_octohub_hubs/Plug 1/PRTPWR: U201.12 (PRTPWR1/BC_EN1); also elsewhere on the board
/pcb_octohub_hubs/Plug 2/PORT_DM: U201.3 (USBDM_DN2/PRT_DIS_M2); also elsewhere on the board
/pcb_octohub_hubs/Plug 2/PORT_DP: U201.4 (USBDP_DN2/PRT_DIS_P2); also elsewhere on the board
/pcb_octohub_hubs/Plug 2/PRTPWR: U201.16 (PRTPWR2/BC_EN2); also elsewhere on the board
/pcb_octohub_hubs/Plug 3/PORT_DM: U201.6 (USBDM_DN3/PRT_DIS_M3); also elsewhere on the board
/pcb_octohub_hubs/Plug 3/PORT_DP: U201.7 (USBDP_DN3/PRT_DIS_P3); also elsewhere on the board
/pcb_octohub_hubs/Plug 3/PRTPWR: U201.18 (PRTPWR3/BC_EN3); also elsewhere on the board
/pcb_octohub_hubs/Plug 4/PORT_DM: U201.8 (USBDM_DN4/PRT_DIS_M4); also elsewhere on the board
/pcb_octohub_hubs/Plug 4/PORT_DP: U201.9 (USBDP_DN4/PRT_DIS_P4); also elsewhere on the board
/pcb_octohub_hubs/Plug 4/PRTPWR: U201.20 (PRTPWR4/BC_EN4); also elsewhere on the board
/pcb_octohub_hubs/Plug 5/PORT_DM: U202.1 (USBDM_DN1/PRT_DIS_M1); also elsewhere on the board
/pcb_octohub_hubs/Plug 5/PORT_DP: U202.2 (USBDP_DN1/PRT_DIS_P1); also elsewhere on the board
/pcb_octohub_hubs/Plug 5/PRTPWR: U202.12 (PRTPWR1/BC_EN1); also elsewhere on the board
/pcb_octohub_hubs/Plug 6/PORT_DM: U202.3 (USBDM_DN2/PRT_DIS_M2); also elsewhere on the board
/pcb_octohub_hubs/Plug 6/PORT_DP: U202.4 (USBDP_DN2/PRT_DIS_P2); also elsewhere on the board
/pcb_octohub_hubs/Plug 6/PRTPWR: U202.16 (PRTPWR2/BC_EN2); also elsewhere on the board
/pcb_octohub_hubs/Plug 7/PORT_DM: U202.6 (USBDM_DN3/PRT_DIS_M3); also elsewhere on the board
/pcb_octohub_hubs/Plug 7/PORT_DP: U202.7 (USBDP_DN3/PRT_DIS_P3); also elsewhere on the board
/pcb_octohub_hubs/Plug 7/PRTPWR: U202.18 (PRTPWR3/BC_EN3); also elsewhere on the board
/pcb_octohub_hubs/Plug 8/PORT_DM: U202.8 (USBDM_DN4/PRT_DIS_M4); also elsewhere on the board
/pcb_octohub_hubs/Plug 8/PORT_DP: U202.9 (USBDP_DN4/PRT_DIS_P4); also elsewhere on the board
/pcb_octohub_hubs/Plug 8/PRTPWR: U202.20 (PRTPWR4/BC_EN4); also elsewhere on the board
/pcb_octohub_hubs/RESET: C203.1, R201.1, U201.26 (RESET_N), U202.26 (RESET_N)
/pcb_octohub_hubs/VBUS_DET: C209.1, R202.1, R203.2, U201.27 (VBUS_DET), U202.27 (VBUS_DET)
/pcb_octohub_hubs/XTALOUT: C206.1, R216.2, U201.32 (XTALOUT), Y201.3
GND: C201.2, C202.2, C203.2, C204.2, C205.2, C206.2, C207.2, C208.2, C209.2, C210.2, C211.2, C212.2, C213.2, C214.2, C215.2, C216.2, J204.1, J204.2, R203.1, R206.1, R207.1, R208.1, R209.1, R210.1, R215.1, R217.1, U201.11 (TEST), U201.37 (VSS), U202.11 (TEST), U202.37 (VSS), Y201.2, Y201.4; also elsewhere on the board
unnamed: J201.1, R217.2, U201.22 (SDA/SMBDATA/NON_REM1)
unnamed: J201.2, R218.2, U201.28 (SUSP_IND/LOCAL_PWR/NON_REM0)
unnamed: J205.2, R214.1, U202.31 (USBDP_UP)
unnamed: J206.1, R213.1, U202.30 (USBDM_UP)
unnamed: J207.1, U202.24 (SCL/SMBCLK/CFG_SEL0)
unnamed: J207.2, U202.22 (SDA/SMBDATA/NON_REM1)
unnamed: C210.1, U201.14 (CRFILT)
unnamed: R208.2, R212.2, U201.25 (HS_IND/CFG_SEL1)
unnamed: C207.1, U201.34 (PLLFILT)
unnamed: R207.2, U201.35 (RBIAS)
unnamed: R206.2, U201.24 (SCL/SMBCLK/CFG_SEL0)
unnamed: R204.2, U201.30 (USBDM_UP)
unnamed: R205.2, U201.31 (USBDP_UP)
unnamed: C202.1, TP201.1, U201.33 (XTALIN/CLKIN), Y201.1
unnamed: C216.1, U202.14 (CRFILT)
unnamed: R211.2, R215.2, TP204.1, U202.25 (HS_IND/CFG_SEL1)
unnamed: C215.1, U202.34 (PLLFILT)
unnamed: R210.2, U202.35 (RBIAS)
unnamed: R209.2, U202.28 (SUSP_IND/LOCAL_PWR/NON_REM0)
unnamed: R216.1, U202.33 (XTALIN/CLKIN)
USB_D+: R205.1; also elsewhere on the board
USB_D-: R204.1; also elsewhere on the board

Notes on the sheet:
Place 1uF close to pin 44
Experiment
Bypass Capacitors
Boot Sequence

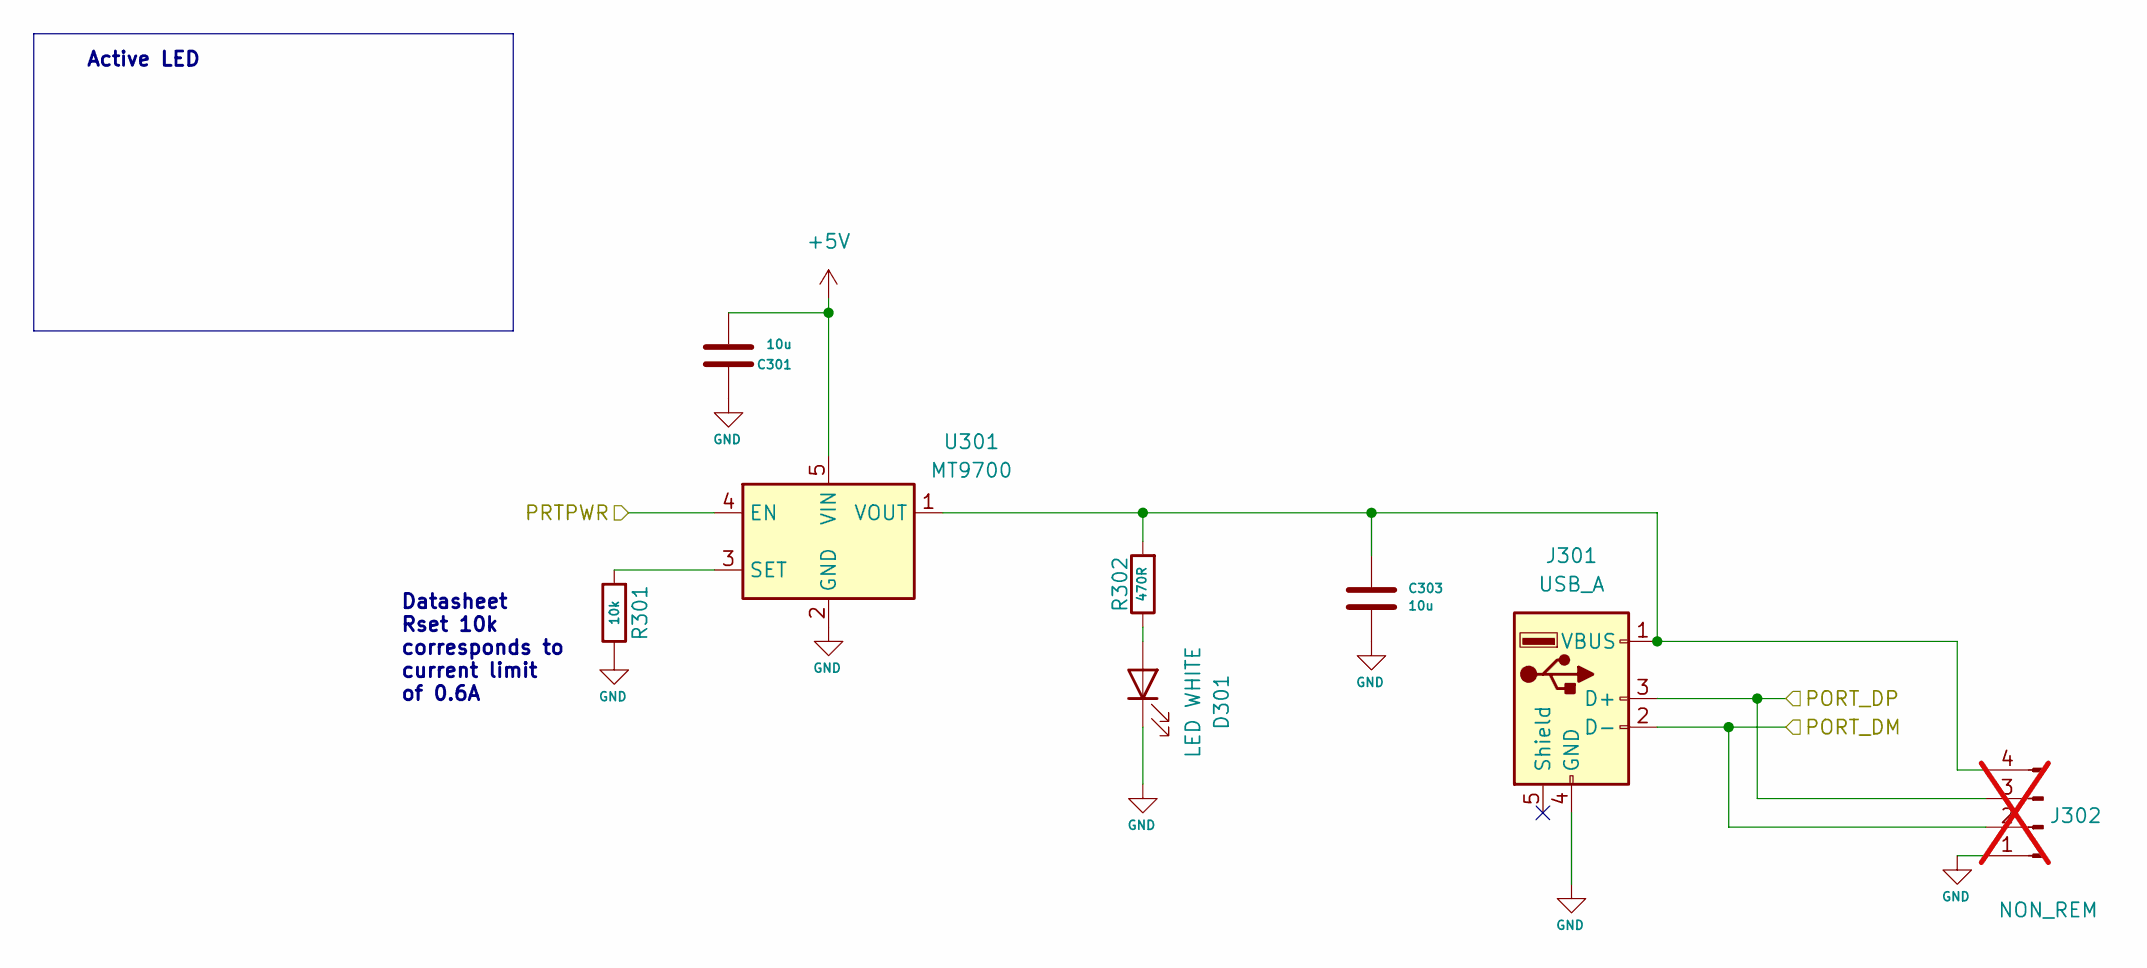
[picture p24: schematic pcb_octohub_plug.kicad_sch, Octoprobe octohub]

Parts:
C301, C303: 10u; C_0603_1608Metric
D301: LED WHITE; LED_0603_1608Metric; JLC C2290
J301: USB_A; USB_A_Molex_105057_Vertical; JLC C456015
J302: NON_REM; PinHeader_1x04_P2.54mm_Vertical; not fitted
R301: 10k; R_0402_1005Metric_Pad0.72x0.64mm_HandSolder
R302: 470R; R_0402_1005Metric_Pad0.72x0.64mm_HandSolder
U301: MT9700; SOT-23-5; JLC C89855

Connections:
+5V: C301.2, U301.5 (VIN); also elsewhere on the board
/pcb_octohub_hubs/Plug 1/PORT_DM: J301.2 (D-), J302.2; also elsewhere on the board
/pcb_octohub_hubs/Plug 1/PORT_DP: J301.3 (D+), J302.3; also elsewhere on the board
/pcb_octohub_hubs/Plug 1/PRTPWR: U301.4 (EN); also elsewhere on the board
GND: C301.1, C303.2, D301.1 (K), J301.4 (GND), J302.1, R301.1, U301.2 (GND); also elsewhere on the board
unnamed: D301.2 (A), R302.1
unnamed: C303.1, J301.1 (VBUS), J302.4, R302.2, U301.1 (VOUT)
unnamed: R301.2, U301.3 (SET)

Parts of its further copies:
C401, C403, C501, C503, C601, C603, C701, C703, C801, C803, C901, C903, C1001, C1003: 10u; C_0603_1608Metric
D401, D501, D601, D701, D801, D901, D1001: LED WHITE; LED_0603_1608Metric; JLC C2290
J401, J501, J601, J701, J801, J901, J1001: USB_A; USB_A_Molex_105057_Vertical; JLC C456015
J402, J502, J602, J702, J802, J902, J1002: NON_REM; PinHeader_1x04_P2.54mm_Vertical; not fitted
R401, R501, R601, R701, R801, R901, R1001: 10k; R_0402_1005Metric_Pad0.72x0.64mm_HandSolder
R402, R502, R602, R702, R802, R902, R1002: 470R; R_0402_1005Metric_Pad0.72x0.64mm_HandSolder
U401, U501, U601, U701, U801, U901, U1001: MT9700; SOT-23-5; JLC C89855

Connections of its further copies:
+5V: C401.2, C501.2, C601.2, C701.2, C801.2, C901.2, C1001.2, U401.5 (VIN), U501.5 (VIN), U601.5 (VIN), U701.5 (VIN), U801.5 (VIN), U901.5 (VIN), U1001.5 (VIN); also elsewhere on the board
/pcb_octohub_hubs/Plug 2/PORT_DM: J401.2 (D-), J402.2; also elsewhere on the board
/pcb_octohub_hubs/Plug 2/PORT_DP: J401.3 (D+), J402.3; also elsewhere on the board
/pcb_octohub_hubs/Plug 2/PRTPWR: U401.4 (EN); also elsewhere on the board
/pcb_octohub_hubs/Plug 3/PORT_DM: J501.2 (D-), J502.2; also elsewhere on the board
/pcb_octohub_hubs/Plug 3/PORT_DP: J501.3 (D+), J502.3; also elsewhere on the board
/pcb_octohub_hubs/Plug 3/PRTPWR: U501.4 (EN); also elsewhere on the board
/pcb_octohub_hubs/Plug 4/PORT_DM: J601.2 (D-), J602.2; also elsewhere on the board
/pcb_octohub_hubs/Plug 4/PORT_DP: J601.3 (D+), J602.3; also elsewhere on the board
/pcb_octohub_hubs/Plug 4/PRTPWR: U601.4 (EN); also elsewhere on the board
/pcb_octohub_hubs/Plug 5/PORT_DM: J701.2 (D-), J702.2; also elsewhere on the board
/pcb_octohub_hubs/Plug 5/PORT_DP: J701.3 (D+), J702.3; also elsewhere on the board
/pcb_octohub_hubs/Plug 5/PRTPWR: U701.4 (EN); also elsewhere on the board
/pcb_octohub_hubs/Plug 6/PORT_DM: J801.2 (D-), J802.2; also elsewhere on the board
/pcb_octohub_hubs/Plug 6/PORT_DP: J801.3 (D+), J802.3; also elsewhere on the board
/pcb_octohub_hubs/Plug 6/PRTPWR: U801.4 (EN); also elsewhere on the board
/pcb_octohub_hubs/Plug 7/PORT_DM: J901.2 (D-), J902.2; also elsewhere on the board
/pcb_octohub_hubs/Plug 7/PORT_DP: J901.3 (D+), J902.3; also elsewhere on the board
/pcb_octohub_hubs/Plug 7/PRTPWR: U901.4 (EN); also elsewhere on the board
/pcb_octohub_hubs/Plug 8/PORT_DM: J1001.2 (D-), J1002.2; also elsewhere on the board
/pcb_octohub_hubs/Plug 8/PORT_DP: J1001.3 (D+), J1002.3; also elsewhere on the board
/pcb_octohub_hubs/Plug 8/PRTPWR: U1001.4 (EN); also elsewhere on the board
GND: C401.1, C403.2, C501.1, C503.2, C601.1, C603.2, C701.1, C703.2, C801.1, C803.2, C901.1, C903.2, C1001.1, C1003.2, D401.1 (K), D501.1 (K), D601.1 (K), D701.1 (K), D801.1 (K), D901.1 (K), D1001.1 (K), J401.4 (GND), J402.1, J501.4 (GND), J502.1, J601.4 (GND), J602.1, J701.4 (GND), J702.1, J801.4 (GND), J802.1, J901.4 (GND), J902.1, J1001.4 (GND), J1002.1, R401.1, R501.1, R601.1, R701.1, R801.1, R901.1, R1001.1, U401.2 (GND), U501.2 (GND), U601.2 (GND), U701.2 (GND), U801.2 (GND), U901.2 (GND), U1001.2 (GND); also elsewhere on the board
unnamed: D401.2 (A), R402.1
unnamed: D501.2 (A), R502.1
unnamed: D601.2 (A), R602.1
unnamed: D701.2 (A), R702.1
unnamed: D801.2 (A), R802.1
unnamed: D901.2 (A), R902.1
unnamed: D1001.2 (A), R1002.1
unnamed: C403.1, J401.1 (VBUS), J402.4, R402.2, U401.1 (VOUT)
unnamed: C503.1, J501.1 (VBUS), J502.4, R502.2, U501.1 (VOUT)
unnamed: C603.1, J601.1 (VBUS), J602.4, R602.2, U601.1 (VOUT)
unnamed: C703.1, J701.1 (VBUS), J702.4, R702.2, U701.1 (VOUT)
unnamed: C803.1, J801.1 (VBUS), J802.4, R802.2, U801.1 (VOUT)
unnamed: C903.1, J901.1 (VBUS), J902.4, R902.2, U901.1 (VOUT)
unnamed: C1003.1, J1001.1 (VBUS), J1002.4, R1002.2, U1001.1 (VOUT)
unnamed: R401.2, U401.3 (SET)
unnamed: R501.2, U501.3 (SET)
unnamed: R601.2, U601.3 (SET)
unnamed: R701.2, U701.3 (SET)
unnamed: R801.2, U801.3 (SET)
unnamed: R901.2, U901.3 (SET)
unnamed: R1001.2, U1001.3 (SET)

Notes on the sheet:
Active LED
Datasheet Rset 10k corresponds to current limit of 0.6A

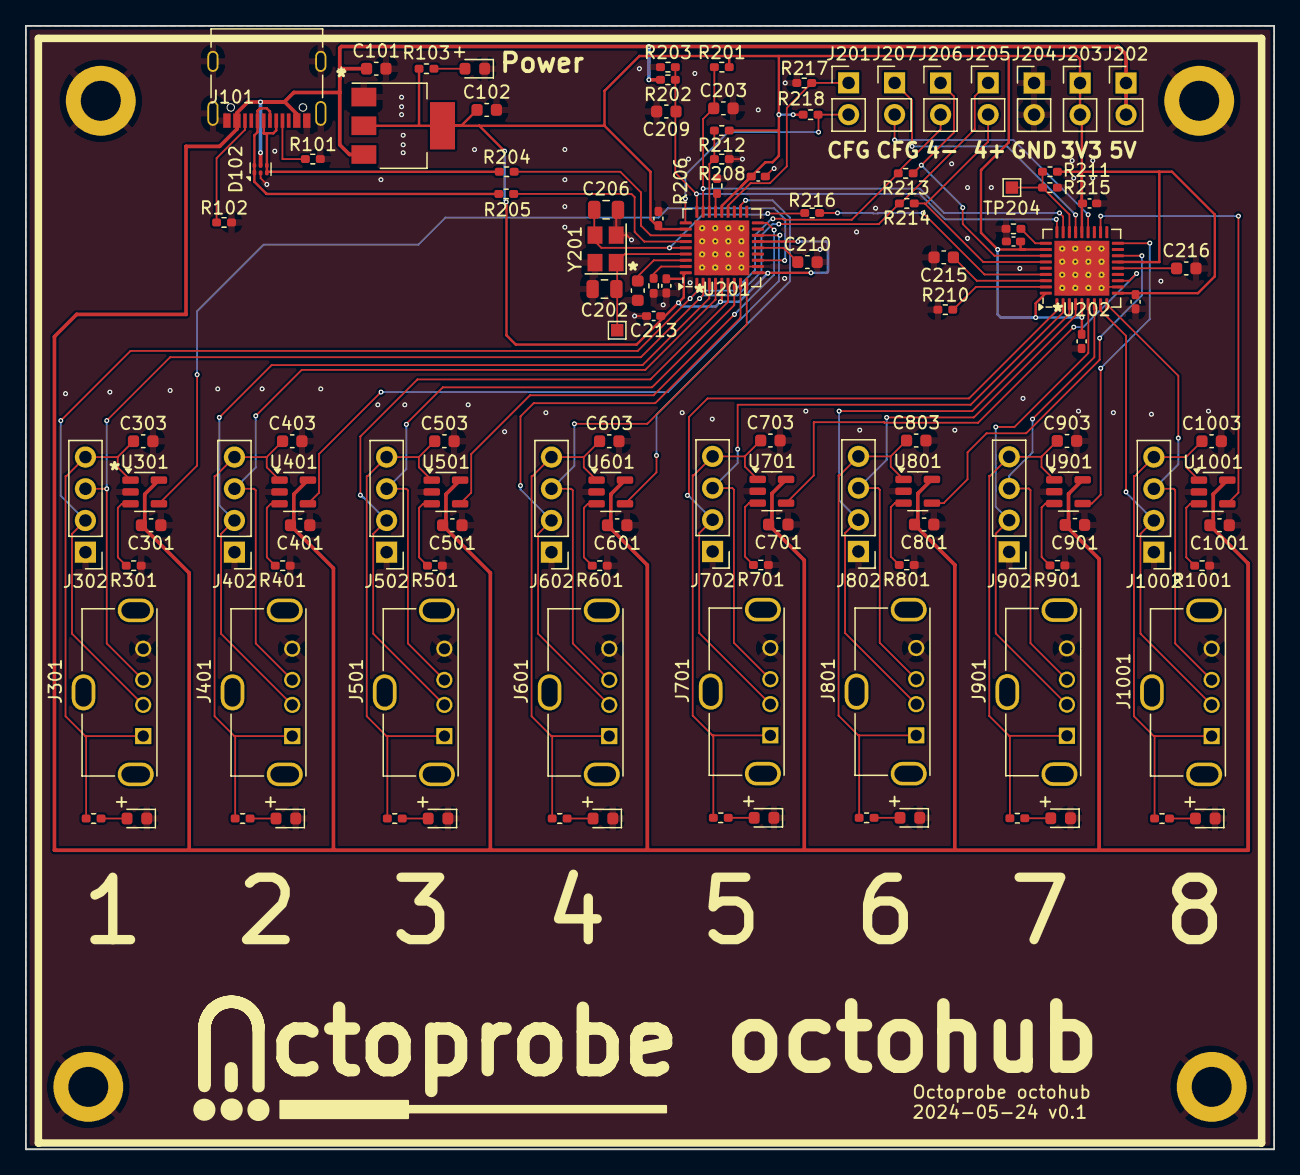
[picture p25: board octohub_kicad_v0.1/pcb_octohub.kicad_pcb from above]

Board: 2 copper layers, 100.0 x 90.0 mm, 123 parts (0 on the bottom side), 79 nets.

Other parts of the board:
H101, H102, H103, H104: octoprobe_MountingHole; MountingHole_3.2mm_M3_DIN965_Pad

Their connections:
GND: H101.1, H102.1, H103.1, H104.1; also elsewhere on the board

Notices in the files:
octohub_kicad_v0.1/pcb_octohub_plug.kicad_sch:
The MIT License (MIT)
